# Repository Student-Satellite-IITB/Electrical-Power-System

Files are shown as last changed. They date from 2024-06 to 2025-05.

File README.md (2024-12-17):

# ELECTRICAL POWER SYSTEM

This repository contains all software and hardware for the 
Electrical Power subsystem for the IITBSSP CubeSat mission

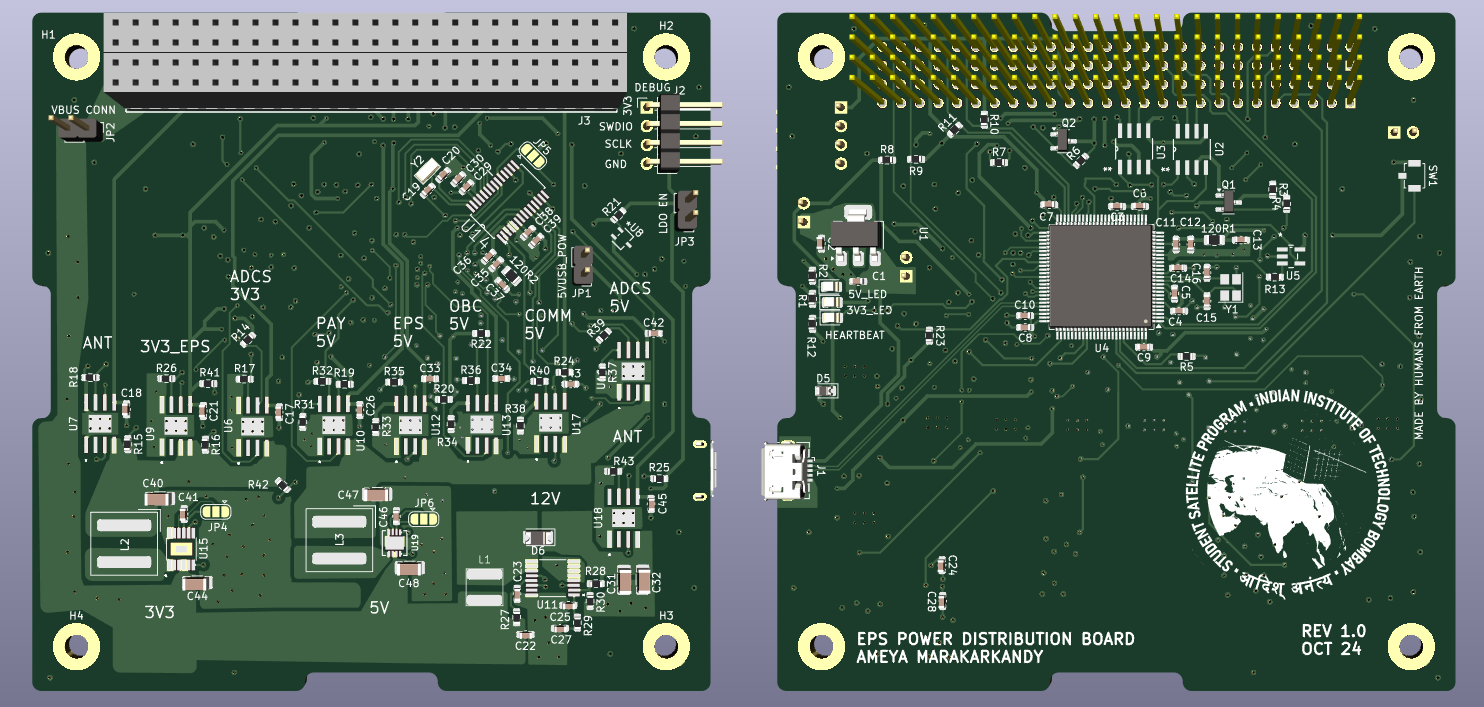
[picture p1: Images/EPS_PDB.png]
EPS Power Distribution Board


Current status: 
- EPS PDB and PMB Assembly
- Battery Unit Development Board
- Power Distribution and Regulation Development Board
- MATLAB/Simulink model of EPS in development
- Testing of Solar Input Development Board
- Testing of Control Unit Development Board

Completed:
- EPS PDB Board Design
- EPS PMB Board Design
- Solar Input Development Board
- EPS Control Unit Development Board

Maintained by:
- Ameya Marakarkandy <ameya.marakarkandy@gmail.com>
- Yash Paritkar <paritkary25@gmail.com>

[SSP Website](https://www.aero.iitb.ac.in/satlab/) | 
[Satellite 101 Wiki](https://www.aero.iitb.ac.in/satelliteWiki/index.php/Satellite_101)

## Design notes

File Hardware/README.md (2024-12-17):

# Electrical Power System Design and Analysis

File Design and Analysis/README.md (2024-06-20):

# Electrical Power System Design and Analysis

### Assumptions
- Mission Definition
- Mission Architecture
- Mission Requirements
### Satellite Preliminary Power Budget
### Power and Energy of Operational Models
### Energy of Scenario Operations
### Definition of Indicators
### EPS Validation

NOTE: This document is a work in progress

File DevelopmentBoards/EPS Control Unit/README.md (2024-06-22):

# EPS Solar Input Unit

Development Board Schematic and PCB Design is complete\
Have sent the PCB for manufacturing\
Yet to order components

Components:
- Molex pico pin connector for input from Solar Panels
- INA232 Current, Volage and Power Measurement with ADC

This document is a work in progress

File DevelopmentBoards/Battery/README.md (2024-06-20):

# EPS Battery Unit

Components:
- BQ29200 for Battery Protection and Cell Balancing
- BQ25713 for Battery Charging

This document is a work in progress

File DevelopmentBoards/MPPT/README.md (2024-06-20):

# EPS Maximum Power Point Tracking Unit

This document is a work in progress

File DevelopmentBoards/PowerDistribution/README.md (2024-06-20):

# EPS Power Regulation and Distribution Unit

This document is a work in progress

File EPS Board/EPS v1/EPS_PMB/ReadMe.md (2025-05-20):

This folder contains the Fusion file of the Power Management Board and the user manual for the testing.

# EPS_PMB_Testing_Manual
_Board Designed by Y.U.P., Oct 2024_

## Description
This PCB will be used as EPS Power Management Board. This board contains the MPPT, battery management and the battery heating unit. This PCB takes power input from the Solar Panels, performs maximum power point tracking and supplies this to the battery management system. Since this is a testing board, option to separate the solar power output and the BMS input is provided is provided.

## Errata
- The resistor R14 should be 137 kOhm.

### Solar Input Unit (SIU)
SIU is implemented with the help of LTC3130 DCDC converters. This IC also offers MPPC which can used as backup with the help of switches. P&O algorithm is used. The P is provided through the EPS uC (from the PDB board) - DAC - OpAmp - FB of the LTC3130. In order to sense the power of the panels, INA232, Current, Voltage and Power Monitor is used. The readings are sent to the EPS uC over the I2C.

All three INA232 have different I2C addresses, which are configured with the A0 pin.

### Battery Management Unit (BMU)
The battery management unit consists of two parts,

1. Battery Management System (BMS) deals with the electrical management of the battery, such as charging protection, OVP, OCP and cell balance.
2. Battery Heater System, which senses the battery temperature and sends the reading to EPS uC, which decides if the heater should be turned ON or OFF.

#### BMS
BMS is implemented with two ICs, BQ25713 I2C Narrow VDC (NVDC) Buck-Boost Battery Charge Controller and BQ29209 charge balancer. The NVDC allows the number of charge cycles of the battery to be minimised. They are implemented according to the standard layout.

#### Battery Heater
The battery temperature is sensed with the help of NTC, which will be attached to the battery and soldered on the board. This is done with a simple biasing circuit. The reading is sensed with ADS1110 and sent to the EPS uC over the I2C line.

The heating coil is wrapped over the battery, and the coil is powered with the VSYS voltage level, which is the BMS output. The coil is controlled with an N channel MOSFET, whose gate signal is received straight from the EPS uC.

### Switches on The Board
In order to allow better testing of the board, several solder switches are provided on the board, and the middle connection is the common terminal; one is '0', and the other is '1'.

The `BMS_SEP` is a jumper connection that separates the SIU and BMU.

> NOTE: Operate SW1 ↔ SW4, SW2 ↔ SW5, SW3 ↔ SW6 together to control the MPPT and MPPC mode.

In MPPC mode, the panels will output 12 V constant.

| Switch | 1 | 0 |
|---|---|---|
|SW1, SW4 | MPPC for 2S panel | MPPT for 2S panel |
|SW2, SW5 | MPPC for 6S panel | MPPT for 6S panel |
|SW3, SW6 | MPPC for 7S panel | MPPT for 7S panel |
|BAT_SEP | Shorted: SIU output shorted with BMU input |

## Testing Procedure

0. Understand the schematics and the layout of the board properly.
1. Do not solder board to the full at once. Solder only what you are testing and in parts.
2. Test the BMU and the SIU separately by keeping the BAT_SEP disconnected.
3. Remember to use the correct I2C addresses.

### Battery Heater Testing
1. Check the biasing of the NTC with the help of DMM.
2. Compare the temperature reading with a good reference.
3. Test the functioning of the ADS1110 IC.
4. Check the switching of the battery heater MOSFET with help of any digital logic.
5. Check the heating of the coil.

### BMU Testing
1. Test the BMU by supplying power with the bench supply of 12 V.
2. Check for features such as overcurrent protection and overvoltage protection.
3. Take readings of the different parameters of the battery with the help of I2C from BQ25713 and verify with the DMM.

### SIU Testing
1. Test the SIU in the MPPC configuration (All switches are low). Drain the power in some dummy load resistors.
2. Check the power generation in different power input levels with the help of the Solar Array Simulator.
3. Change the switch positions to the MPPT mode (All switches are high).
4. Implement the MPPT on a microcontroller and perform PILS.

### Cumulative testing
1. Upon successful testing of both SIU and BMU, short the BMS_SEP.
2. Perform and test for the power path management.

## Possible Failures
- Since the output of the multiple DCDC converters is shorted, this can cause possible instability in the system, and effects such as ringing can be seen.

## Improvements necessary for the next boards
- Addition of deployment switches
- After successful testing of the board, the switches can be eliminated to create a more streamlined board and have a more spacious layout.

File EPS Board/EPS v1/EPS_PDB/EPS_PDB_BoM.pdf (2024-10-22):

Reference | Value | Footprint | Qty | MANUFACTURER_PART_NUMBER DIGIKEY_PART_NUMBER | Price | Total
120R1,120R2 | FerriteBead | Resistor_SMD:R_0805_2012Metric | 2 HI0805O121R-10 | 240-2393-1-ND | ₹ 19.28 | 38.56
C1,C2 | 22uF | Capacitor_SMD:C_0603_1608Metric | 2 | 0
C3,C29,C38 | 10uF | Capacitor_SMD:C_0603_1608Metric | 3 | 0
C4,C5,C6,C7,C8,C9,C10,C14 | 100nF | Capacitor_SMD:C_0603_1608Metric | 8 | 0
C11,C28,C35 | 10nF | Capacitor_SMD:C_0603_1608Metric | 3 | 0
C12,C13,C17,C18,C21,C26,C33,C34,C36,C37,C42,C43 | 1uF | Capacitor_SMD:C_0603_1608Metric | 12 | 0
C15,C16,C19,C20 | 10pF | Capacitor_SMD:C_0603_1608Metric | 4 | 0
C22 | 4.7uF | Capacitor_SMD:C_0603_1608Metric | 1 | 0
C23 | 0.47uF | Capacitor_SMD:C_0603_1608Metric | 1 | 0
C24 | 0.1uF | Capacitor_SMD:C_0603_1608Metric | 1 | 0
C25 | 100pF | Capacitor_SMD:C_0603_1608Metric | 1 | 0
C27 | 3300pF | Capacitor_SMD:C_0603_1608Metric | 1 | 0
C30,C39 | C | Capacitor_SMD:C_0603_1608Metric | 2 | 0
C31,C32 | 4.7uF | Capacitor_SMD:C_1206_3216Metric | 2 | 0
C40,C47 | 47uF | Capacitor_SMD:C_1206_3216Metric | 2 | 0
C41,C46 | 2.2uF | Capacitor_SMD:C_0603_1608Metric | 2 | 0
C44,C48 | 10uF | Capacitor_SMD:C_1206_3216Metric | 2 | 0
C45 | 1uF | Capacitor_SMD:C_1206_3216Metric | 1 | 0
D1 | EPS_5V_LED | LED_SMD:LED_0805_2012Metric | 1 | 0
D2 | EPS_3V3_LED | LED_SMD:LED_0805_2012Metric | 1 | 0
D3 | EPS_LED | LED_SMD:LED_0805_2012Metric | 1 | 0
D4,D5 | D_Schottky | Diode_SMD:D_0805_2012Metric | 2 | 0
D6 | D | Diode_SMD:D_1206_3216Metric | 1 | 0
H1,H2,H3,H4 | MountingHole_Pad | MountingHole:MountingHole_3.2mm_M3_Pad | 4 | 0
J1 | USB_B_Micro | Connector_USB:USB_Micro-B_GCT_USB3076-30-A | 1 USB3076-30-A | 2073-USB3076-30-ACT-ND | ₹ 70.43 | 70.43
J2 | Conn_01x04_Pin | Connector_PinHeader_2.54mm:PinHeader_1x04_P2.54mm_Horizontal | 1 | 0
J3,J4 | Conn_02x26_Odd_Even | PC104_BUS:SAMTEC_ESQ-126-39-G-D | 2 | 0
JP1,JP3 | USB_POW_EN | Connector_PinHeader_2.54mm:PinHeader_1x02_P2.54mm_Vertical | 2 | 0
JP2 | Jumper_2_Bridged | Connector_PinHeader_2.54mm:PinHeader_1x02_P2.54mm_Vertical | 1 | 0
L1 | 8.2uH | Inductor-WE-XHMI-5050:WE-XHMI-5050 | 1 744393305082 | 732-744393305082CT-ND | ₹ 265.77 | 265.77
L2,L3 | 2.2uH | Inductor_SMD:L_Wuerth_WE-XHMI-8080 | 2 74439358022 | 732-7274-1-ND | ₹ 393.21 | 786.42
Q1,Q2 | PMOS | Package_TO_SOT_SMD:SOT-23-3 | 2 BSR92PH6327XTSA1 | BSR92PH6327XTSA1CT-ND | ₹ 46.11 | 92.22
R1,R2,R8,R9,R10,R11,R12 | 1k5 | Resistor_SMD:R_0603_1608Metric | 7 | 0
R3,R6 | 100k | Resistor_SMD:R_0603_1608Metric | 2 | 0
R4,R7 | 100 Resistor_SMD:R_0603_1608Metric | 2 | 0
R5,R14,R15,R16,R18,R19,R20,R22,R23,R24,R25,R41,R42 | 10k | Resistor_SMD:R_0603_1608Metric | 13 | 0
R13 | 0 Resistor_SMD:R_0603_1608Metric | 1 | 0
R17,R26 | 2.2k | Resistor_SMD:R_0603_1608Metric | 2 | 0
R21,R28 | 130k | Resistor_SMD:R_0603_1608Metric | 2 | 0
R27 | 10 Resistor_SMD:R_0603_1608Metric | 1 | 0
R29 | 18k | Resistor_SMD:R_0603_1608Metric | 1 | 0
R30 | 15k | Resistor_SMD:R_0603_1608Metric | 1 | 0
R31,R33,R34,R37,R38 | 400k | Resistor_SMD:R_0603_1608Metric | 5 | 0
R32 | 510 Resistor_SMD:R_0603_1608Metric | 1 | 0
R35,R39,R43 | 560 Resistor_SMD:R_0603_1608Metric | 3 | 0
R36,R40 | 1.3k | Resistor_SMD:R_0603_1608Metric | 2 | 0
SW1 | SW_SPDT | Button_Switch_SMD:SW_SPST_B3U-1100P | 1 B3U-1100P | SW1021CT-ND | ₹ 71.26 | 71.26
U1 | AMS1117-3.3 | Package_TO_SOT_SMD:SOT-223-3_TabPin2 | 1 AMS1117-3.3 | 5272-AMS1117-3.3CT-ND | ₹ 48.63 | 48.63
U2,U3 | SN65HVD256D | SN65HVD256D:D8 | 2 SN65HVD256D | 296-33577-5-ND | ₹ 200.38 | 400.76
U4 | STM32L476VET6 | Package_QFP:LQFP-100_14x14mm_P0.5mm | 1 STM32L476VET6 | 497-15878-ND | ₹ 649.76 | 649.76
U5 | TPS3824-33QDBVRQ1 | TPS3824:tps3824 | 1 TPS3824-33QDBVRQ1 | 296-TPS3824-33QDBVRQ1CT-ND | ₹ 122.41 | 122.41
U6 | TPS259621DDAT 3V3_ADCS TPS259621DDAT:IC_TPS259621DDAT | 1 TPS259621DDAT | 296-TPS259621DDATCT-ND | ₹ 90.55 | 90.55
U7 | TPS259621DDAT_3V3_ANT TPS259621DDAT:IC_TPS259621DDAT | 1 TPS259621DDAT | 296-TPS259621DDATCT-ND | ₹ 90.55 | 90.55
U8 | TS4061BICT-1.25 | TS4061BICT:SOT323-3L_1P35X2P2X0P65_STM | 1 TS4061BICT-1.25 | 497-15526-1-ND | ₹ 81.32 | 81.32
U9 | TPS259621DDAT_3V3_EPS | TPS259621DDAT:IC_TPS259621DDAT | 1 TPS259621DDAT | 296-TPS259621DDATCT-ND | ₹ 90.55 | 90.55
U10 | TPS259621DDAT_5V_PAY | TPS259621DDAT:IC_TPS259621DDAT | 1 TPS259621DDAT | 296-TPS259621DDATCT-ND | ₹ 90.55 | 90.55
U11 | LM5000-3MTCX | LM500:SOP65P640X120-16N | 1 LM5000-3MTCX/NOPB | 296-35284-1-ND | ₹ 441.00 | 441
U12 | TPS259621DDAT_5V_EPS | TPS259621DDAT:IC_TPS259621DDAT | 1 TPS259621DDAT | 296-TPS259621DDATCT-ND | ₹ 90.55 | 90.55
U13 | TPS259621DDAT_5V_OBC | TPS259621DDAT:IC_TPS259621DDAT | 1 TPS259621DDAT | 296-TPS259621DDATCT-ND | ₹ 90.55 | 90.55
U14 | AD7708BRUZ | AD7708BRUZ:SOP65P638X110-28N | 1 AD7708BRUZ | AD7708BRUZ-ND | ₹ 1,167.05 1167.05
U15 | LTC3624EMSE-3.3PBF | LTC3624EMSE-3.3PBF:SOP65P490X110-13N | 1 LTC3624EMSE-3.3#PBF | LTC3624EMSE-3.3#PBF-ND | ₹ 856.84 | 856.84
U16 | TPS259621DDAT_5V_ADCS | TPS259621DDAT:IC_TPS259621DDAT | 1 TPS259621DDAT | 296-TPS259621DDATCT-ND | ₹ 90.55 | 90.55
U17 | TPS259621DDAT_5V_COMM TPS259621DDAT:IC_TPS259621DDAT | 1 TPS259621DDAT | 296-TPS259621DDATCT-ND | ₹ 90.55 | 90.55
U18 | TPS259621DDAT_12V_ADCS TPS259621DDAT:IC_TPS259621DDAT | 1 TPS259621DDAT | 296-TPS259621DDATCT-ND | ₹ 90.55 | 90.55
U19 | LTC3624IDD-25PBF | LTC3624IDD-25PBF:DFN-8_DD | 1 LTC3624IDD-25#PBF | LTC3624IDD-25#PBF-ND | ₹ 921.40 | 921.4
Y1 | 32MHz | Crystal:Crystal_SMD_Abracon_ABM8AIG-4Pin_3.2x2.5mm | 1 ABM8X-102-32.000MHZ-T | 535-11454-1-ND | ₹ 561.73 | 561.73
Y2 | 32.768kHz | Crystal:Crystal_SMD_3215-2Pin_3.2x1.5mm | 1 ABS07-32.768KHZ-T | 535-9542-1-ND | ₹ 54.50 | 54.5
7445.01

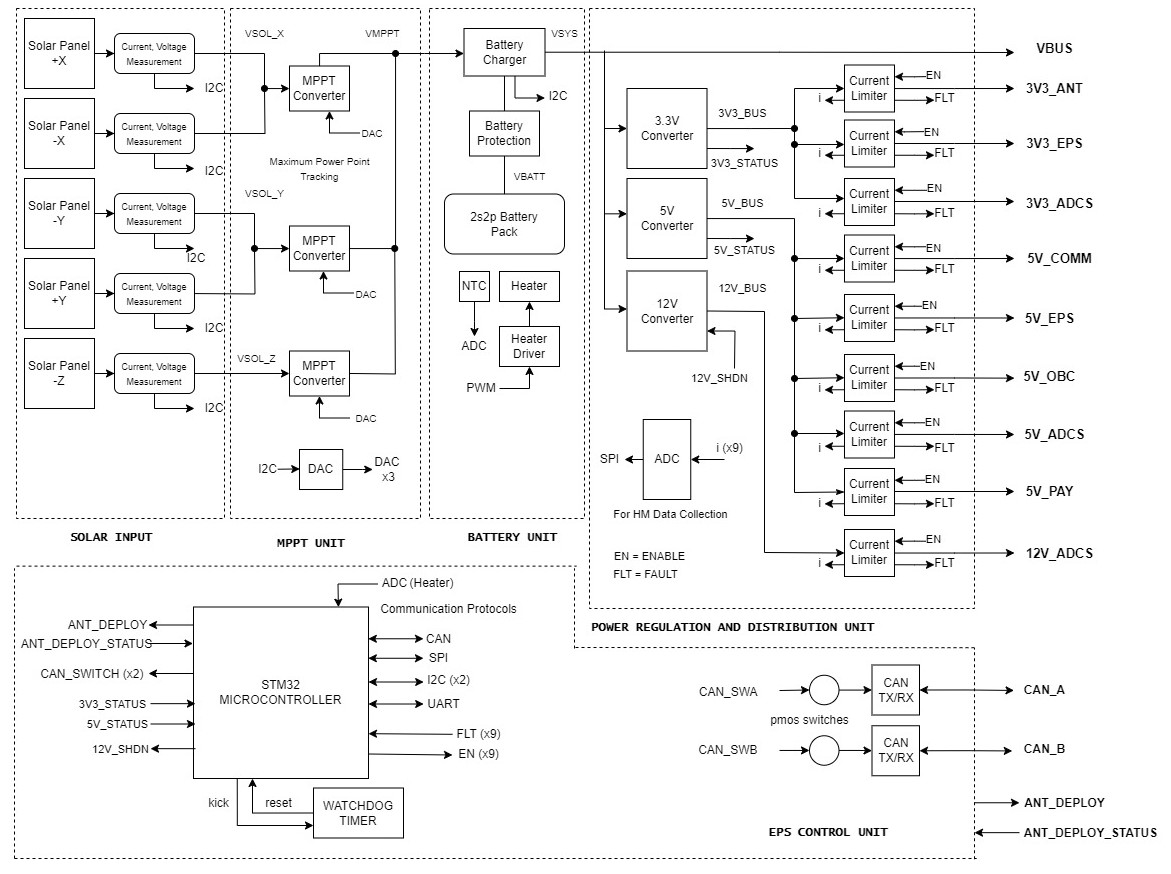
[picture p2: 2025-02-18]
Images/EPS_Architecture.jpg

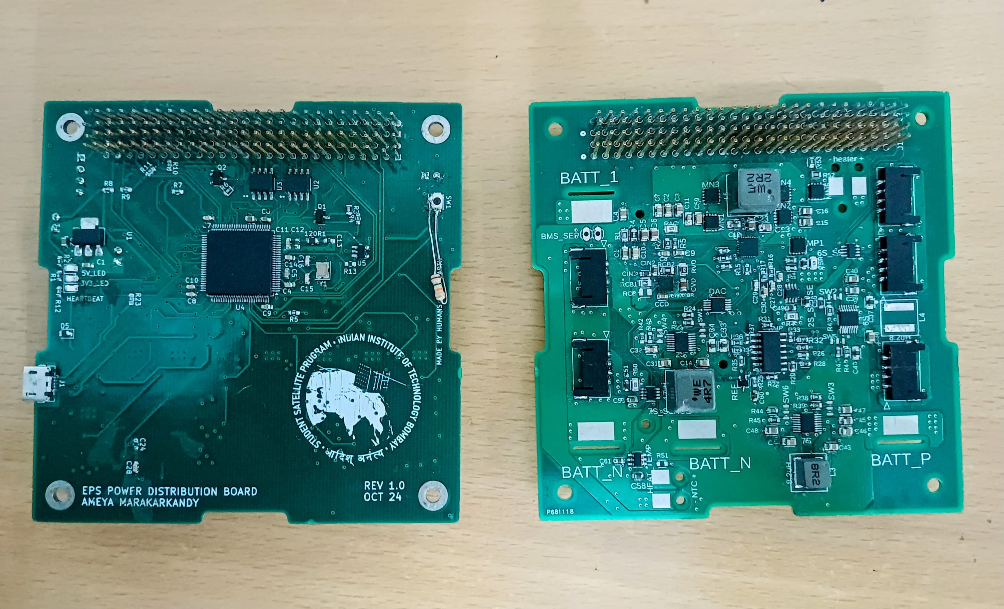
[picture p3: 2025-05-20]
Images/EPS_Boards.jpg

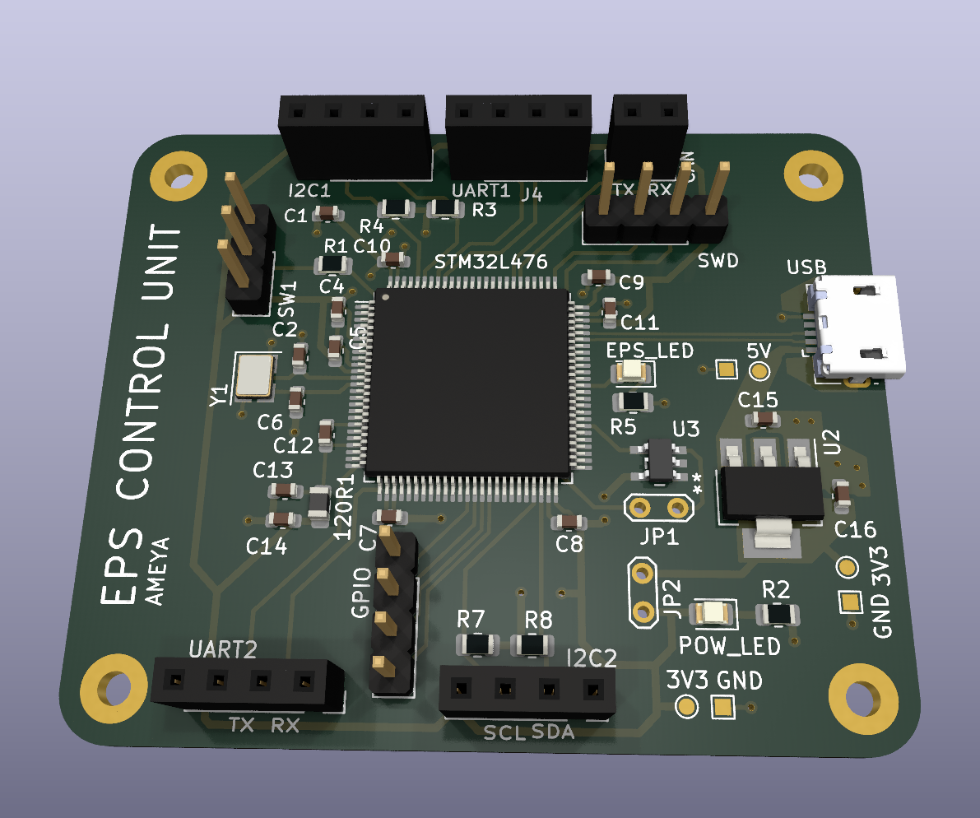
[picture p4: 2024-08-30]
Images/EPS_ControlUnit.png

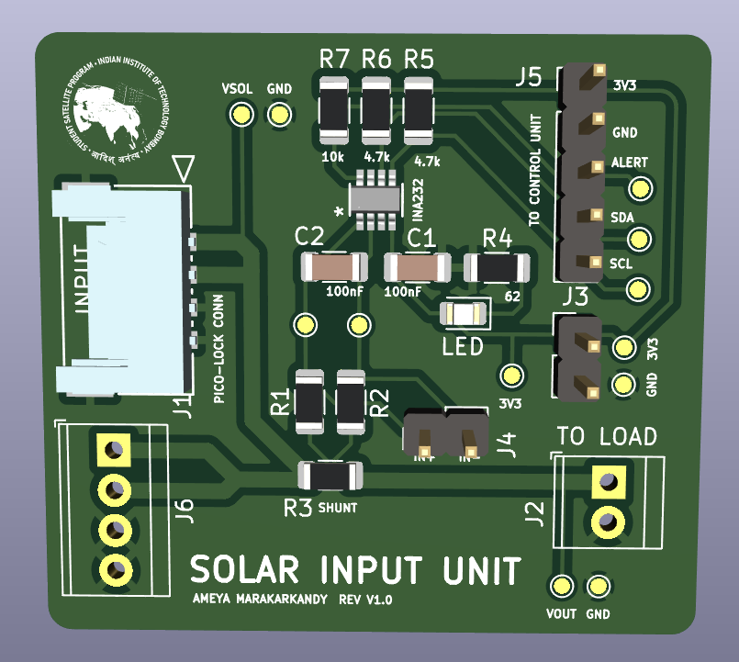
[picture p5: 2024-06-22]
Images/EPS_SolarInput.png

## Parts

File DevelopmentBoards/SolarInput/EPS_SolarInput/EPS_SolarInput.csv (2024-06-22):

Source: | C:\Users\Ameya\Documents\IITBSSP\GitHub\Electrical-Power-System\DevelopmentBoards\SolarInput\EPS_SolarInput\EPS_SolarInput.kicad_sch
Date: | 23-06-2024 03:58
Tool: | Eeschema 7.0.2
Generator: | C:\Program Files\KiCad\7.0\bin\scripting\plugins/bom_csv_grouped_by_value.py
Component Count: | 29
Collated Components:
Item | Qty | Reference(s) | Value | LibPart | Footprint | Price | Total Price | Link
1 | 2 | C1, C2 | 100nF | Device:C | Capacitor_SMD:C_1206_3216Metric | 30.5 | 61 | https://in.element14.com/murata/gcj31cr72e104kxj3l/cap-0-10uf-250vdc-mlcc-1206/dp/3243156
2 | 1 | D1 | LED | Device:LED | LED_SMD:LED_0805_2012Metric | 34 | 34 | https://in.element14.com/lumex/sml-lxt0805syw-tr/led-yell-1-4x1-25mm-60mcd-590nm/dp/2062311
3 | 1 | J1 | 2053380004 | Molex-Pico-Lock-Conn:2053380004 | Molex-PicoLock_FootprintLib:CON_2053380004 |  | 0
4 | 1 | J2 | Screw_Terminal_01x02 | Connector:Screw_Terminal_01x02 | TerminalBlock_TE-Connectivity:TerminalBlock_TE_282834-2_1x02_P2.54mm_Horizontal |  | 0
5 | 2 | J3, J4 | Conn_01x02_Socket | Connector:Conn_01x02_Socket | Connector_PinHeader_2.54mm:PinHeader_1x02_P2.54mm_Vertical |  | 0
6 | 1 | J5 | Conn_01x05_Pin | Connector:Conn_01x05_Pin | Connector_PinHeader_2.54mm:PinHeader_1x05_P2.54mm_Vertical |  | 0
7 | 1 | J6 | Screw_Terminal_01x04 | Connector:Screw_Terminal_01x04 | TerminalBlock_TE-Connectivity:TerminalBlock_TE_282834-4_1x04_P2.54mm_Horizontal |  | 0
8 | 2 | R1, R2 | <100 | Device:R | Resistor_SMD:R_1206_3216Metric |  | 0
9 | 1 | R3 | 40m | Device:R | Resistor_SMD:R_1206_3216Metric |  | 0
10 | 1 | R4 | 62 | Device:R | Resistor_SMD:R_1206_3216Metric |  | 0
11 | 2 | R5, R6 | 4.7k | Device:R | Resistor_SMD:R_1206_3216Metric |  | 0
12 | 1 | R7 | 10k | Device:R | Resistor_SMD:R_1206_3216Metric |  | 0
13 | 12 | TP1, TP2, TP3, TP4, TP5, TP6, TP7, TP8, TP9, TP10, TP11, TP12 | TestPoint | Connector:TestPoint | TestPoint:TestPoint_Pad_D1.0mm |  | 0
14 | 1 | U1 | INA232AIDDFR | EPS_SymbolLib:INA232AIDDFR | INA232_FootprintLib:SOT_32AIDDFR_TEX |  | 0

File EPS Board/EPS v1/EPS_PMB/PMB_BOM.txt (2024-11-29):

Partlist exported from C:/Users/harsh/AppData/Local/Temp/Neutron/ElectronFileOutput/9460/sch-f3af5b30-faf7-4b7a-940b-98f68ccd31e9/PMB v1.sch at 25-11-2024 19:25

Part      Value                                        Device                                       Footprint Name                Detailed Description       AVAILABILITY CATEGORY  CHECK_PRICES                                                                   COPYRIGHT                                                DATASHEET-URL                                           DESCRIPTION                                                                             FRES  IRP    ISAT1  ISAT2      MANUFACTURER MANUFACTURER_PART_NUMBER MF                MFR_NAME                    MOUNT MP          MPN     OPERATING_TEMP OPERATING_TEMPERATURE PACKAGE                  PART-NUMBER   PART_STATUS PITCH           PRICE PURCHASE-URL                                                                                                                                       RATING RDC      ROHS_COMPLIANCE ROHS_COMPLIANT SERIES  SIZE   SNAPEDA_LINK                                                                    SUB-CATEGORY       THERMALLOSS TOLERANCE TYPE                                                        VALUE     VOLTAGE_RATING
2S        LTC3130EMSEPBFMSE_16_ADI-M                   LTC3130EMSEPBFMSE_16_ADI-M                   MSE_16_ADI-M                                                                                                                                                   Copyright (C) 2024 Ultra Librarian. All rights reserved.                                                                                                                                                                                             LTC3130EMSE#PBF                            Analog Devices Inc                                                                                                                                                                                                                                                                                                                                                                                                                                                                                                                                                                                
2S_0      2053380004CON_2053380004                     2053380004CON_2053380004                     CON_2053380004                                                                                                                                                 Copyright (C) 2024 Ultra Librarian. All rights reserved.                                                                                                                                                                                             2053380004                                 Molex Connector Corporation                                                                                                                                                                                                                                                                                                                                                                                                                                                                                                                                                                       
2S_1      2053380004CON_2053380004                     2053380004CON_2053380004                     CON_2053380004                                                                                                                                                 Copyright (C) 2024 Ultra Librarian. All rights reserved.                                                                                                                                                                                             2053380004                                 Molex Connector Corporation                                                                                                                                                                                                                                                                                                                                                                                                                                                                                                                                                                       
2S_SENSE  INA232AIDDFRSOT_32AIDDFR_TEX-M               INA232AIDDFRSOT_32AIDDFR_TEX-M               SOT_32AIDDFR_TEX-M                                                                                                                                             Copyright (C) 2024 Ultra Librarian. All rights reserved.                                                                                                                                                                                             INA232AIDDFR                               Texas Instruments                                                                                                                                                                                                                                                                                                                                                                                                                                                                                                                                                                                 
6S        LTC3130EMSEPBFMSE_16_ADI-M                   LTC3130EMSEPBFMSE_16_ADI-M                   MSE_16_ADI-M                                                                                                                                                   Copyright (C) 2024 Ultra Librarian. All rights reserved.                                                                                                                                                                                             LTC3130EMSE#PBF                            Analog Devices Inc                                                                                                                                                                                                                                                                                                                                                                                                                                                                                                                                                                                
6S_0      2053380004CON_2053380004                     2053380004CON_2053380004                     CON_2053380004                                                                                                                                                 Copyright (C) 2024 Ultra Librarian. All rights reserved.                                                                                                                                                                                             2053380004                                 Molex Connector Corporation                                                                                                                                                                                                                                                                                                                                                                                                                                                                                                                                                                       
6S_SENSE  INA232AIDDFRSOT_32AIDDFR_TEX-M               INA232AIDDFRSOT_32AIDDFR_TEX-M               SOT_32AIDDFR_TEX-M                                                                                                                                             Copyright (C) 2024 Ultra Librarian. All rights reserved.                                                                                                                                                                                             INA232AIDDFR                               Texas Instruments                                                                                                                                                                                                                                                                                                                                                                                                                                                                                                                                                                                 
7S        LTC3130EMSEPBFMSE_16_ADI-M                   LTC3130EMSEPBFMSE_16_ADI-M                   MSE_16_ADI-M                                                                                                                                                   Copyright (C) 2024 Ultra Librarian. All rights reserved.                                                                                                                                                                                             LTC3130EMSE#PBF                            Analog Devices Inc                                                                                                                                                                                                                                                                                                                                                                                                                                                                                                                                                                                
7S_0      2053380004CON_2053380004                     2053380004CON_2053380004                     CON_2053380004                                                                                                                                                 Copyright (C) 2024 Ultra Librarian. All rights reserved.                                                                                                                                                                                             2053380004                                 Molex Connector Corporation                                                                                                                                                                                                                                                                                                                                                                                                                                                                                                                                                                       
7S_1      2053380004CON_2053380004                     2053380004CON_2053380004                     CON_2053380004                                                                                                                                                 Copyright (C) 2024 Ultra Librarian. All rights reserved.                                                                                                                                                                                             2053380004                                 Molex Connector Corporation                                                                                                                                                                                                                                                                                                                                                                                                                                                                                                                                                                       
7S_SENSE  INA232AIDDFRSOT_32AIDDFR_TEX-M               INA232AIDDFRSOT_32AIDDFR_TEX-M               SOT_32AIDDFR_TEX-M                                                                                                                                             Copyright (C) 2024 Ultra Librarian. All rights reserved.                                                                                                                                                                                             INA232AIDDFR                               Texas Instruments                                                                                                                                                                                                                                                                                                                                                                                                                                                                                                                                                                                 
AMP       TLV9004IDRD14_TEX-M                          TLV9004IDRD14_TEX-M                          D14_TEX-M                                                                                                                                                      Copyright (C) 2024 Ultra Librarian. All rights reserved.                                                                                                                                                                                             TLV9004IDR                                 Texas Instruments                                                                                                                                                                                                                                                                                                                                                                                                                                                                                                                                                                                 
BMS_SEP   PINHD-1X2                                    PINHD-1X2                                    1X02                          PIN HEADER                              Headers                                                                                                                                                                                                   Header, Straight, 2 Position                                                                                           Generic                                                                                               Generic                Generic                                                      Active      0.100" (2.54mm)                                                                                                                                                                          Generic                        Generic                                                                                        Headers, Male Pins                       Board to Board or Cable, Unshrouded, Through Hole, Straight PINHD-1X2               
C1        1u                                           C_CHIP-0805(2012-METRIC)                     CAPC2012X110                  Capacitor - Generic                     Capacitor                                                                                                                                                                                                                                                                                                                                                                                                                                                                                                                                                                                                                                                                                                                                                                                                                                                                                                                                                                                  
C2        10u                                          C_CHIP-0805(2012-METRIC)                     CAPC2012X110                  Capacitor - Generic                     Capacitor                                                                                                                                                                                                                                                                                                                                                                                                                                                                                                                                                                                                                                                                                                                                                                                                                                                                                                                                                                                  
C3        10u                                          C_CHIP-0805(2012-METRIC)                     CAPC2012X110                  Capacitor - Generic                     Capacitor                                                                                                                                                                                                                                                                                                                                                                                                                                                                                                                                                                                                                                                                                                                                                                                                                                                                                                                                                                                  
C4        10u                                          C_CHIP-0805(2012-METRIC)                     CAPC2012X110                  Capacitor - Generic                     Capacitor                                                                                                                                                                                                                                                                                                                                                                                                                                                                                                                                                                                                                                                                                                                                                                                                                                                                                                                                                                                  
C5        10u                                          C_CHIP-0805(2012-METRIC)                     CAPC2012X110                  Capacitor - Generic                     Capacitor                                                                                                                                                                                                                                                                                                                                                                                                                                                                                                                                                                                                                                                                                                                                                                                                                                                                                                                                                                                  
C6        10u                                          C_CHIP-0805(2012-METRIC)                     CAPC2012X110                  Capacitor - Generic                     Capacitor                                                                                                                                                                                                                                                                                                                                                                                                                                                                                                                                                                                                                                                                                                                                                                                                                                                                                                                                                                                  
C7        10u                                          C_CHIP-0805(2012-METRIC)                     CAPC2012X110                  Capacitor - Generic                     Capacitor                                                                                                                                                                                                                                                                                                                                                                                                                                                                                                                                                                                                                                                                                                                                                                                                                                                                                                                                                                                  
C8        33n                                          C_CHIP-0603(1608-METRIC)                     CAPC1608X85                   Capacitor - Generic                     Capacitor                                                                                                                                                                                                                                                                                                                                                                                                                                                                                                                                                                                                                                                                                                                                                                                                                                                                                                                                                                                  
C9        33n                                          C_CHIP-0603(1608-METRIC)                     CAPC1608X85                   Capacitor - Generic                     Capacitor                                                                                                                                                                                                                                                                                                                                                                                                                                                                                                                                                                                                                                                                                                                                                                                                                                                                                                                                                                                  
C10       470n                                         C_CHIP-0805(2012-METRIC)                     CAPC2012X110                  Capacitor - Generic                     Capacitor                                                                                                                                                                                                                                                                                                                                                                                                                                                                                                                                                                                                                                                                                                                                                                                                                                                                                                                                                                                  
C11       10n                                          C_CHIP-0805(2012-METRIC)                     CAPC2012X110                  Capacitor - Generic                     Capacitor                                                                                                                                                                                                                                                                                                                                                                                                                                                                                                                                                                                                                                                                                                                                                                                                                                                                                                                                                                                  
C12       47n                                          C_CHIP-0805(2012-METRIC)                     CAPC2012X110                  Capacitor - Generic                     Capacitor
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

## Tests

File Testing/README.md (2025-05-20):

# EPS Testing

## MPPT LabVIEW PILS
Developed a s a part of a course project for AE501 Virtual Instrumentation \
Directory Structure
- TEST\
Contains source code for simple P&O Implementation on STM32 Nucleo board
- MPPT PILS\
Contains LabVIEW code for running the PILS

NOTE: This document is a work in progress

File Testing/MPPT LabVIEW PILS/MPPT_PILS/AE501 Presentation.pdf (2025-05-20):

Presented by:
Arushi Bansal (210041001)
Ameya Bijith Marakarkandy (21d180003)

Under the guidance of:
Prof. T. Chandra Sekar

## Course Project: Implementation of MPPT in a CubeSat Electrical Power System Using STM32 and LabVIEW-based PIL Testing

AE 501 Virtual Instrumentation for Aerospace Engineers

AE 501: Virtual Instrumentation for Aerospace Engineers

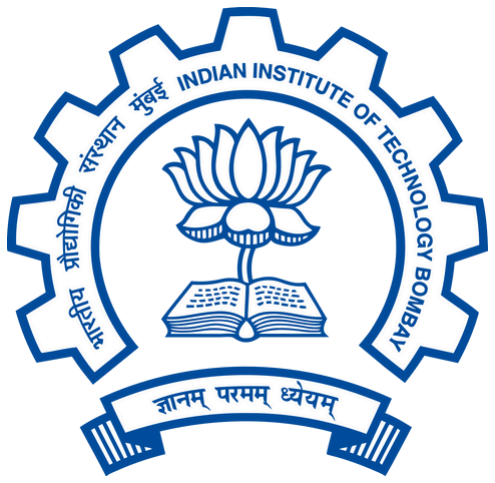
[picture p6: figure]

# Electrical Power System (EPS): The Lifeline of a CubeSat

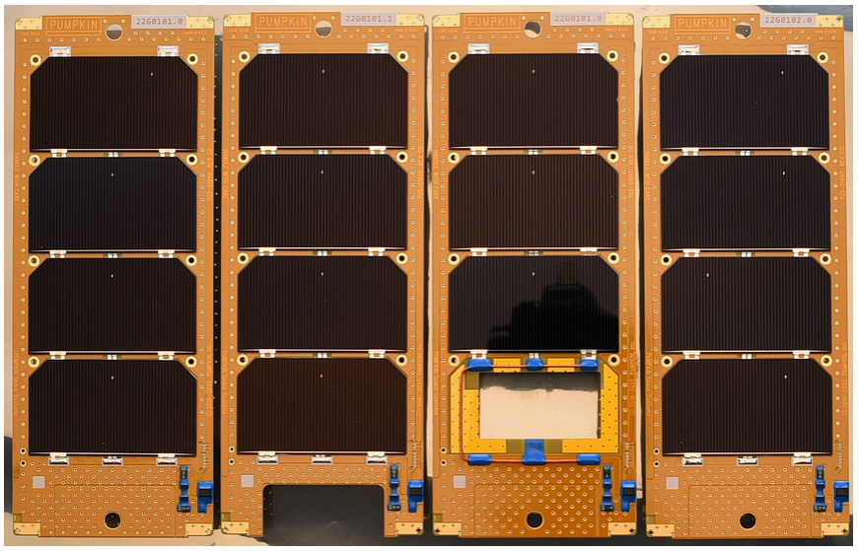
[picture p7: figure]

Powers all satellite subsystems: ADCS, OBC, Communications, Payload, etc.
Limited surface area for solar panels → low power budget
Must ensure autonomous, reliable, and efficient power regulation
Failure of EPS = complete mission loss

The EPS is crucial in CubeSats as it manages limited power within tight size and weight constraints, ensuring efficient energy use and reliable operation of all subsystems.

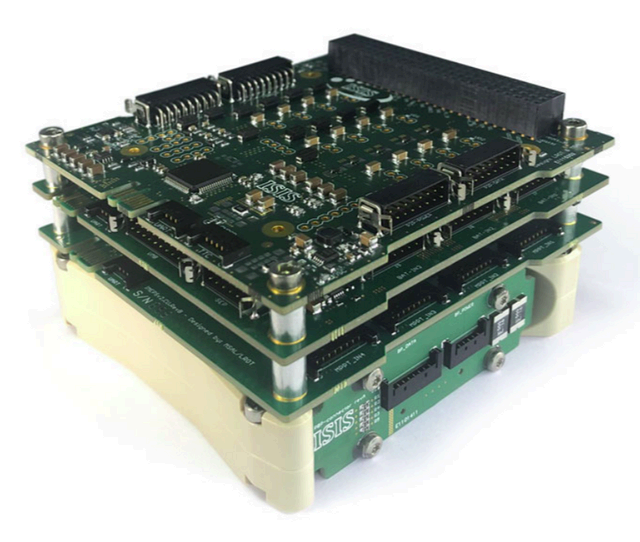
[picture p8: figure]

# Solar Cells

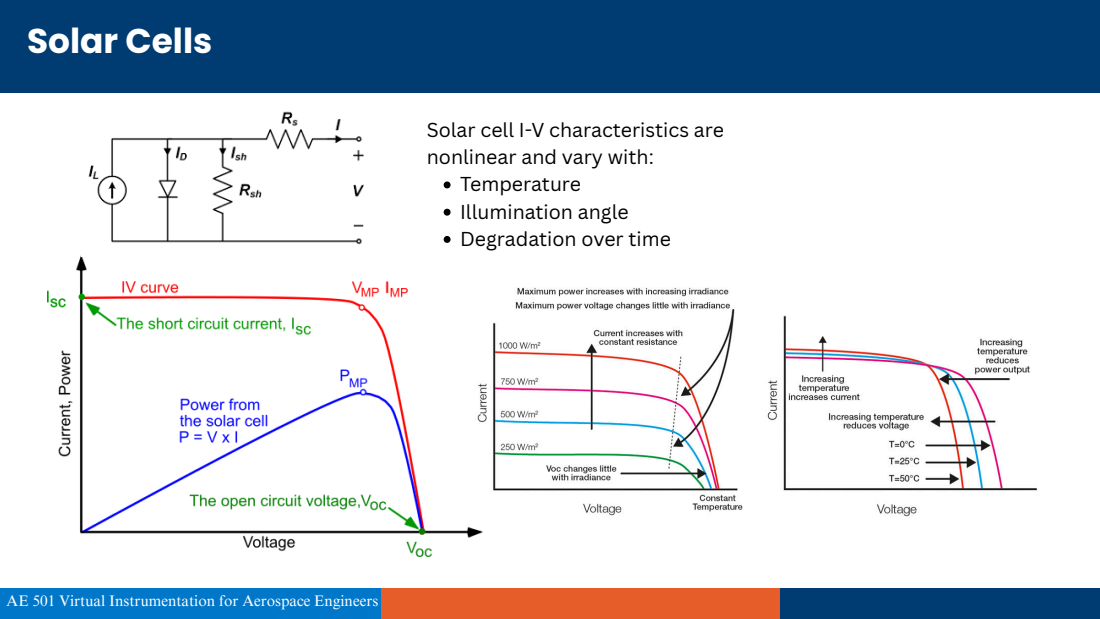
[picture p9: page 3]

Solar cell I-V characteristics are
nonlinear and vary with:
Temperature
Illumination angle
Degradation over time

# Maximum Power Point Tracking (MPPT)

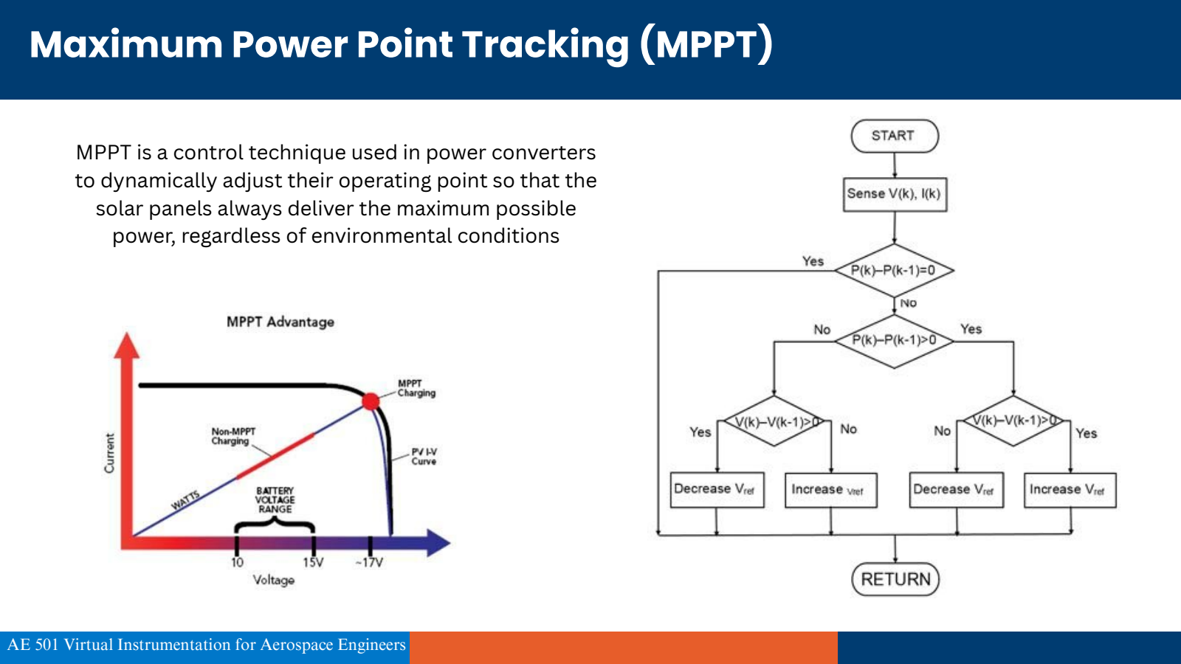
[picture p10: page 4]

MPPT is a control technique used in power converters to dynamically adjust their operating point so that the solar panels always deliver the maximum possible power, regardless of environmental conditions

# Our Problem

The EPS is crucial in CubeSats as it manages limited power within tight size and weight constraints, ensuring efficient energy use and reliable operation of all subsystems.Orbital conditions cause rapid fluctuations in solar irradiance and temperature, significantly affecting power output. The Maximum Power Point Tracking (MPPT) algorithm optimizes energy extraction from solar arrays under these dynamic conditions. Testing MPPT algorithms directly onboard a satellite introduces significant risks and high costs, necessitating reliable ground-based testing methods.
Processor-In-the-Loop Simulation (PILS) offers a solution by virtually simulating orbital conditions or utilizing real sensor data, enabling thorough and cost-effective validation of EPS systems without the risks of physical deployment.

## Hardware Architecture

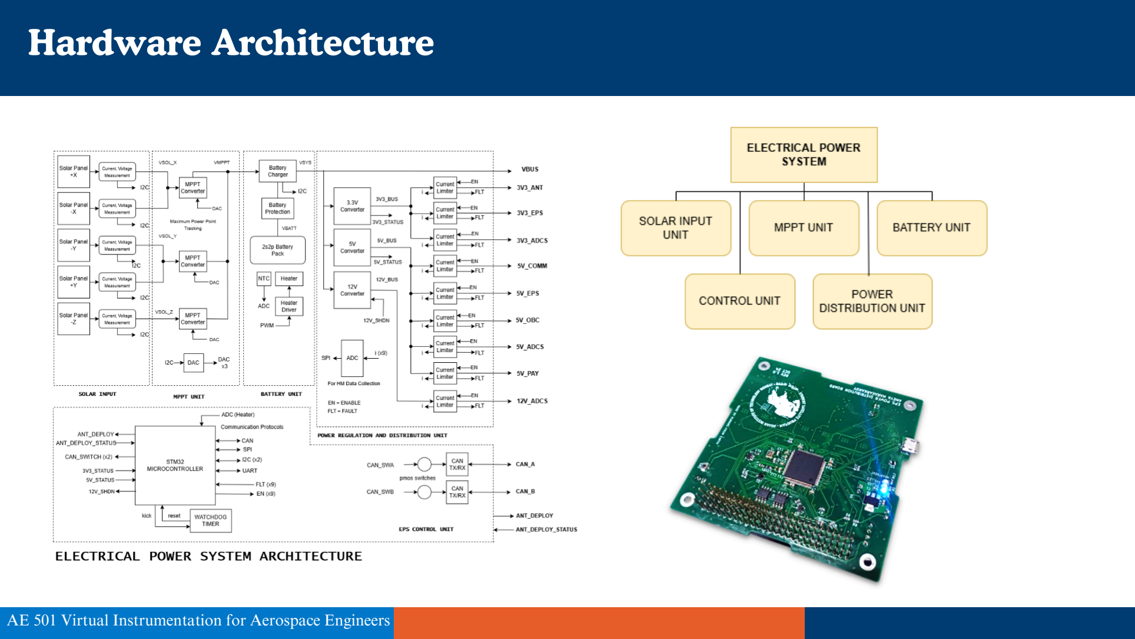
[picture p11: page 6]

# EPS Control Unit

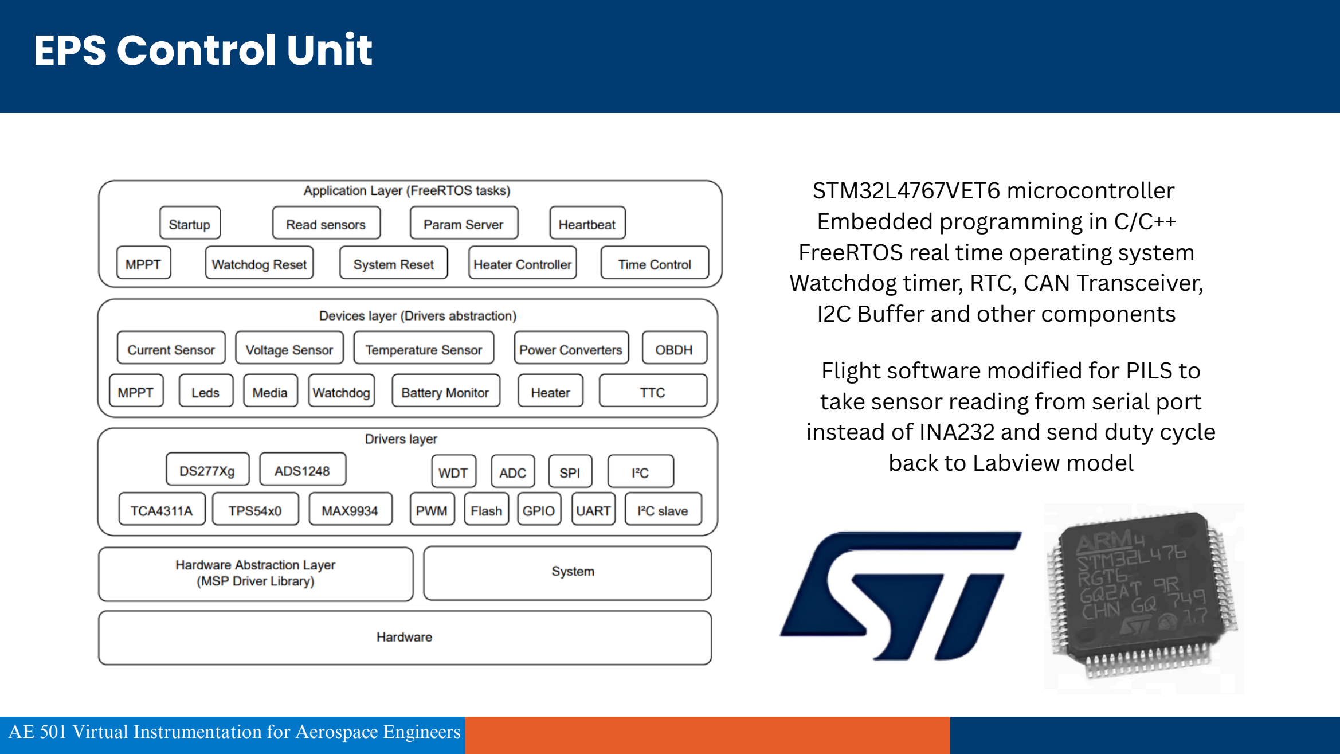
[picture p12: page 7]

STM32L4767VET6 microcontroller Embedded programming in C/C++ FreeRTOS real time operating system Watchdog timer, RTC, CAN Transceiver, I2C Buffer and other components

Flight software modified for PILS to take sensor reading from serial port instead of INA232 and send duty cycle back to Labview model

# PILS ARCHITECTURE

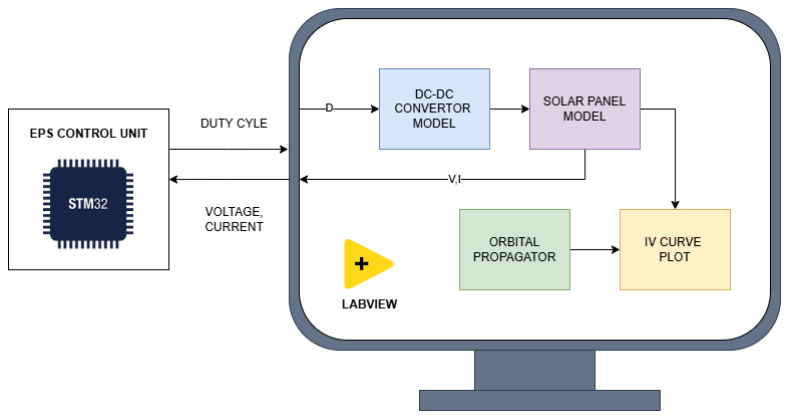
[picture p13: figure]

## Calculations

## Array Generations for Graph

### Voltage Array

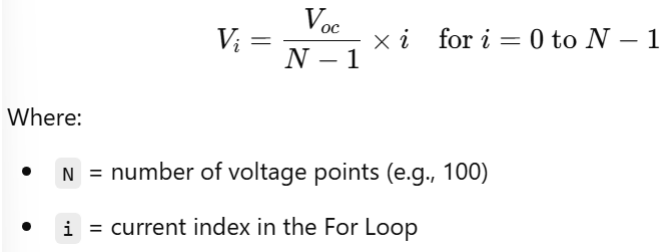
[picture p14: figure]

Automatically handled in labview using ramp pattern.vi

## Calculations

## Array Generations for Graph

Current Calculation | Power Calculation

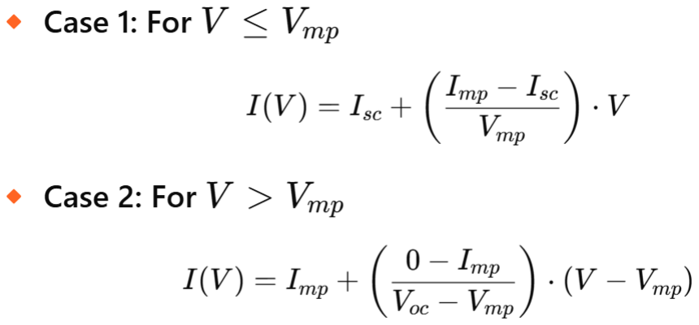
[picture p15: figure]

Parameter | Value | Explanation
G_STC | 1367 W/m^2 | Solar constant (irradiance at standard test conditions)
T_STC | 301 K | Cell temperature at STC
β (Beta angle) | 0° | Orbit normal is perpendicular to sun vector (simplifies θ calculation)
T_base | 260 K | Base satellite cell temperature in shadow
ΔT (rise at full sunlight) | 40 K | Estimated heating from full irradiance
α_I | +0.0005 /K | Current temperature coefficient
β_V | -0.0022 V/K | Voltage temperature coefficient

## Calculations

## Orbital Solar Panel Simulation

### Assumptions & Given values

Parameter | Value | Explanation
n | 1.2 | Diode ideality factor
k | 1.380649×10−23 J/K | Boltzmann constant
q | 1.602×10 −19 C | Charge of electron
Earth Radius (R_E) | 6.371 x 10^6 m

G
(Gravitational Constant) | 6.674 x 10^-11
M (Earth Mass) | 5.972 x 10^24

## Calculations

## Orbital Solar Panel Simulation

### Orbital Period


### Satellite Sun Angle (θ) Over Time

### Projected Solar Irradiance


## Calculations

## Orbital Solar Panel Simulation


### Solar cell temperature

### IV Characterestics

## Labview Program


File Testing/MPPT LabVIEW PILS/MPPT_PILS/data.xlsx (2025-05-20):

Time | Untitled
16:32:58 | 0.725022
16:32:58 | 0.725022
16:32:58 | 0.725022
16:32:58 | 0.880971
16:32:59 | 0.880971
16:32:59 | 0.880971
16:32:59 | 0.88097
16:32:59 | 0.889439
16:33:00 | 0.889439
16:33:00 | 0.909186
16:33:00 | 0.909185
16:33:00 | 0.909184
16:33:01 | 0.923276
16:33:01 | 0.923275
16:33:01 | 0.923275
16:33:01 | 0.923274
16:33:01 | 0.937354
16:33:02 | 0.937353
16:33:02 | 0.937352
16:33:02 | 0.937351
16:33:02 | 0.951421
16:33:03 | 0.95142
16:33:03 | 0.951419
16:33:03 | 0.965478
16:33:03 | 0.965476
16:33:03 | 0.965475
16:33:04 | 0.965473
16:33:04 | 0.979521
16:33:04 | 0.97952
16:33:04 | 0.979518
16:33:05 | 0.979516
16:33:05 | 0.987939
16:33:05 | 0.987937
16:33:05 | 0.987935
16:33:06 | 1.007575
16:33:06 | 1.007573
16:33:06 | 1.007571
16:33:06 | 1.007568
16:33:06 | 1.021583
16:33:07 | 1.021581
16:33:07 | 1.021578
16:33:07 | 1.021576
16:33:07 | 1.03558
16:33:08 | 1.035577
16:33:08 | 1.035574
16:33:08 | 1.049568
16:33:08 | 1.049565
16:33:08 | 1.049562
16:33:09 | 1.049559
16:33:09 | 1.063541
16:33:09 | 1.063537
16:33:09 | 1.077509
16:33:10 | 1.077505
16:33:10 | 1.077502
16:33:10 | 1.091462
16:33:10 | 1.091458
16:33:11 | 1.091454
16:33:11 | 1.09145
16:33:11 | 1.105399
16:33:11 | 1.105395
16:33:11 | 1.105391
16:33:12 | 1.105386
16:33:12 | 1.119324
16:33:12 | 1.11932
16:33:12 | 1.133247
16:33:13 | 1.133242
16:33:13 | 1.133238
16:33:13 | 1.147154
16:33:13 | 1.147148
16:33:14 | 1.147143
16:33:14 | 1.147138
16:33:14 | 1.161042
16:33:14 | 1.161037
16:33:15 | 1.161031
16:33:15 | 1.161026
16:33:15 | 1.17214
16:33:15 | 1.172134
16:33:16 | 1.188795
16:33:16 | 1.188789
16:33:16 | 1.202661
16:33:16 | 1.202654
16:33:16 | 1.18877
16:33:17 | 1.188764
16:33:17 | 1.188758
16:33:17 | 1.202629
16:33:17 | 1.202622
16:33:18 | 1.202615
16:33:18 | 1.202609
16:33:18 | 1.216468
16:33:18 | 1.216461
16:33:19 | 1.216454
16:33:19 | 1.216446
16:33:19 | 1.21921
16:33:19 | 1.219203
16:33:20 | 1.244123
16:33:20 | 1.244115
16:33:20 | 1.257942
16:33:20 | 1.257933
16:33:20 | 1.257925
16:33:21 | 1.27174
16:33:21 | 1.271731
16:33:21 | 1.271723
16:33:21 | 1.271714
16:33:22 | 1.230824
16:33:22 | 1.230816
16:33:22 | 1.252634
16:33:22 | 1.252625
16:33:23 | 1.271671
16:33:23 | 1.271662
16:33:23 | 1.230772
16:33:23 | 1.230764
16:33:23 | 1.119987
16:33:24 | 1.119978
16:33:24 | 1.11997
16:33:24 | 1.230727
16:33:24 | 1.230718
16:33:25 | 1.230708
16:33:25 | 1.230699
16:33:25 | 1.271567
16:33:25 | 1.271557
16:33:26 | 1.271547
16:33:26 | 1.271537
16:33:26 | 1.257706
16:33:26 | 1.257695
16:33:27 | 1.271506
16:33:27 | 1.271495
16:33:27 | 1.271484
16:33:27 | 1.230598
16:33:28 | 1.230588
16:33:28 | 1.230577
16:33:28 | 1.230566
16:33:28 | 1.271428
16:33:28 | 1.271417
16:33:29 | 1.271406
16:33:29 | 1.271395
16:33:29 | 1.257564
16:33:29 | 1.257553
16:33:30 | 1.257542
16:33:30 | 1.25753
16:33:30 | 1.271336
16:33:30 | 1.271324
16:33:31 | 1.263131
16:33:31 | 1.263118
16:33:31 | 1.119681
16:33:31 | 1.119669
16:33:32 | 1.230393
16:33:32 | 1.230381
16:33:32 | 1.271236
16:33:32 | 1.271223
16:33:33 | 1.271211
16:33:33 | 1.257381
16:33:33 | 1.257368
16:33:33 | 1.257355
16:33:33 | 1.257342
16:33:34 | 1.271146
16:33:34 | 1.271133
16:33:34 | 1.271119
16:33:34 | 1.271106
16:33:35 | 1.252046
16:33:35 | 1.252033
16:33:35 | 1.119485
16:33:35 | 1.119472
16:33:36 | 1.230176
16:33:36 | 1.230162
16:33:36 | 1.119435
16:33:36 | 1.119422
16:33:37 | 1.005964
16:33:37 | 1.005952
16:33:37 | 1.119383
16:33:37 | 1.11937
16:33:38 | 1.119357
16:33:38 | 1.230049
16:33:38 | 1.230035
16:33:38 | 1.23002
16:33:39 | 1.230005
16:33:39 | 1.270844
16:33:39 | 1.27083
16:33:39 | 1.270815
16:33:39 | 1.270799
16:33:40 | 1.256971
16:33:40 | 1.256954
16:33:40 | 1.270752
16:33:40 | 1.270735
16:33:41 | 1.2721
16:33:41 | 1.272085
16:33:41 | 1.229839
16:33:41 | 1.229823
16:33:42 | 1.270655
16:33:42 | 1.270638
16:33:42 | 1.25681
16:33:42 | 1.256795
16:33:43 | 1.256778
16:33:43 | 1.270571
16:33:43 | 1.270555
16:33:43 | 1.270538
16:33:44 | 1.270521
16:33:44 | 1.229661
16:33:44 | 1.229645
16:33:44 | 1.229629
16:33:45 | 1.229612
16:33:45 | 1.270436
16:33:45 | 1.270418
16:33:45 | 1.270401
16:33:46 | 1.270383
16:33:46 | 1.256558
16:33:46 | 1.256539
16:33:46 | 1.270329
16:33:46 | 1.27031
16:33:47 | 1.272952
16:33:47 | 1.272934
16:33:47 | 1.272916
16:33:47 | 1.118756
16:33:48 | 1.118738
16:33:48 | 1.118723
16:33:48 | 1.118706
16:33:48 | 1.229329
16:33:49 | 1.229311
16:33:49 | 1.229292
16:33:49 | 1.229272
16:33:49 | 1.270083
16:33:50 | 1.270064
16:33:50 | 1.270045
16:33:50 | 1.270025
16:33:50 | 1.256202
16:33:51 | 1.256182
16:33:51 | 1.256162
16:33:51 | 1.256143
16:33:51 | 1.269927
16:33:52 | 1.269907
16:33:52 | 1.271266
16:33:52 | 1.271246
16:33:52 | 1.229025
16:33:53 | 1.229004
16:33:53 | 1.264287
16:33:53 | 1.264267
16:33:53 | 1.264247
16:33:53 | 1.255944
16:33:54 | 1.255924
16:33:54 | 1.255904
16:33:54 | 1.255882
16:33:54 | 1.269661
16:33:55 | 1.26964
16:33:55 | 1.26962
16:33:55 | 1.269599
16:33:55 | 1.228764
16:33:56 | 1.228744
16:33:56 | 1.228723
16:33:56 | 1.228702
16:33:56 | 1.269492
16:33:57 | 1.269469
16:33:57 | 1.228637
16:33:57 | 1.228615
16:33:57 | 1.11802
16:33:58 | 1.117999
16:33:58 | 1.228549
16:33:58 | 1.228528
16:33:58 | 1.269311
16:33:59 | 1.269287
16:33:59 | 1.255468
16:33:59 | 1.255444
16:33:59 | 1.269215
16:34:00 | 1.269193
16:34:00 | 1.269171
16:34:00 | 1.228348
16:34:00 | 1.228326
16:34:01 | 1.228302
16:34:01 | 1.22828
16:34:01 | 1.269053
16:34:01 | 1.26903
16:34:01 | 1.269007
16:34:02 | 1.268983
16:34:02 | 1.255165
16:34:02 | 1.255141
16:34:02 | 1.255118
16:34:03 | 1.255093
16:34:03 | 1.268859
16:34:03 | 1.268835
16:34:03 | 1.268809
16:34:04 | 1.268783
16:34:04 | 1.227972
16:34:04 | 1.227947
16:34:04 | 1.117411
16:34:05 | 1.117387
16:34:05 | 1.227873
16:34:05 | 1.227849
16:34:05 | 1.18395
16:34:06 | 1.183925
16:34:06 | 1.004046
16:34:06 | 1.004023
16:34:06 | 1.117226
16:34:07 | 1.117202
16:34:07 | 1.003961
16:34:07 | 1.003941
16:34:07 | 0.923048
16:34:08 | 0.923028
16:34:08 | 1.003879
16:34:08 | 1.003858
16:34:08 | 1.003838
16:34:09 | 1.117019
16:34:09 | 1.116993
16:34:09 | -15.156721
16:34:09 | 1.227409
16:34:10 | 1.22738
16:34:10 | 1.262608
16:34:10 | 1.262579
16:34:10 | 1.25428
16:34:11 | 1.25425
16:34:11 | 1.268006
16:34:11 | 1.267976
16:34:11 | 1.227187
16:34:12 | 1.227158
16:34:12 | 1.267891
16:34:12 | 1.267862
16:34:12 | 1.248538
16:34:13 | 1.248509
16:34:13 | 1.267777
16:34:13 | 1.267748
16:34:13 | 1.226965
16:34:14 | 1.226936
16:34:14 | 1.226908
16:34:14 | 1.267632
16:34:14 | 1.2676
16:34:15 | 1.267571
16:34:15 | 1.267541
16:34:15 | 1.253735
16:34:15 | 1.253706
16:34:16 | 1.253677
16:34:16 | 1.253647
16:34:16 | 1.267393
16:34:16 | 1.267364
16:34:17 | 1.267334
16:34:17 | 1.267304
16:34:17 | 1.226533
16:34:17 | 1.226504
16:34:18 | 1.226474
16:34:18 | 1.226445
16:34:18 | 1.267153
16:34:18 | 1.267122
16:34:19 | 1.26709
16:34:19 | 1.267059
16:34:19 | 1.253254
16:34:19 | 1.253223
16:34:20 | 1.253193
16:34:20 | 1.253161
16:34:20 | 1.266899
16:34:20 | 1.266867
16:34:21 | 1.266834
16:34:21 | 1.266802
16:34:21 | 1.226046
16:34:21 | 1.226013
16:34:22 | 1.225983
16:34:22 | 1.225952
16:34:22 | 1.26664
16:34:22 | 1.266606
16:34:23 | 1.266573
16:34:23 | 1.26654
16:34:23 | 1.252741
16:34:23 | 1.25271
16:34:24 | 1.252677
16:34:24 | 1.252645
16:34:24 | 1.266377
16:34:24 | 1.266343
16:34:25 | 1.266309
16:34:25 | 1.266273
16:34:25 | 1.225533
16:34:25 | 1.225501
16:34:26 | 1.225467
16:34:26 | 1.225433
16:34:26 | 1.266101
16:34:26 | 1.266068
16:34:27 | 1.266032
16:34:27 | 1.265998
16:34:27 | 1.252204
16:34:27 | 1.252169
16:34:28 | 1.252134
16:34:28 | 1.2521
16:34:28 | 1.265823
16:34:28 | 1.265787
16:34:29 | 1.265751
16:34:29 | 1.265716
16:34:29 | 1.22499
16:34:29 | 1.224954
16:34:30 | 1.22492
16:34:30 | 1.224886
16:34:30 | 1.265533
16:34:30 | 1.265498
16:34:31 | 1.265463
16:34:31 | 1.265429
16:34:31 | 1.251637
16:34:31 | 1.251599
16:34:32 | 1.251563
16:34:32 | 1.251525
16:34:32 | 1.265243
16:34:33 | 1.265206
16:34:33 | 1.265168
16:34:33 | 1.265129
16:34:33 | 1.224423
16:34:34 | 1.224382
16:34:34 | 1.224348
16:34:34 | 1.224311
16:34:34 | 1.264938
16:34:35 | 1.264901
16:34:35 | 1.264865
16:34:35 | 1.264827
16:34:35 | 1.251042
16:34:36 | 1.251005
16:34:36 | 1.250967
16:34:36 | 1.250925
16:34:36 | 1.264632
16:34:37 | 1.264593
16:34:37 | 1.264556
16:34:37 | 1.264519
16:34:37 | 1.223829
16:34:38 | 1.223789
16:34:38 | 1.22375
16:34:38 | 1.264358
16:34:38 | 1.264316
16:34:39 | 1.250532
16:34:39 | 1.250493
16:34:39 | 1.26419

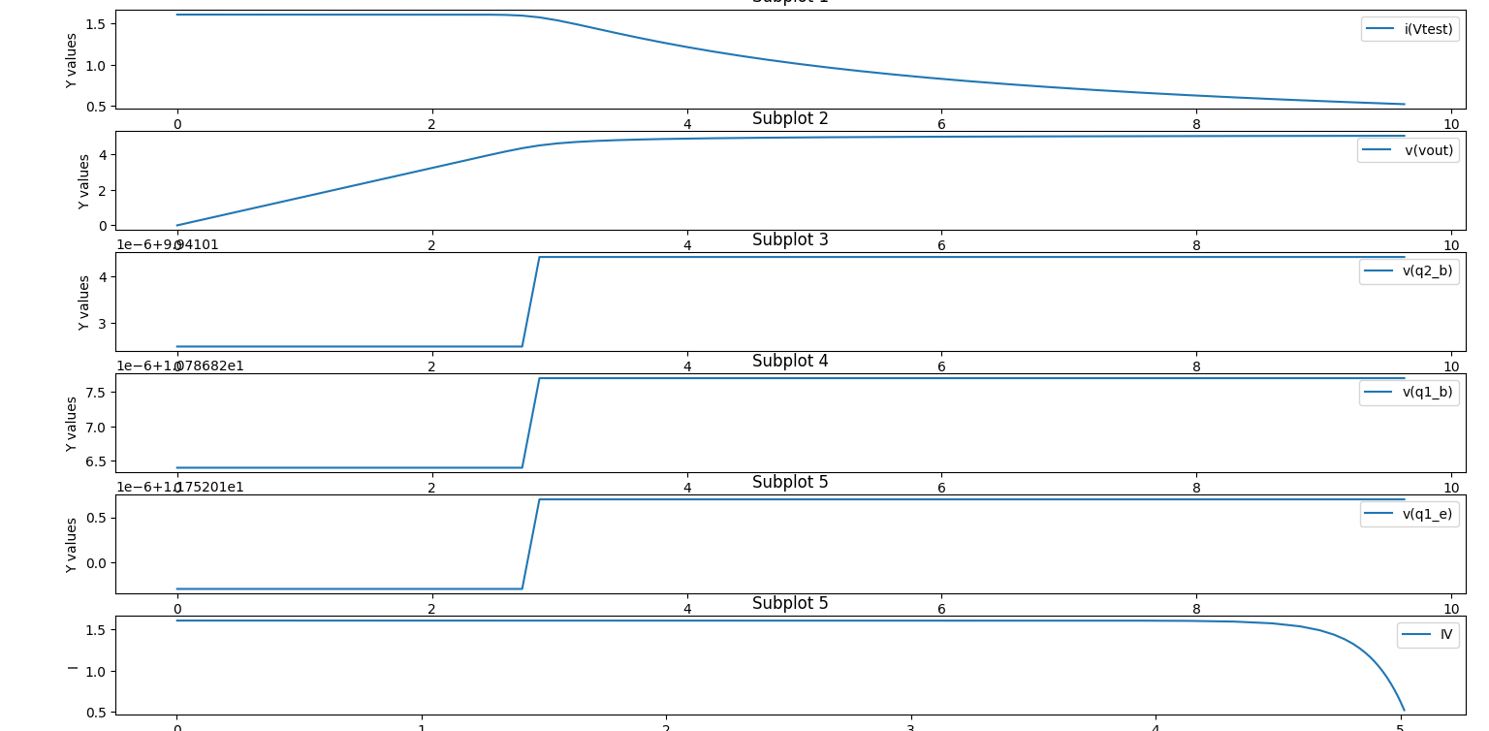
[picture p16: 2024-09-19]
Testing/Solar_Array_Simulator_SPICE/op_with_diodes.png

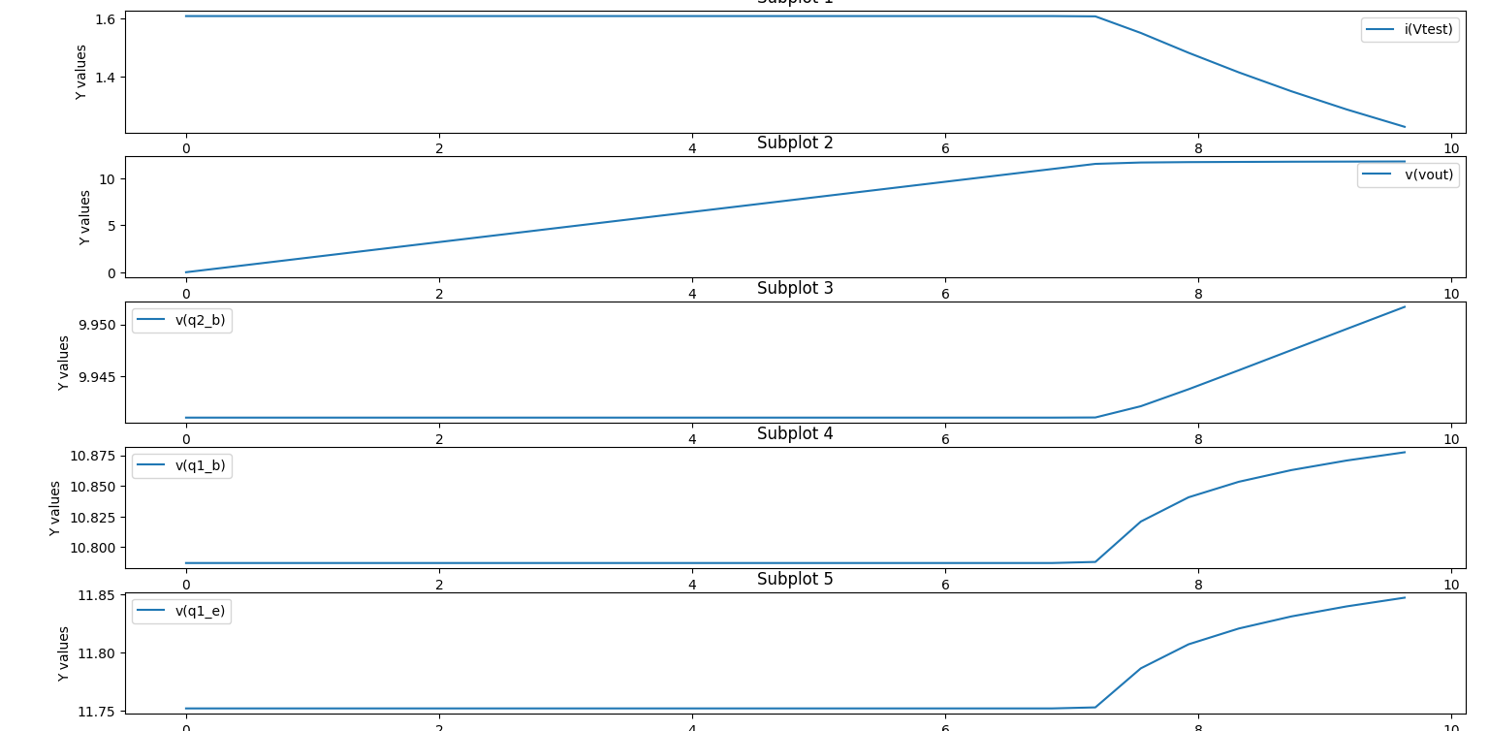
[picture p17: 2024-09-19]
Testing/Solar_Array_Simulator_SPICE/op.png

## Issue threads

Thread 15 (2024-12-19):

EPS PMB | Battery Pack Mounting

dangercomix07, 2024-12-19:
One hole missing for mounting battery pack on EPS PMB

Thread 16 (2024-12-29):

EPS PDB | Boot Switch

dangercomix07, 2024-12-29:
SPST Switch selected instead of SPDT switch for entering Boot mode at startup.
Should replace with SPDT slide switch instead for convenience in flashing and testing

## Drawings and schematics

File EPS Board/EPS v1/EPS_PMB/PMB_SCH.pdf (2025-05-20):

BQ29209DRBR | 300n 1E
IBAT | 9 PSYS | 10 PROCHOT_N 11 | SDA 12 | SCL 13 | CMPIN 14 | CMPOUT 15 | COMP1 16 | COMP2 | 17 CELL_BATPRES | 18 SRN | 19 SRP | 20 BATDRV_N | 21 VSYS | 22 SW2 | 23 HIDRV2 | 24 BTST2 | 25

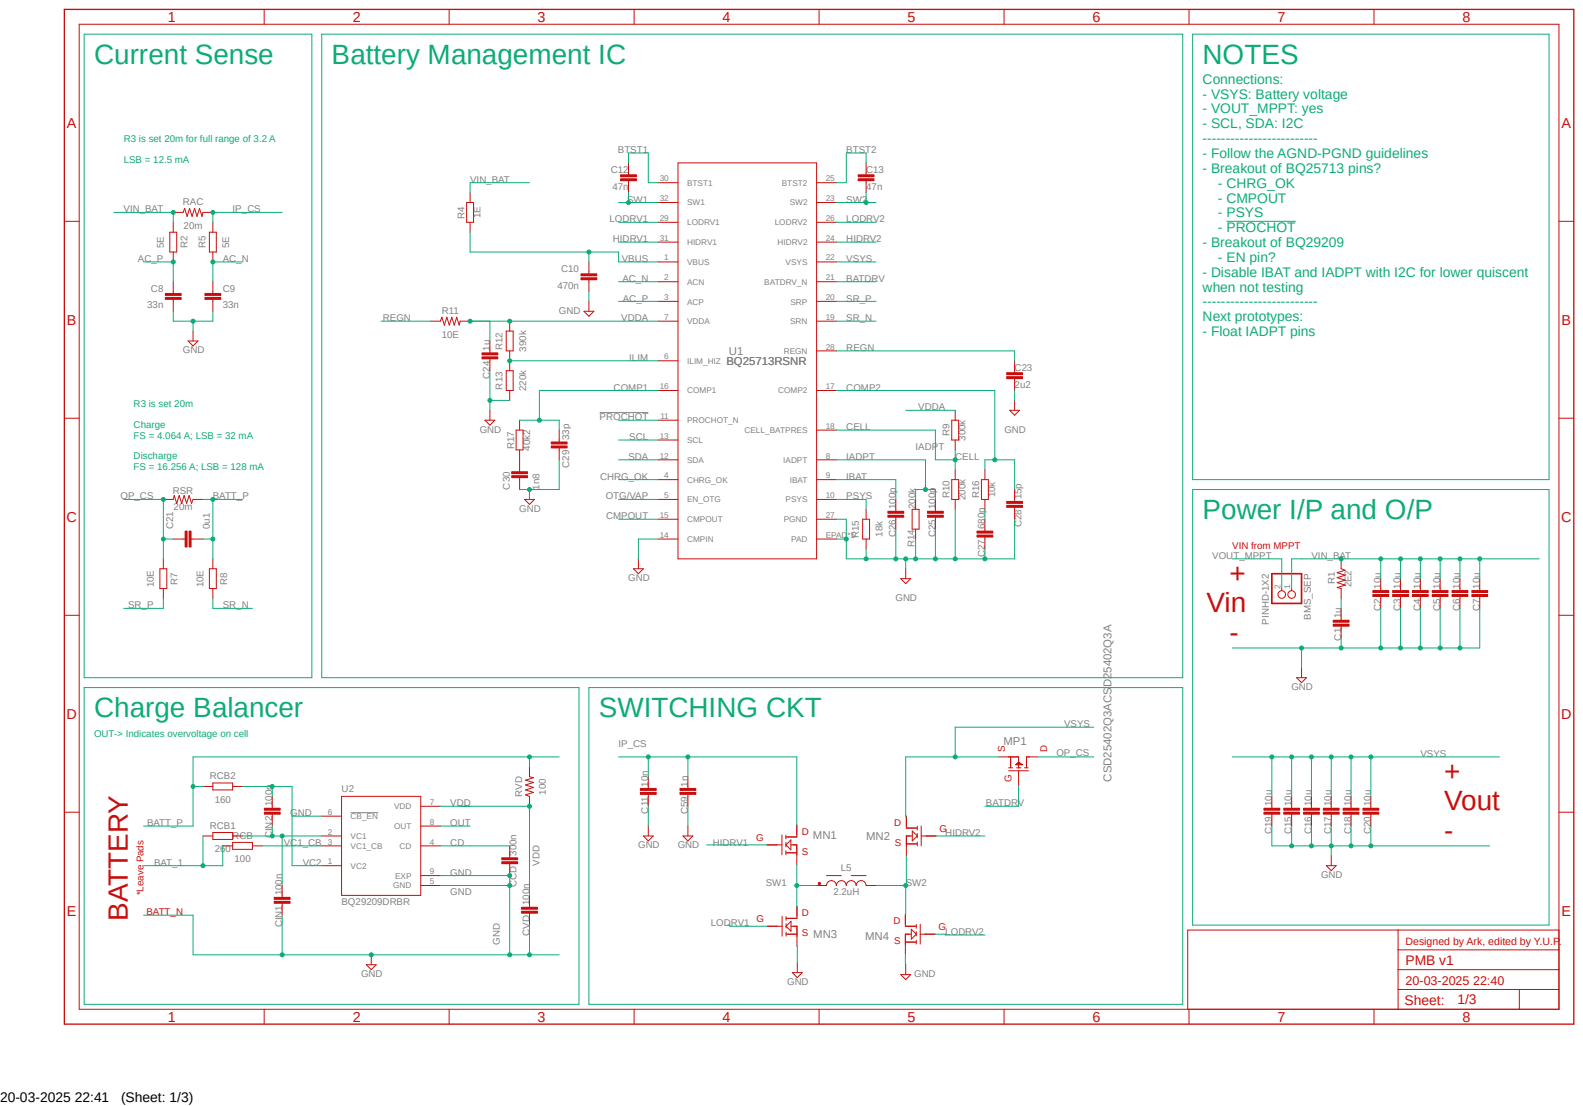
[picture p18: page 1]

Connections:
- VSYS: Battery voltage
- VOUT_MPPT: yes
- SCL, SDA: I2C
- Follow the AGND-PGND guidelines
- Breakout of BQ25713 pins?
- CHRG_OK
- CMPOUT
- PSYS
- PROCHOT
- Breakout of BQ29209
- EN pin?
- Disable IBAT and IADPT with I2C for lower quiscent
when not testing
------------------------- Next prototypes:

R3 is set 20m for full range of 3.2 A
LSB = 12.5 mA
RAC R⁵

OUT-> Indicates overvoltage on cell

Vout - Designed by Ark, edited by Y.U.P. BATTERY

VC1_CB
VC2

# GND ²⁰m 20m 20m

A

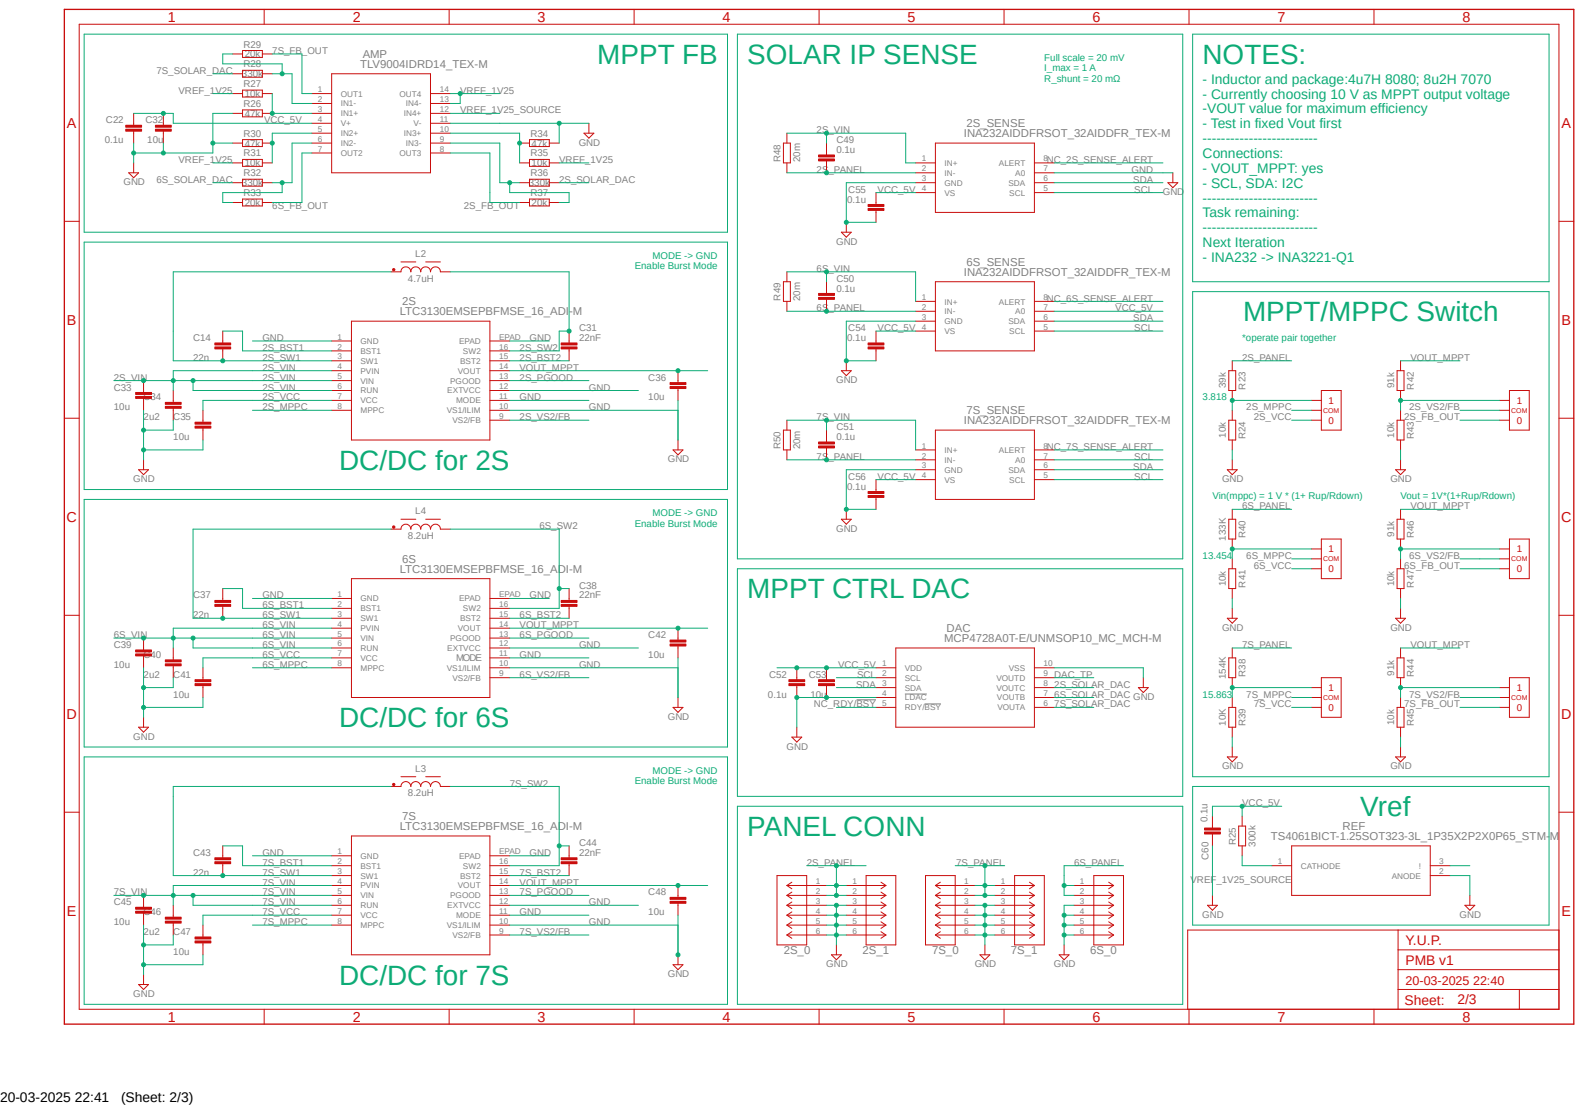
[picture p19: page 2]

- Inductor and package:4u7H 8080; 8u2H 7070
- Currently choosing 10 V as MPPT output voltage
-VOUT value for maximum efficiency
- Test in fixed Vout first ------------------------- Connections:

47k | VCC_5V

- VOUT_MPPT: yes
- SCL, SDA: I2C
------------------------- Task remaining: ------------------------- Next Iteration

20-03-2025 22:41 (Sheet: 3/3) | CSD¹⁷⁵⁵¹Q³ADNH⁰⁰⁰⁸A GND

A

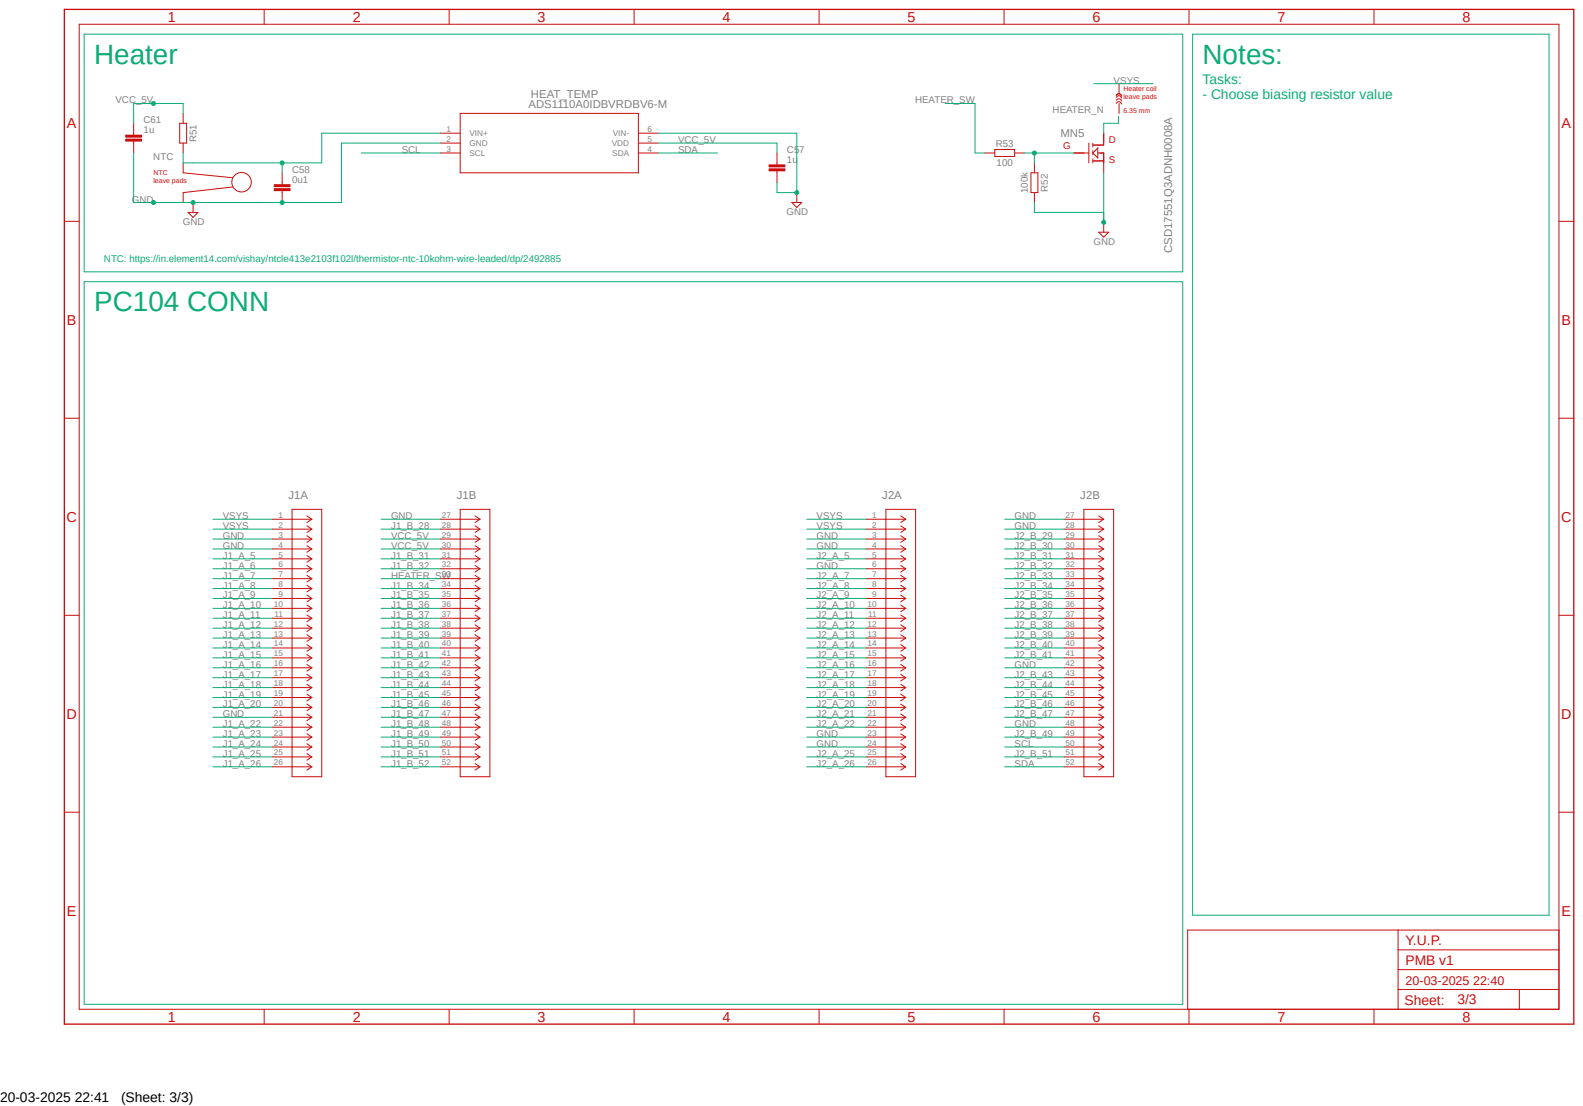
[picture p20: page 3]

Tasks:
- Choose biasing resistor value

NTC: https://in.element14.com/vishay/ntcle413e2103f102l/thermistor-ntc-10kohm-wire-leaded/dp/2492885
PC104 CONN

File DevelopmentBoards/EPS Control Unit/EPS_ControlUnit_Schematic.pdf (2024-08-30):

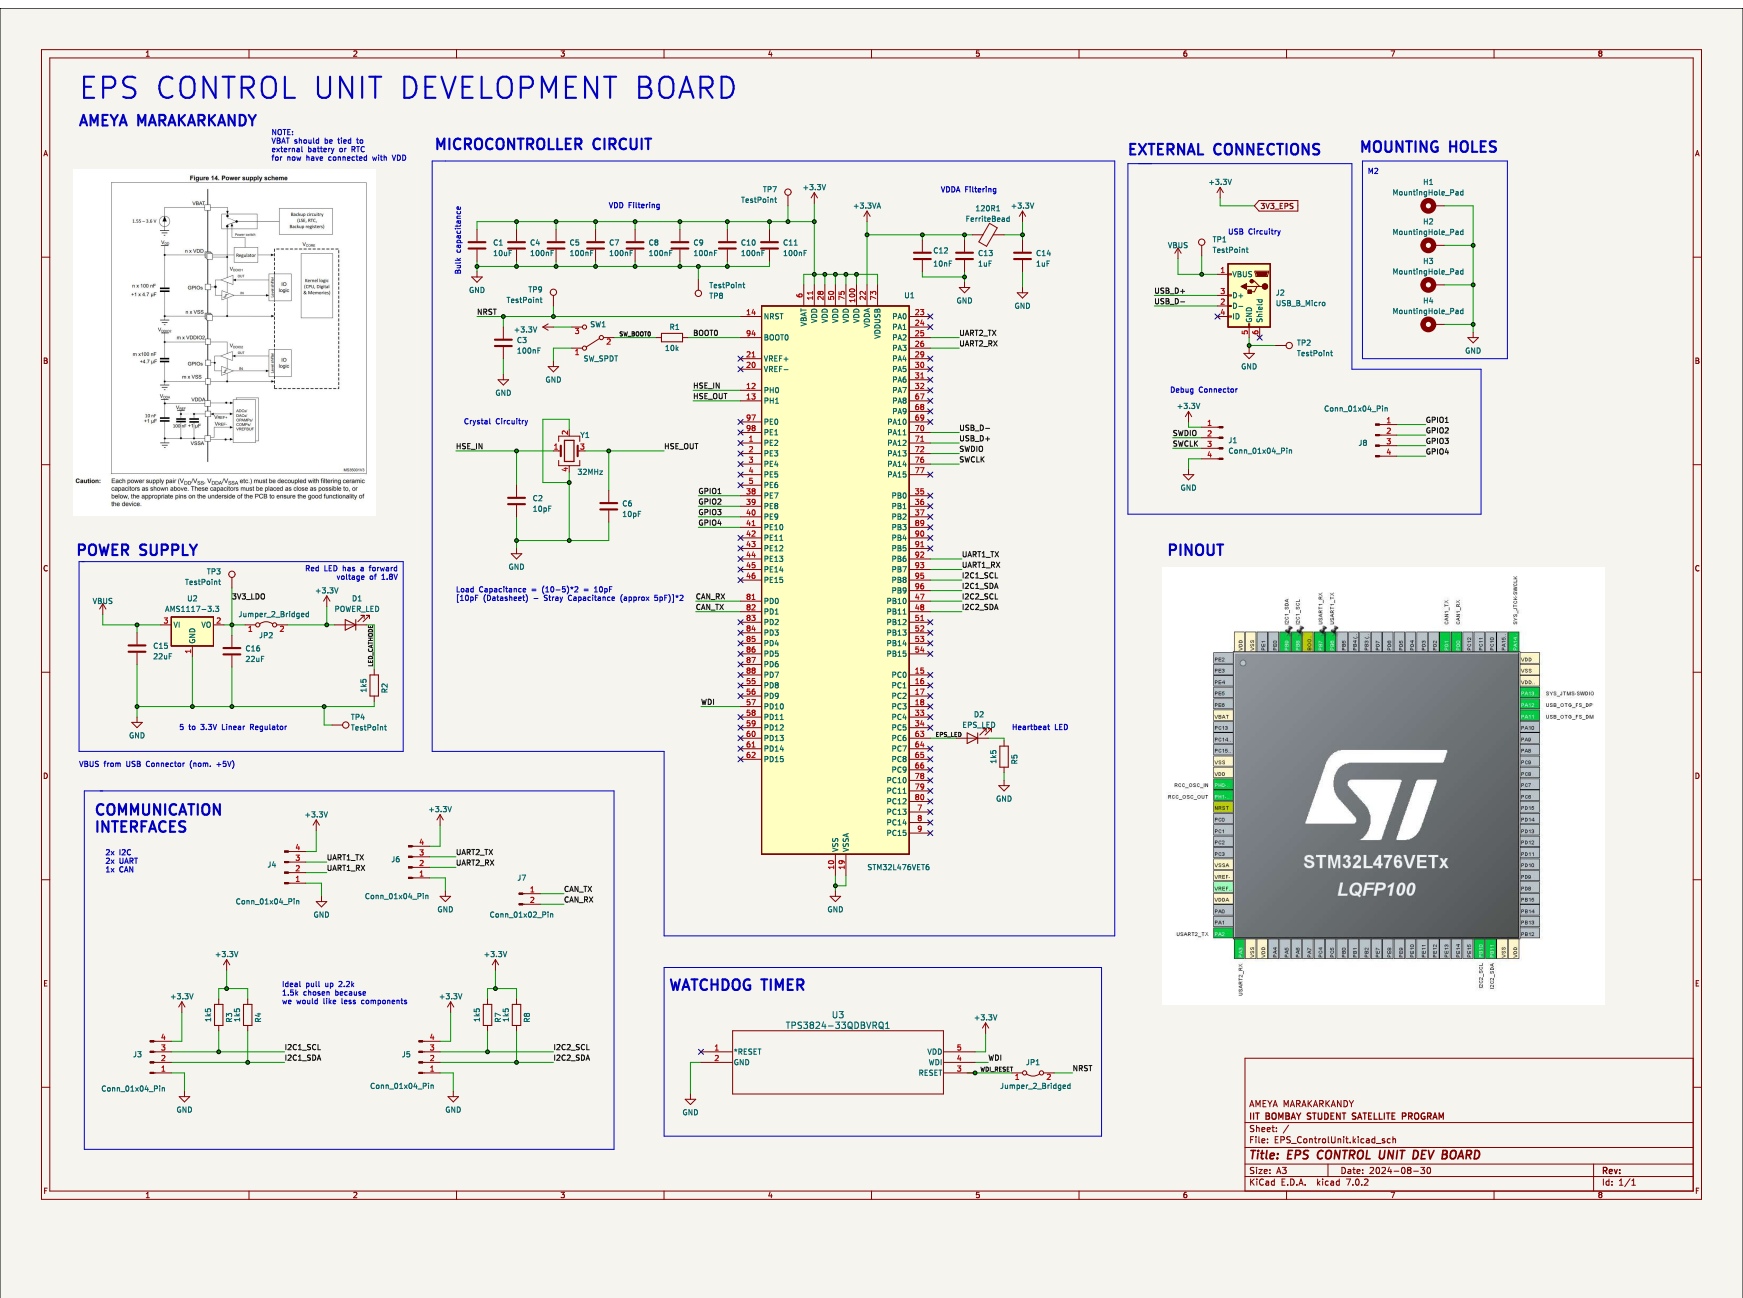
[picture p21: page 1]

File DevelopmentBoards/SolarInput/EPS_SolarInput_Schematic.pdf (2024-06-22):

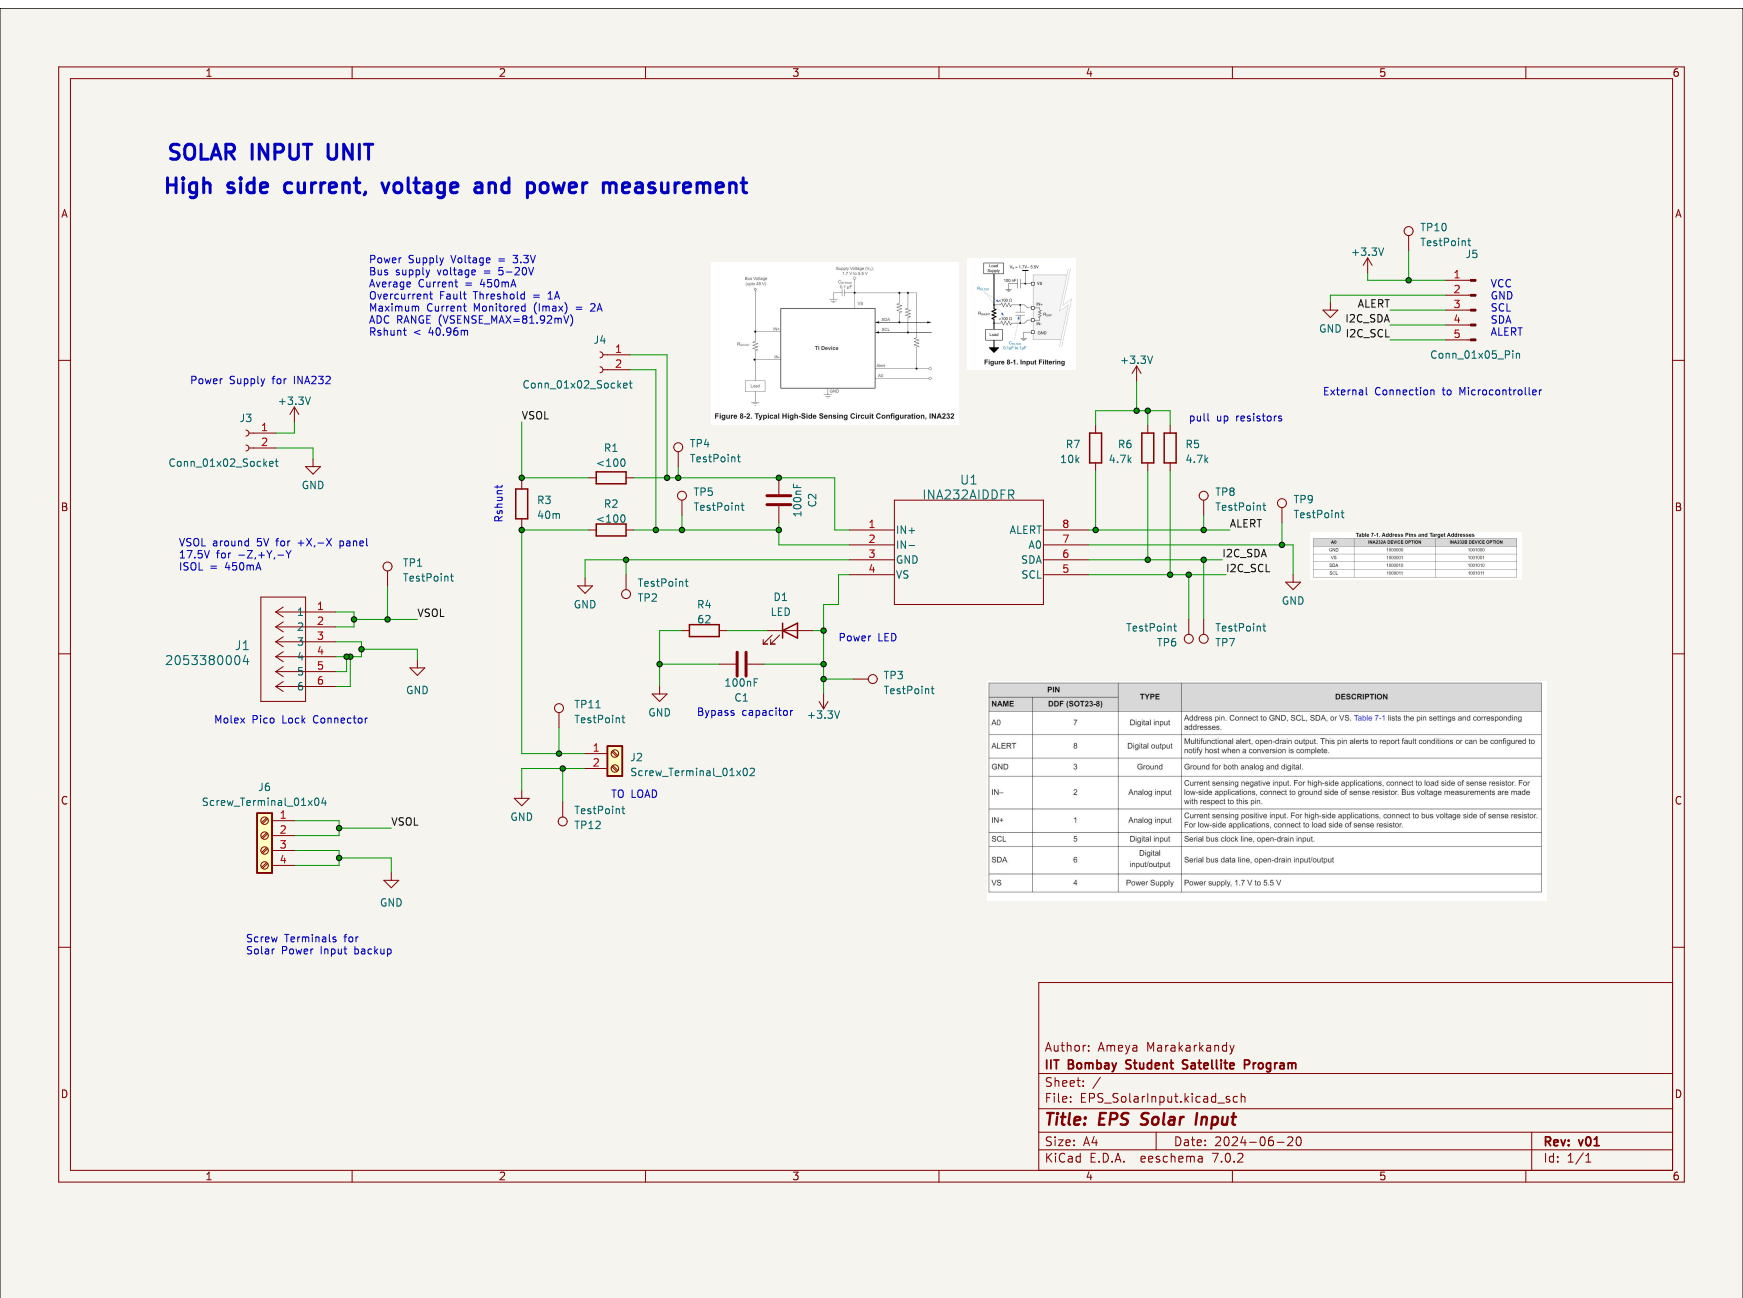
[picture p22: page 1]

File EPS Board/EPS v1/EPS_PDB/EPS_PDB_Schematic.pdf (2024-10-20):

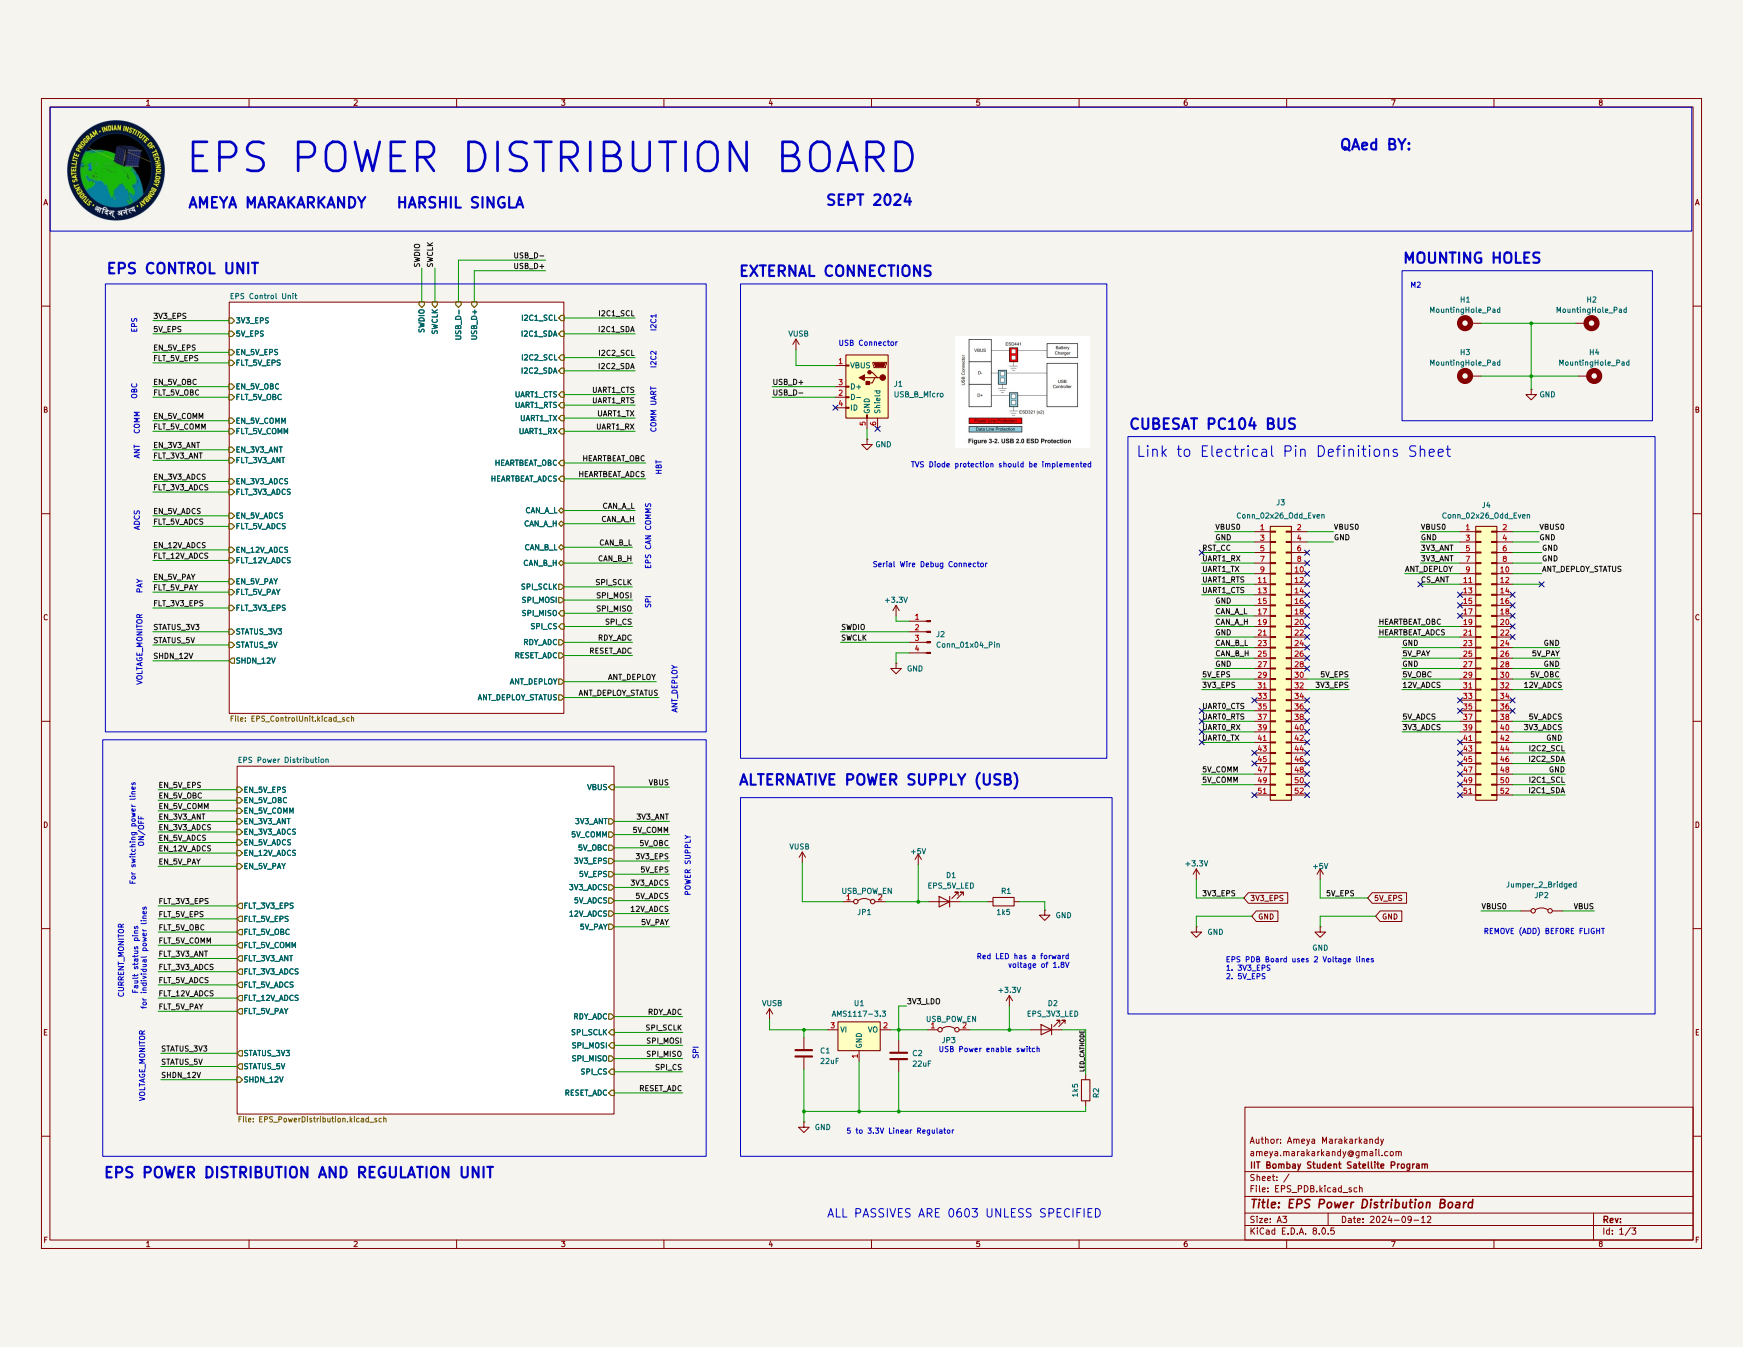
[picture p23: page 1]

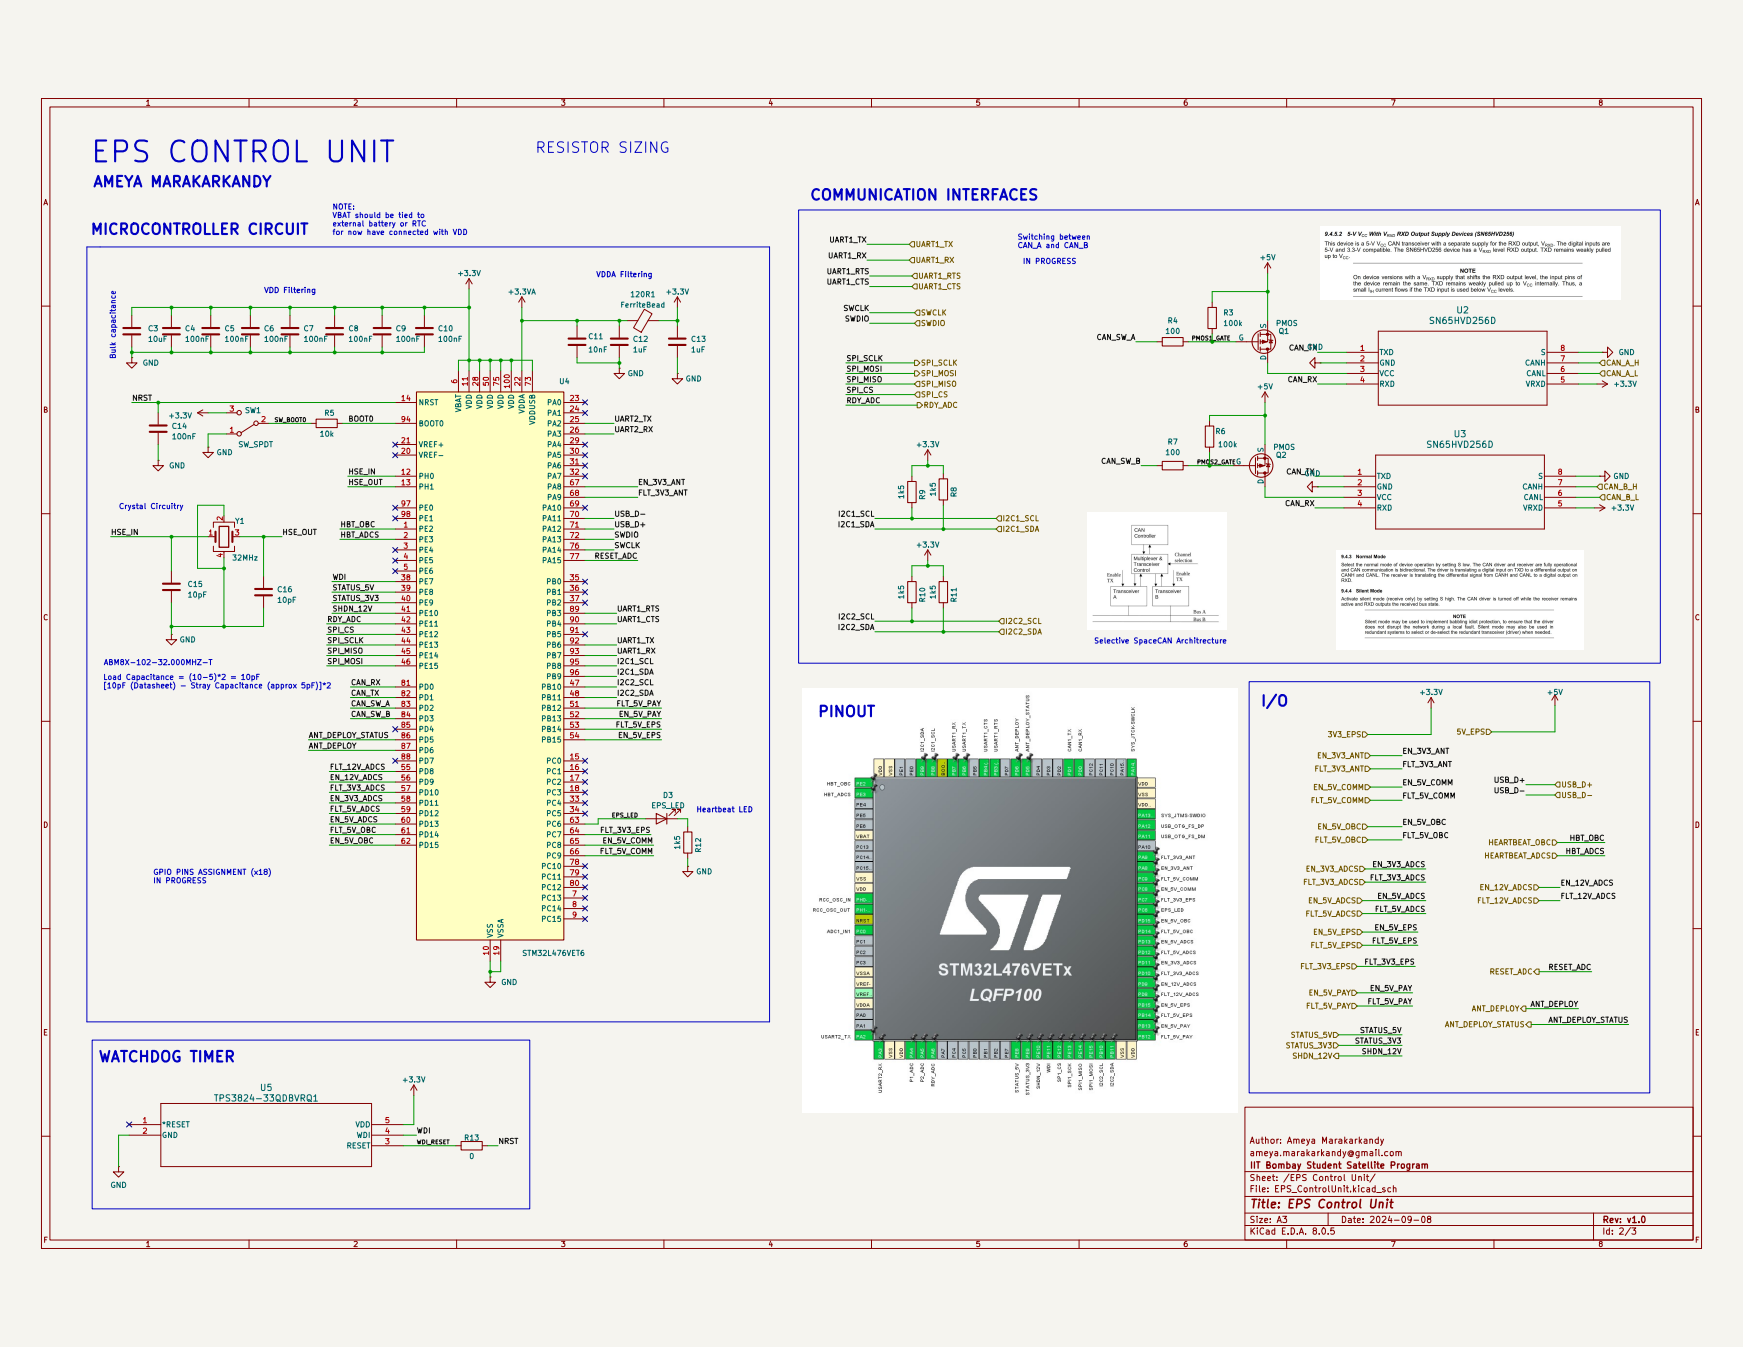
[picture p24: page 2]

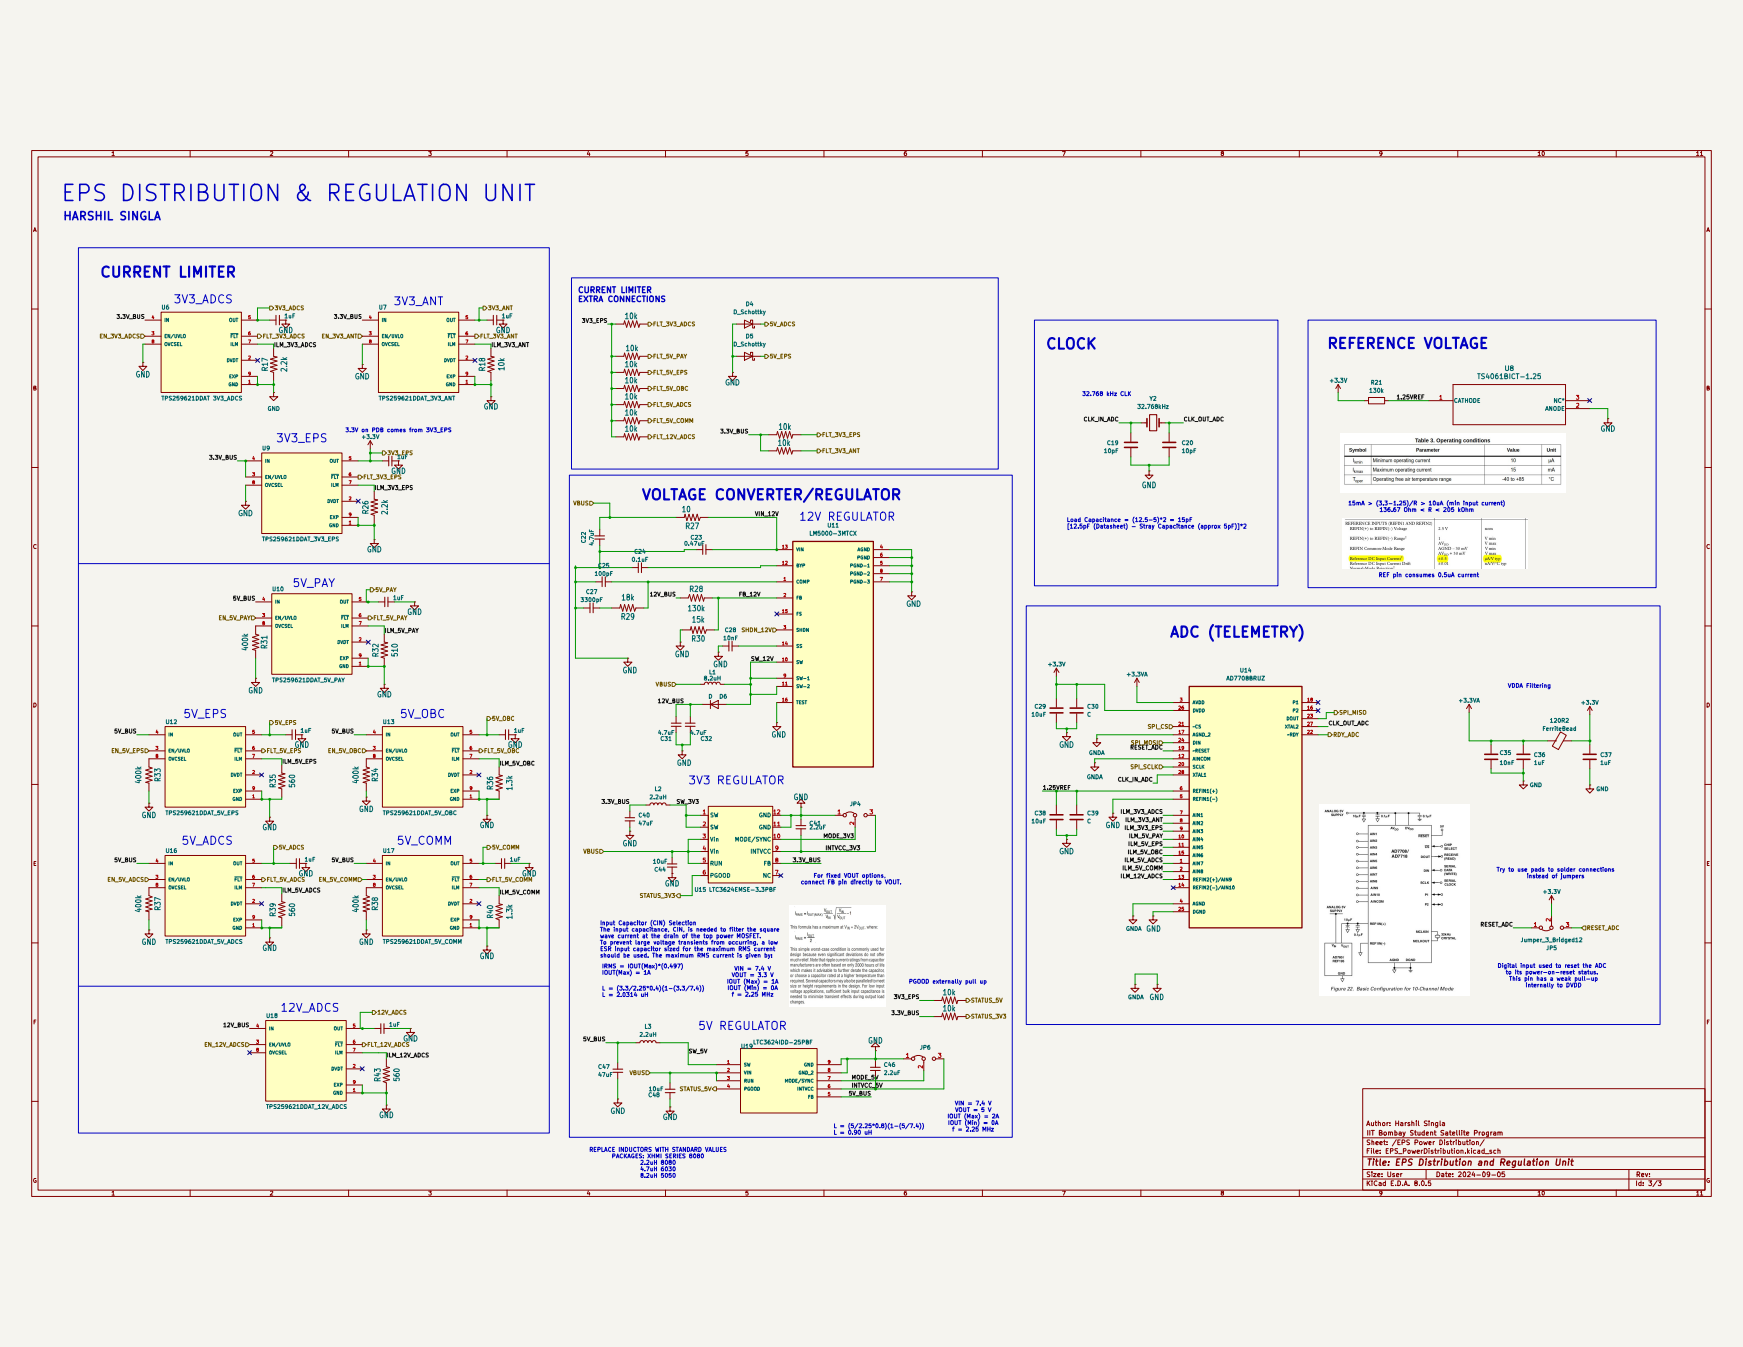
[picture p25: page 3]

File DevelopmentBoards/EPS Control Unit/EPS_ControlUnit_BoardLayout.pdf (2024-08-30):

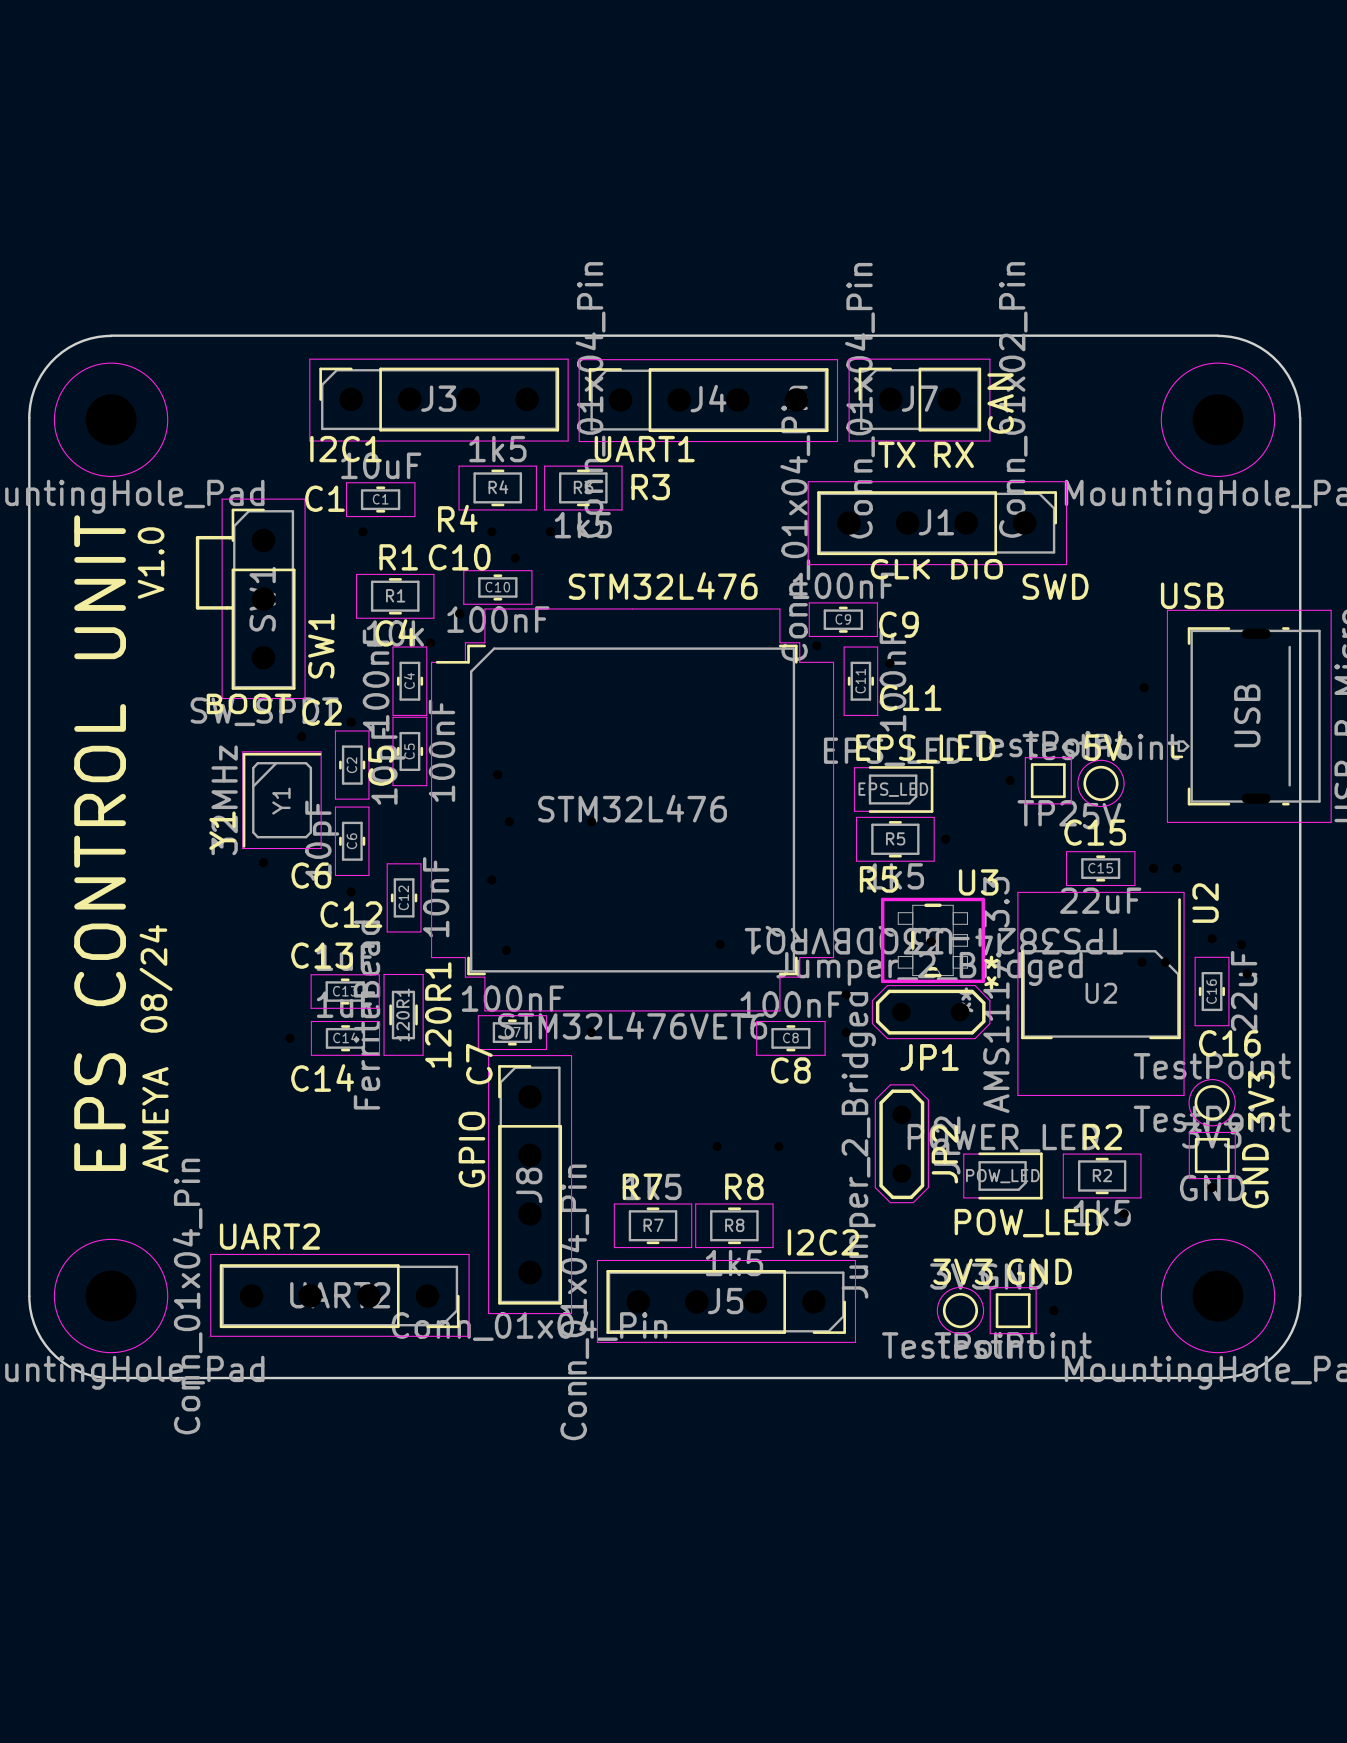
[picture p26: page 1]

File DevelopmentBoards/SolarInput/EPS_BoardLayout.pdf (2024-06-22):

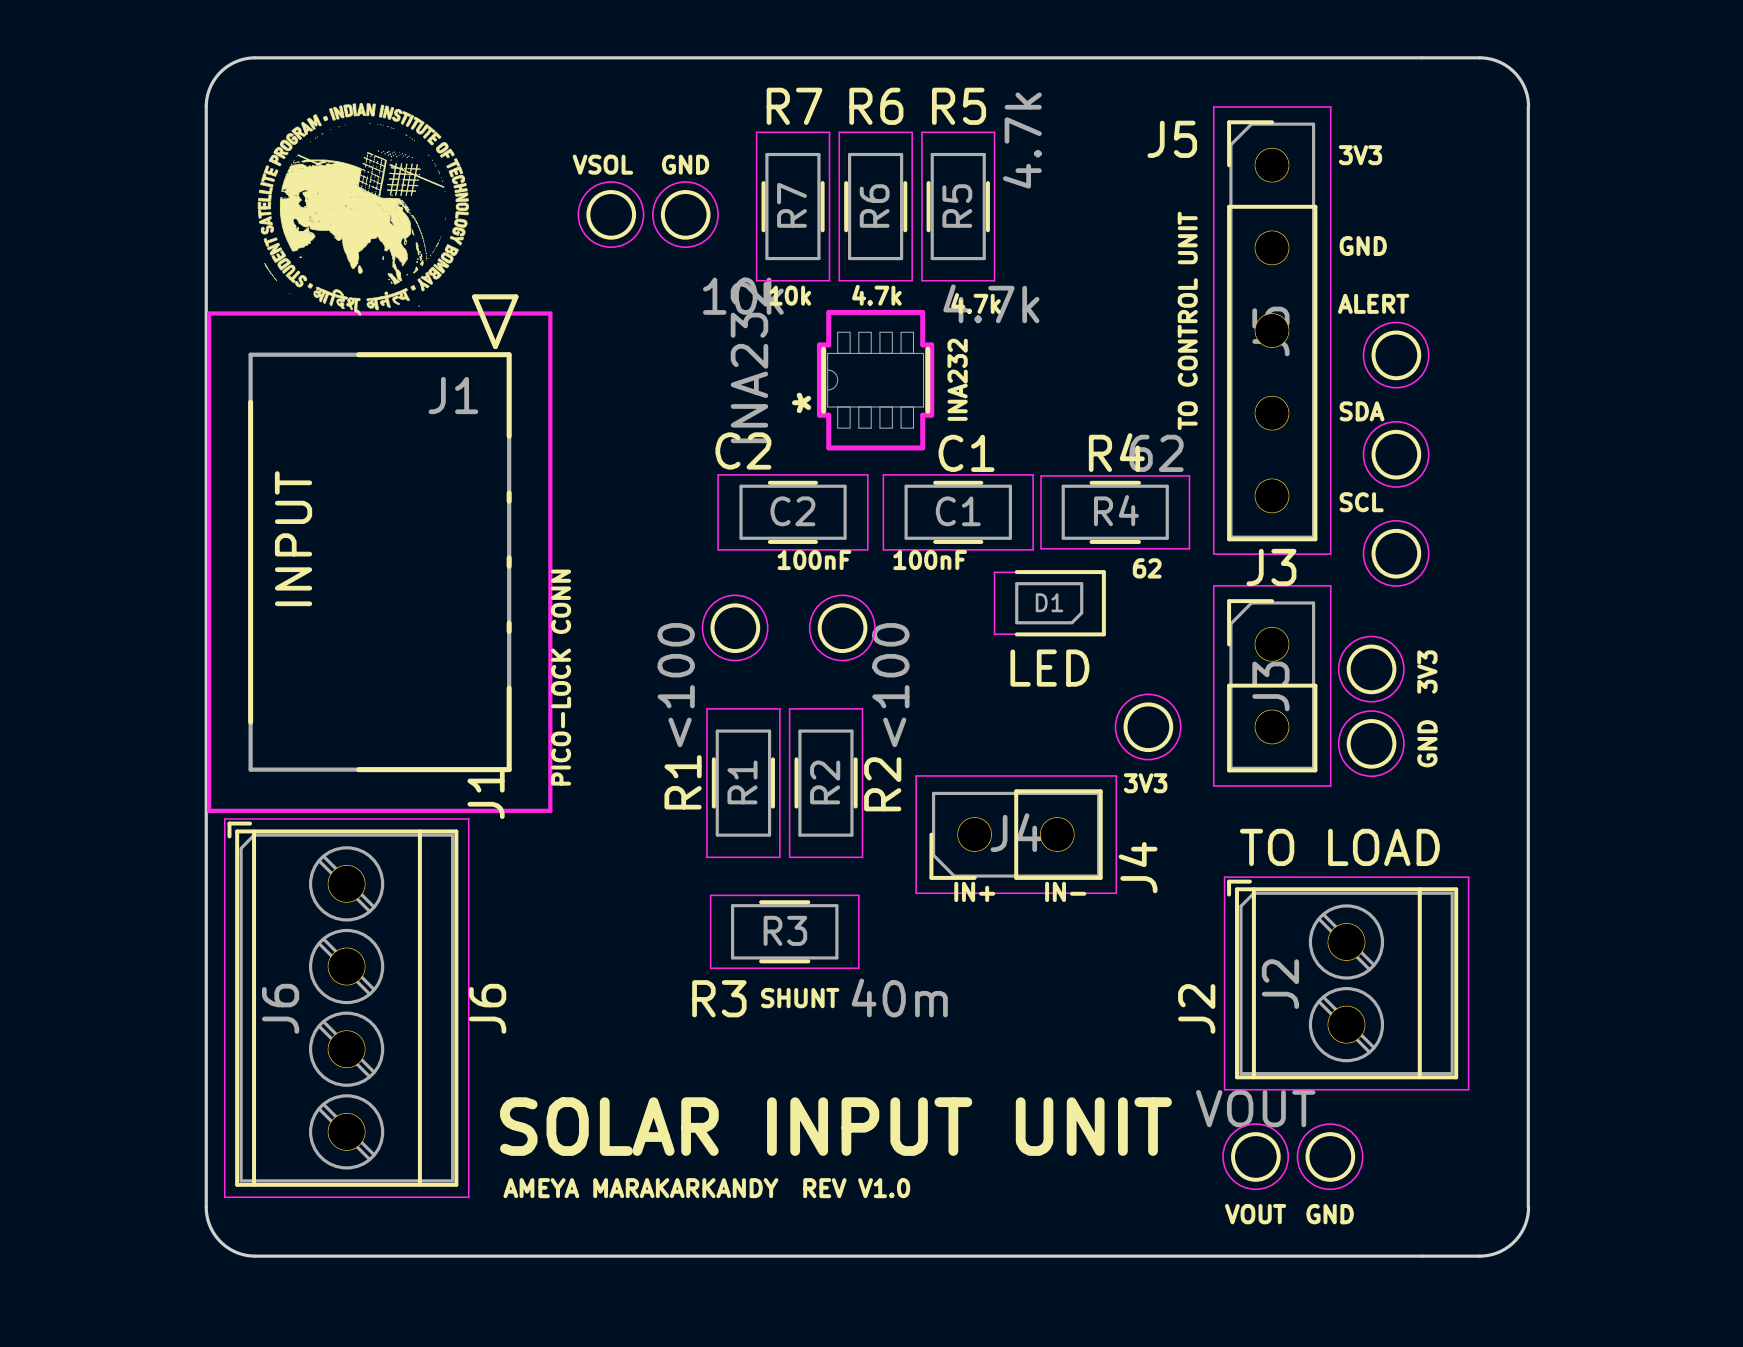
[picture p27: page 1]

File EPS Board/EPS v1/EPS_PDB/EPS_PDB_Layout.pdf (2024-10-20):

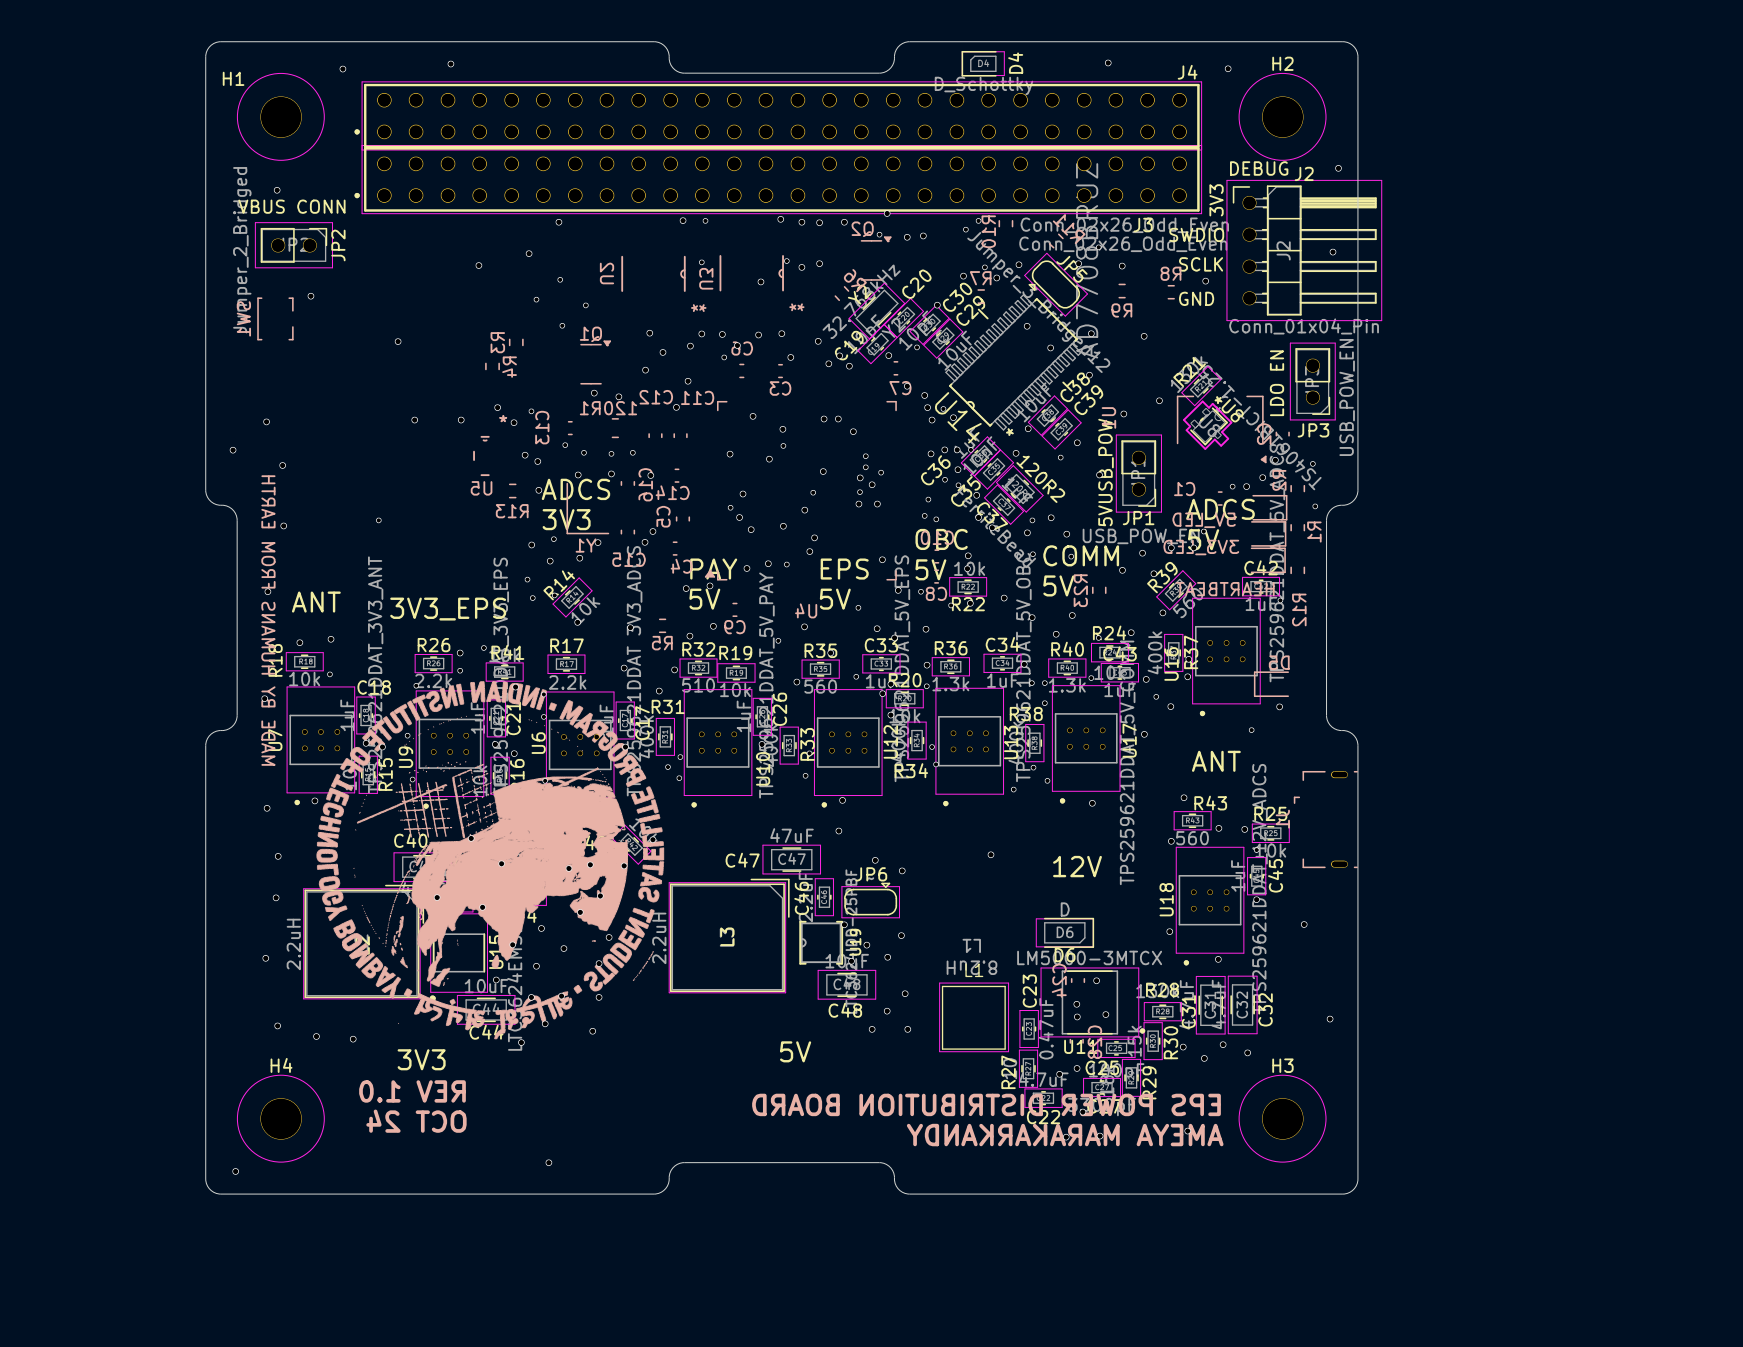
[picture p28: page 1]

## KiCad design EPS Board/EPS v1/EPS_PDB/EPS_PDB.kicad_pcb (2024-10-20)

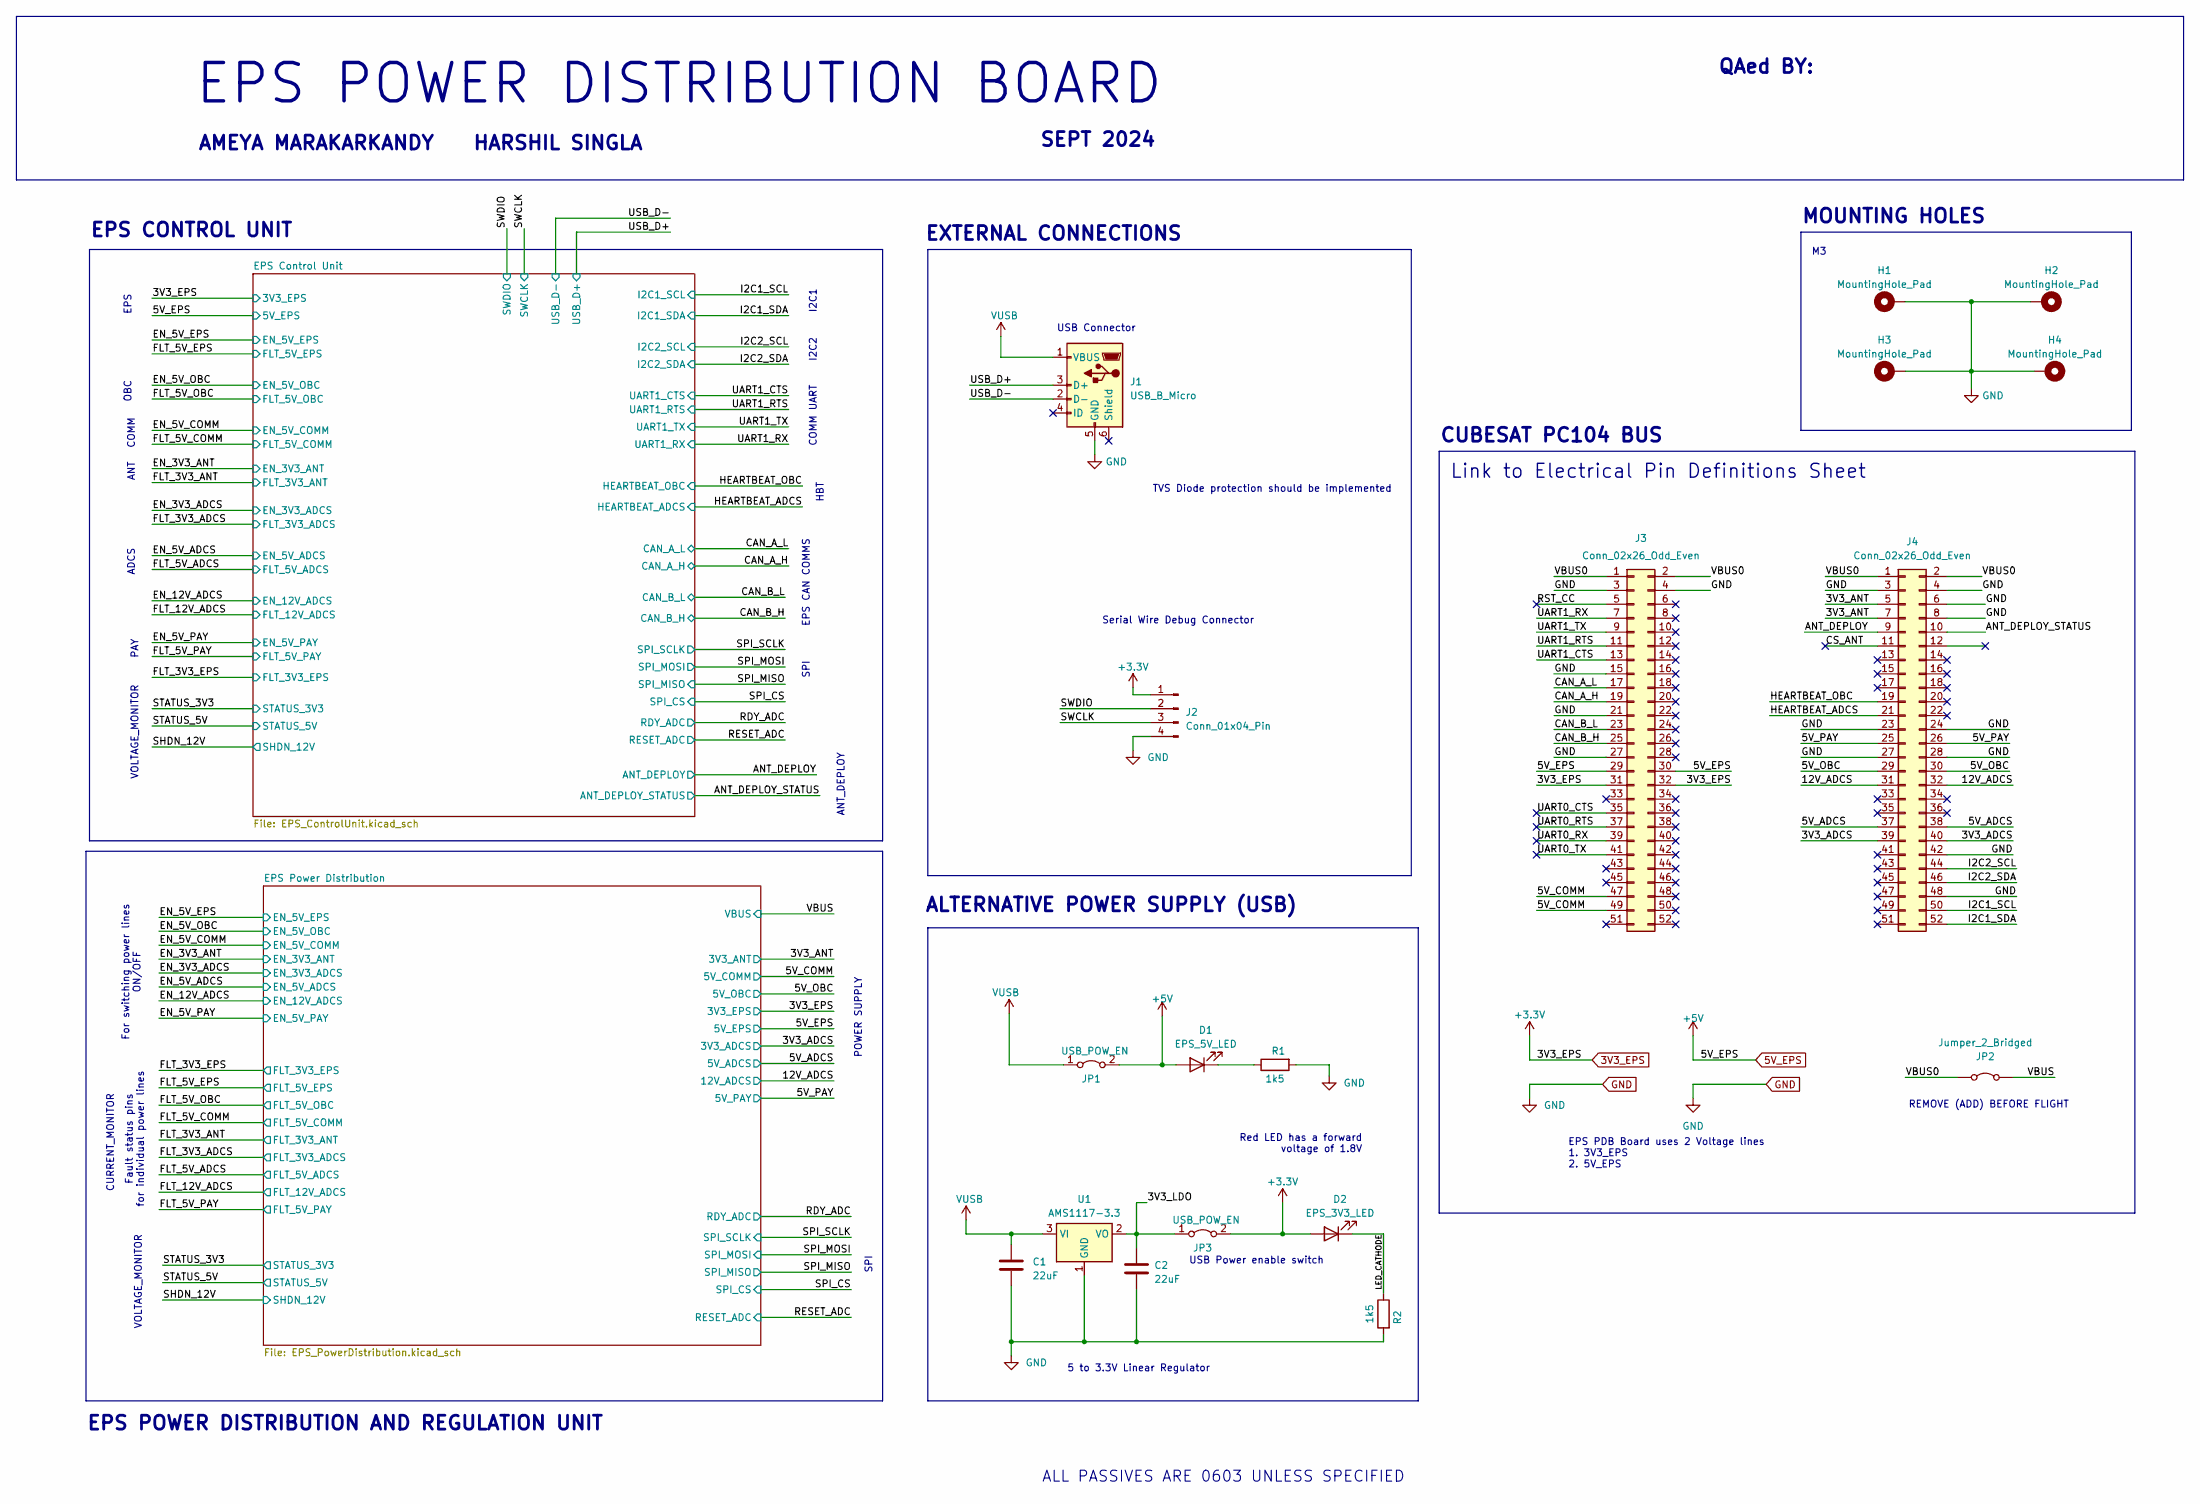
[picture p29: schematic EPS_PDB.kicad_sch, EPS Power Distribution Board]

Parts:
C1, C2: 22uF; C_0603_1608Metric
D1: EPS_5V_LED; LED_0805_2012Metric
D2: EPS_3V3_LED; LED_0805_2012Metric
H1, H2, H3, H4: MountingHole_Pad; MountingHole_3.2mm_M3_Pad
J1: USB_B_Micro; USB_Micro-B_GCT_USB3076-30-A
J2: Conn_01x04_Pin; PinHeader_1x04_P2.54mm_Horizontal
J3, J4: Conn_02x26_Odd_Even; SAMTEC_ESQ-126-39-G-D
JP1, JP3: USB_POW_EN; PinHeader_1x02_P2.54mm_Vertical
JP2: Jumper_2_Bridged; PinHeader_1x02_P2.54mm_Vertical
R1, R2: 1k5; R_0603_1608Metric
U1: AMS1117-3.3; SOT-223-3_TabPin2

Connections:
3V3_EPS: J2.1, J3.31, J3.32, JP3.2 (B); also elsewhere on the board
5V_EPS: D1.2 (A), J3.29, J3.30, JP1.2 (B); also elsewhere on the board
/3V3_ADCS: J4.39, J4.40; also elsewhere on the board
/3V3_ANT: J4.5, J4.7; also elsewhere on the board
/3V3_LDO: C2.1, JP3.1 (A), U1.2 (VO)
/5V_ADCS: J4.37, J4.38; also elsewhere on the board
/5V_COMM: J3.47, J3.49; also elsewhere on the board
/5V_OBC: J4.29, J4.30; also elsewhere on the board
/5V_PAY: J4.25, J4.26; also elsewhere on the board
/12V_ADCS: J4.31, J4.32; also elsewhere on the board
/ANT_DEPLOY: J4.9; also elsewhere on the board
/ANT_DEPLOY_STATUS: J4.10; also elsewhere on the board
/CAN_A_H: J3.19; also elsewhere on the board
/CAN_A_L: J3.17; also elsewhere on the board
/CAN_B_H: J3.25; also elsewhere on the board
/CAN_B_L: J3.23; also elsewhere on the board
/CS_ANT: J4.11
/HEARTBEAT_ADCS: J4.21; also elsewhere on the board
/HEARTBEAT_OBC: J4.19; also elsewhere on the board
/I2C1_SCL: J4.50; also elsewhere on the board
/I2C1_SDA: J4.52; also elsewhere on the board
/I2C2_SCL: J4.44; also elsewhere on the board
/I2C2_SDA: J4.46; also elsewhere on the board
/LED_CATHODE: R2.1; also elsewhere on the board
/RST_CC: J3.5
/SWCLK: J2.3; also elsewhere on the board
/SWDIO: J2.2; also elsewhere on the board
/UART0_CTS: J3.35
/UART0_RTS: J3.37
/UART0_RX: J3.39
/UART0_TX: J3.41
/UART1_CTS: J3.13; also elsewhere on the board
/UART1_RTS: J3.11; also elsewhere on the board
/UART1_RX: J3.7; also elsewhere on the board
/UART1_TX: J3.9; also elsewhere on the board
/USB_D+: J1.3 (D+); also elsewhere on the board
/USB_D-: J1.2 (D-); also elsewhere on the board
/VBUS: JP2.2 (B); also elsewhere on the board
/VBUS0: J3.1, J3.2, J4.1, J4.2, JP2.1 (A)
GND: C1.2, C2.2, H1.1, H2.1, H3.1, H4.1, J1.5 (GND), J1.6 (Shield), J2.4, J3.3, J3.4, J3.15, J3.21, J3.27, J4.3, J4.4, J4.6, J4.8, J4.23, J4.24, J4.27, J4.28, J4.42, J4.48, R1.2, R2.2, U1.1 (GND); also elsewhere on the board
unnamed 108: D1.1 (K), R1.1; also elsewhere on the board
VUSB: C1.1, J1.1 (VBUS), JP1.1 (A), U1.3 (VI)

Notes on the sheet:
EPS CONTROL UNIT
EPS CAN COMMS
USB Connector
I2C1
EPS
COMM UART
OBC
ANT_DEPLOY
QAed BY:
Serial Wire Debug Connector
CURRENT_MONITOR
I2C2
HARSHIL SINGLA
VOLTAGE_MONITOR
For switching power lines ON/OFF
5 to 3.3V Linear Regulator
Red LED has a forward voltage of 1.8V
EPS PDB Board uses 2 Voltage lines 1. 3V3_EPS 2. 5V_EPS
MOUNTING HOLES
PAY
REMOVE (ADD) BEFORE FLIGHT
SPI
USB Power enable switch
COMM
SEPT 2024
TVS Diode protection should be implemented
Link to Electrical Pin Definitions Sheet
POWER SUPPLY
EPS POWER DISTRIBUTION BOARD
EXTERNAL CONNECTIONS
ADCS
EPS POWER DISTRIBUTION AND REGULATION UNIT
ANT
ALL PASSIVES ARE 0603 UNLESS SPECIFIED
ALTERNATIVE POWER SUPPLY (USB)
CUBESAT PC104 BUS
Fault status pins for individual power lines
AMEYA MARAKARKANDY
HBT

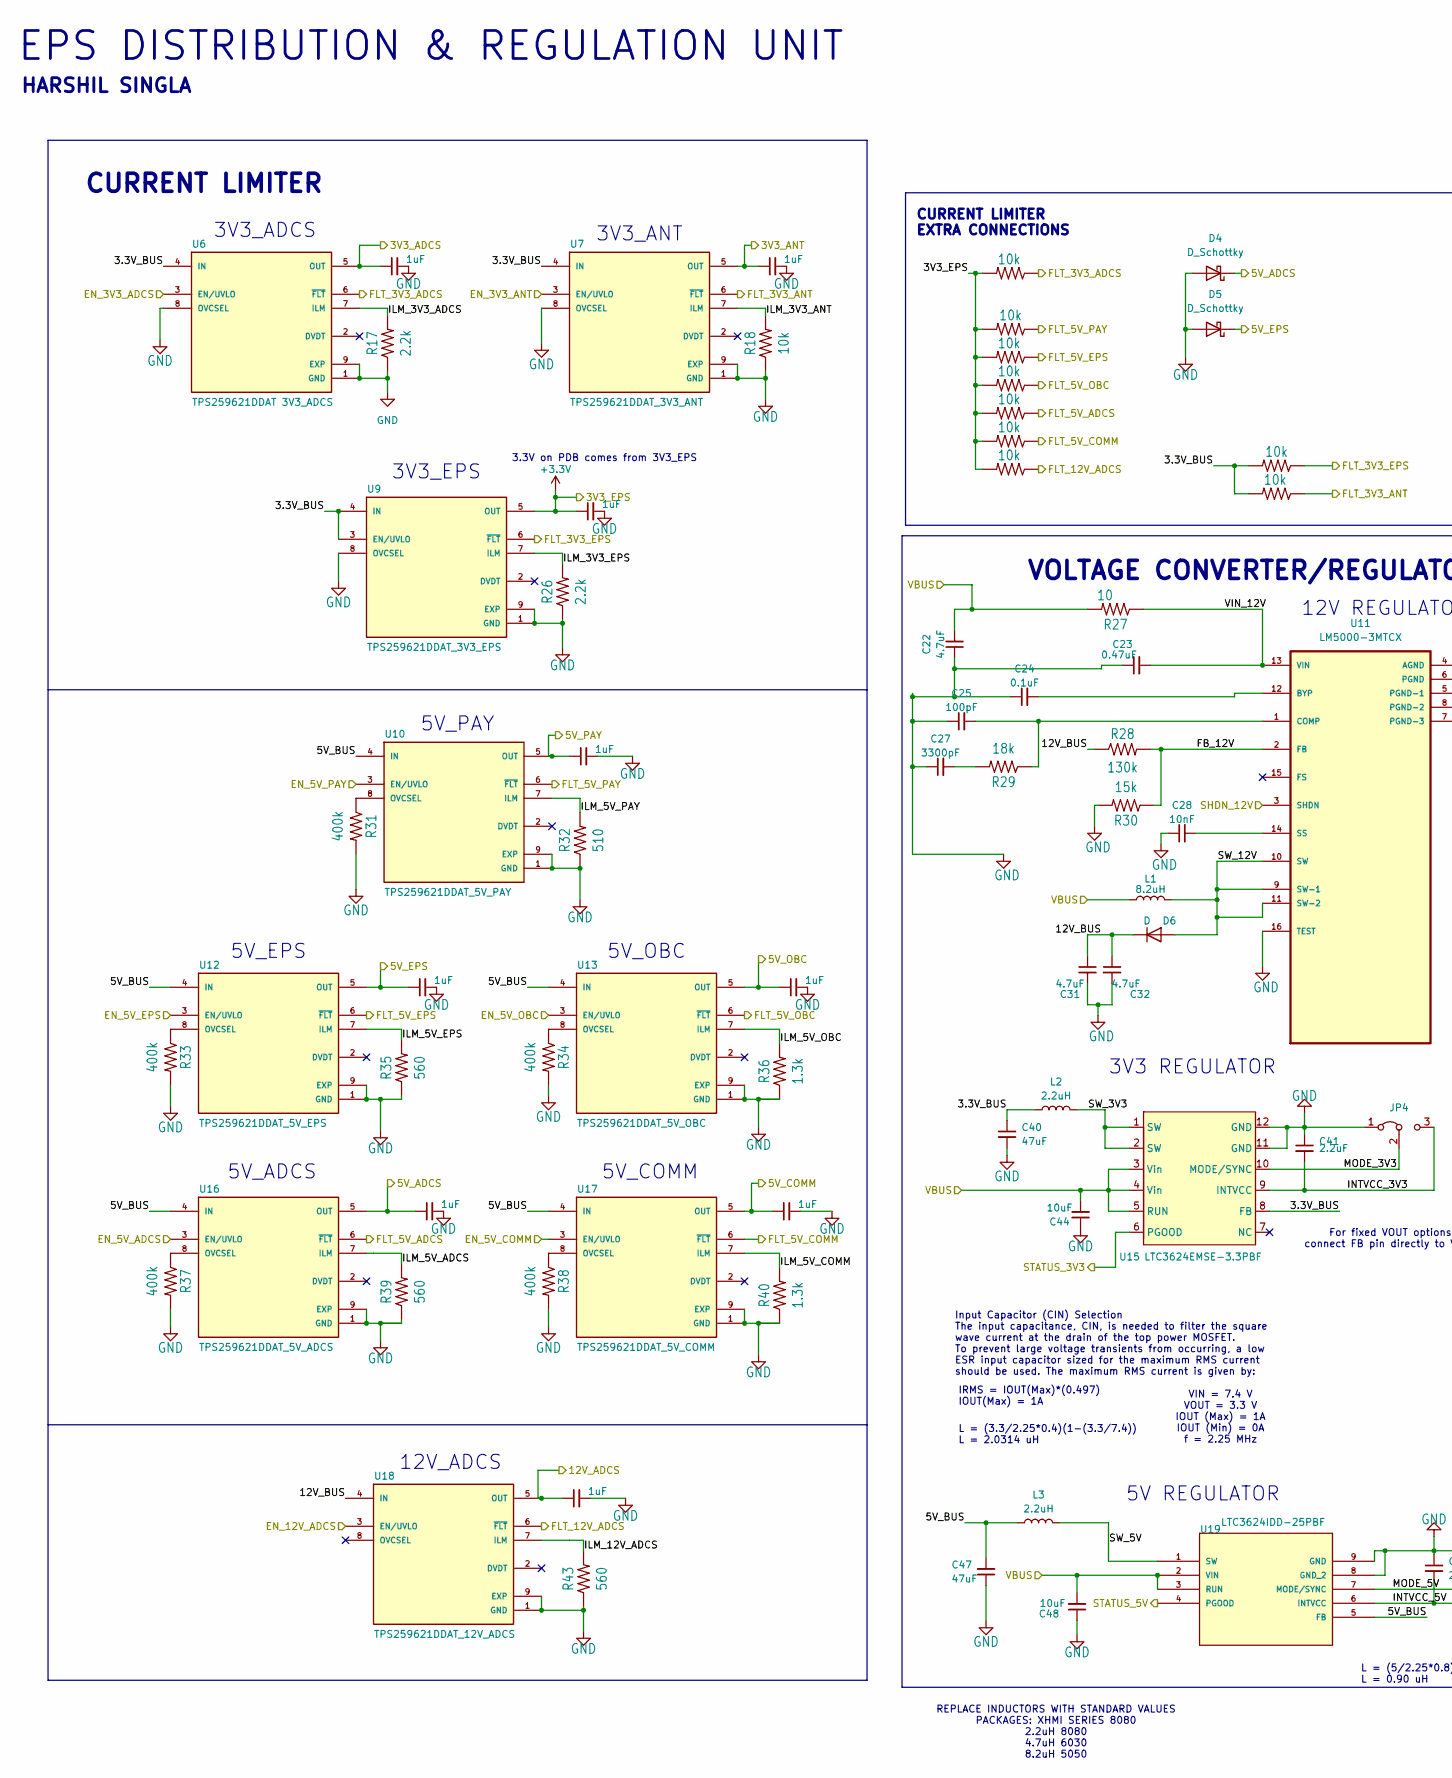
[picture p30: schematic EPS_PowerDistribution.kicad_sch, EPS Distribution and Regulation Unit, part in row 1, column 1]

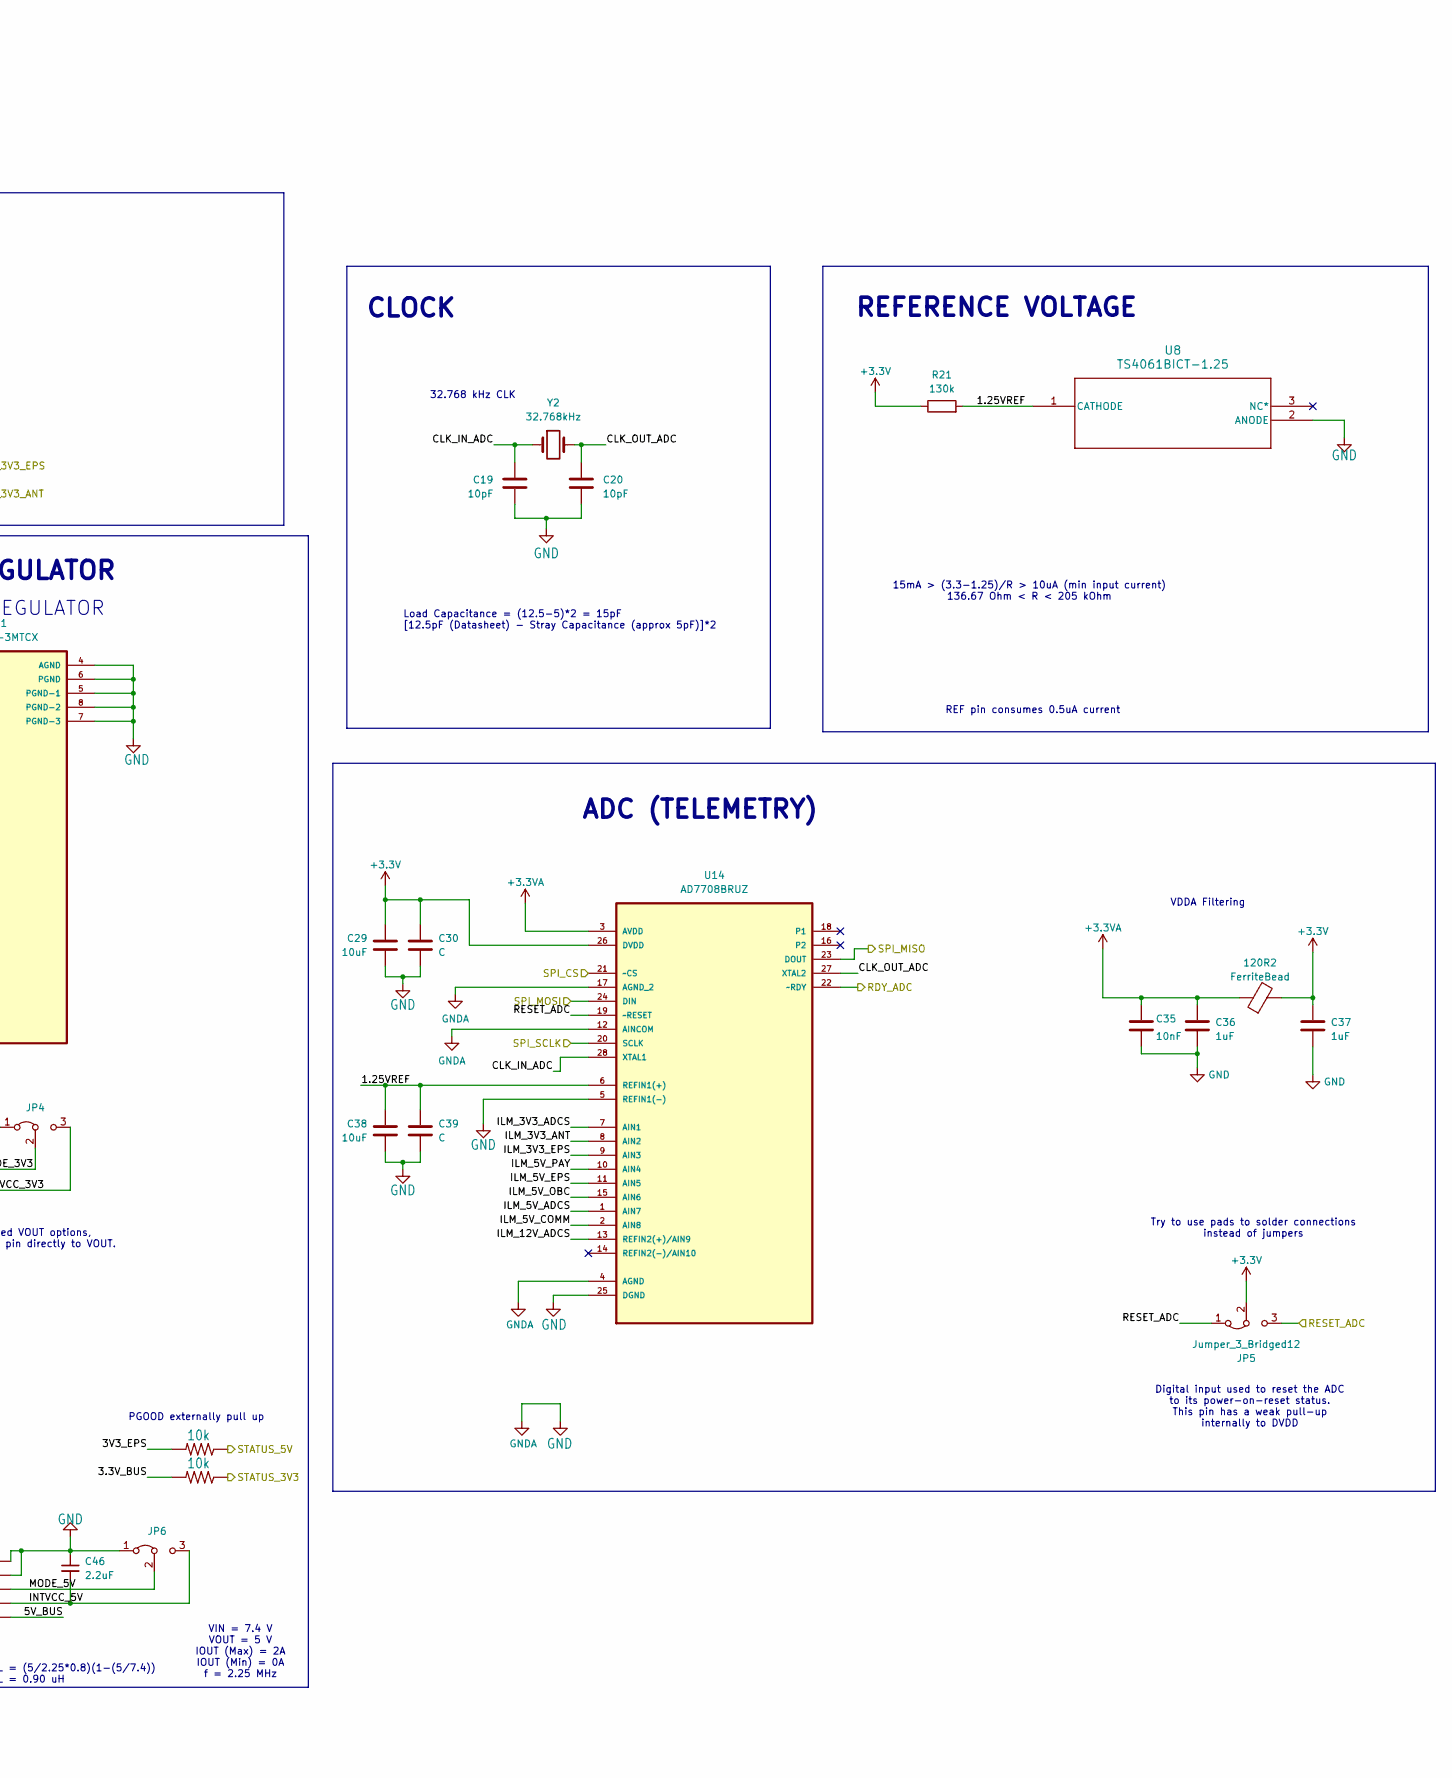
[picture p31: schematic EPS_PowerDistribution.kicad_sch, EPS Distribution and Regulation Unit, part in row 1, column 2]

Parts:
120R2: FerriteBead; R_0805_2012Metric
C17, C18, C21, C26, C33, C34, C36, C37, C42, C43, C45: 1uF; C_0603_1608Metric
C19, C20: 10pF; C_0603_1608Metric
C22: 4.7uF; C_0603_1608Metric
C23: 0.47uF; C_0603_1608Metric
C24: 0.1uF; C_0603_1608Metric
C25: 100pF; C_0603_1608Metric
C27: 3300pF; C_0603_1608Metric
C28, C35: 10nF; C_0603_1608Metric
C29, C38: 10uF; C_0603_1608Metric
C30, C39: C; C_0603_1608Metric
C31, C32: 4.7uF; C_1206_3216Metric
C40, C47: 47uF; C_1206_3216Metric
C41, C46: 2.2uF; C_0603_1608Metric
C44, C48: 10uF; C_1206_3216Metric
D4, D5: D_Schottky; D_0805_2012Metric
D6: D; D_1206_3216Metric
JP4, JP6: SolderJumper-3_P1.3mm_Open_RoundedPad1.0x1.5mm
JP5: Jumper_3_Bridged12; SolderJumper-3_P1.3mm_Open_RoundedPad1.0x1.5mm
L1: 8.2uH; WE-XHMI-5050
L2, L3: 2.2uH; L_Wuerth_WE-XHMI-8080
R14, R15, R16, R18, R19, R20, R22, R23, R24, R25, R41, R42: 10k; R_0603_1608Metric
R17, R26: 2.2k; R_0603_1608Metric
R21, R28: 130k; R_0603_1608Metric
R27: 10; R_0603_1608Metric
R29: 18k; R_0603_1608Metric
R30: 15k; R_0603_1608Metric
R31, R33, R34, R37, R38: 400k; R_0603_1608Metric
R32: 510; R_0603_1608Metric
R35, R39, R43: 560; R_0603_1608Metric
R36, R40: 1.3k; R_0603_1608Metric
U6: TPS259621DDAT 3V3_ADCS; IC_TPS259621DDAT
U7: TPS259621DDAT_3V3_ANT; IC_TPS259621DDAT
U8: TS4061BICT-1.25; SOT323-3L_1P35X2P2X0P65_STM
U9: TPS259621DDAT_3V3_EPS; IC_TPS259621DDAT
U10: TPS259621DDAT_5V_PAY; IC_TPS259621DDAT
U11: LM5000-3MTCX; SOP65P640X120-16N
U12: TPS259621DDAT_5V_EPS; IC_TPS259621DDAT
U13: TPS259621DDAT_5V_OBC; IC_TPS259621DDAT
U14: AD7708BRUZ; SOP65P638X110-28N; MPN AD7708BRUZ
U15: LTC3624EMSE-3.3PBF; SOP65P490X110-13N
U16: TPS259621DDAT_5V_ADCS; IC_TPS259621DDAT
U17: TPS259621DDAT_5V_COMM; IC_TPS259621DDAT
U18: TPS259621DDAT_12V_ADCS; IC_TPS259621DDAT
U19: LTC3624IDD-25PBF; DFN-8_DD
Y2: 32.768kHz; Crystal_SMD_3215-2Pin_3.2x1.5mm

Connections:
3V3_EPS: 120R2.2, C21.1, C29.1, C30.1, C37.1, JP5.2 (C), R14.2, R19.2, R20.2, R21.1, R22.2, R23.2, R24.2, R25.2, R41.2, U9.5 (OUT), U14.26 (DVDD); also elsewhere on the board
5V_EPS: C33.1, D5.1 (K), U12.5 (OUT); also elsewhere on the board
+3.3VA: 120R2.1, C35.1, C36.1, U14.3 (AVDD); also elsewhere on the board
/3V3_ADCS: C17.1, U6.5 (OUT); also elsewhere on the board
/3V3_ANT: C18.1, U7.5 (OUT); also elsewhere on the board
/5V_ADCS: C42.1, D4.1 (K), U16.5 (OUT); also elsewhere on the board
/5V_COMM: C43.1, U17.5 (OUT); also elsewhere on the board
/5V_OBC: C34.1, U13.5 (OUT); also elsewhere on the board
/5V_PAY: C26.1, U10.5 (OUT); also elsewhere on the board
/12V_ADCS: C45.1, U18.5 (OUT); also elsewhere on the board
/EN_3V3_ADCS: U6.3 (EN/UVLO); also elsewhere on the board
/EN_3V3_ANT: U7.3 (EN/UVLO); also elsewhere on the board
/EN_5V_ADCS: U16.3 (EN/UVLO); also elsewhere on the board
/EN_5V_COMM: U17.3 (EN/UVLO); also elsewhere on the board
/EN_5V_EPS: U12.3 (EN/UVLO); also elsewhere on the board
/EN_5V_OBC: U13.3 (EN/UVLO); also elsewhere on the board
/EN_5V_PAY: U10.3 (EN/UVLO); also elsewhere on the board
/EN_12V_ADCS: U18.3 (EN/UVLO); also elsewhere on the board
/EPS Power Distribution/1.25VREF: C38.1, C39.1, R21.2, U8.1 (CATHODE), U14.6 (REFIN1(+))
/EPS Power Distribution/3.3V_BUS: C40.1, L2.1, R15.2, R16.2, R42.2, U6.4 (IN), U7.4 (IN), U9.3 (EN/UVLO), U9.4 (IN), U15.8 (FB)
/EPS Power Distribution/5V_BUS: C47.2, L3.1, U10.4 (IN), U12.4 (IN), U13.4 (IN), U16.4 (IN), U17.4 (IN), U19.5 (FB)
/EPS Power Distribution/12V_BUS: C31.1, C32.1, D6.1 (K), R28.1, U18.4 (IN)
/EPS Power Distribution/CLK_IN_ADC: C19.1, U14.28 (XTAL1), Y2.1
/EPS Power Distribution/CLK_OUT_ADC: C20.1, U14.27 (XTAL2), Y2.2
/EPS Power Distribution/FB_12V: R28.2, R30.1, U11.2 (FB)
/EPS Power Distribution/ILM_3V3_ADCS: R17.2, U6.7 (ILM), U14.7 (AIN1)
/EPS Power Distribution/ILM_3V3_ANT: R18.2, U7.7 (ILM), U14.8 (AIN2)
/EPS Power Distribution/ILM_3V3_EPS: R26.2, U9.7 (ILM), U14.9 (AIN3)
/EPS Power Distribution/ILM_5V_ADCS: R39.2, U14.1 (AIN7), U16.7 (ILM)
/EPS Power Distribution/ILM_5V_COMM: R40.2, U14.2 (AIN8), U17.7 (ILM)
/EPS Power Distribution/ILM_5V_EPS: R35.2, U12.7 (ILM), U14.11 (AIN5)
/EPS Power Distribution/ILM_5V_OBC: R36.2, U13.7 (ILM), U14.15 (AIN6)
/EPS Power Distribution/ILM_5V_PAY: R32.2, U10.7 (ILM), U14.10 (AIN4)
/EPS Power Distribution/ILM_12V_ADCS: R43.2, U14.13 (REFIN2(+)/AIN9), U18.7 (ILM)
/EPS Power Distribution/INTVCC_3V3: C41.2, JP4.3 (B), U15.9 (INTVCC)
/EPS Power Distribution/INTVCC_5V: C46.2, JP6.3 (B), U19.6 (INTVCC)
/EPS Power Distribution/MODE_3V3: JP4.2 (C), U15.10 (MODE/SYNC)
/EPS Power Distribution/MODE_5V: JP6.2 (C), U19.7 (MODE/SYNC)
/EPS Power Distribution/SW_3V3: L2.2, U15.1 (SW), U15.2 (SW)
/EPS Power Distribution/SW_5V: L3.2, U19.1 (SW)
/EPS Power Distribution/SW_12V: D6.2 (A), L1.2, U11.9 (SW-1), U11.10 (SW), U11.11 (SW-2)
/EPS Power Distribution/VIN_12V: C23.2, R27.1, U11.13 (VIN)
/FLT_3V3_ADCS: R14.1, U6.6 (~FLT); also elsewhere on the board
/FLT_3V3_ANT: R15.1, U7.6 (~FLT); also elsewhere on the board
/FLT_3V3_EPS: R16.1, U9.6 (~FLT); also elsewhere on the board
/FLT_5V_ADCS: R23.1, U16.6 (~FLT); also elsewhere on the board
/FLT_5V_COMM: R24.1, U17.6 (~FLT); also elsewhere on the board
/FLT_5V_EPS: R20.1, U12.6 (~FLT); also elsewhere on the board
/FLT_5V_OBC: R22.1, U13.6 (~FLT); also elsewhere on the board
/FLT_5V_PAY: R19.1, U10.6 (~FLT); also elsewhere on the board
/FLT_12V_ADCS: R25.1, U18.6 (~FLT); also elsewhere on the board
/RDY_ADC: U14.22 (~RDY); also elsewhere on the board
/RESET_ADC: JP5.1 (A), JP5.3 (B), U14.19 (~RESET); also elsewhere on the board
/SHDN_12V: U11.3 (SHDN); also elsewhere on the board
/SPI_CS: U14.21 (~CS); also elsewhere on the board
/SPI_MISO: U14.23 (DOUT); also elsewhere on the board
/SPI_MOSI: U14.24 (DIN); also elsewhere on the board
/SPI_SCLK: U14.20 (SCLK); also elsewhere on the board
/STATUS_3V3: R42.1, U15.6 (PGOOD); also elsewhere on the board
/STATUS_5V: R41.1, U19.4 (PGOOD); also elsewhere on the board
/VBUS: C22.2, C44.2, C48.2, L1.1, R27.2, U15.3 (Vin), U15.4 (Vin), U15.5 (RUN), U19.2 (VIN), U19.3 (RUN); also elsewhere on the board
GND: C17.2, C18.2, C19.2, C20.2, C21.2, C22.1, C23.1, C24.1, C25.1, C26.2, C27.1, C28.1, C29.2, C30.2, C31.2, C32.2, C33.2, C34.2, C35.2, C36.2, C37.2, C38.2, C39.2, C40.2, C41.1, C42.2, C43.2, C44.1, C45.2, C46.1, C47.1, C48.1, D4.2 (A), D5.2 (A), JP4.1 (A), JP6.1 (A), R17.1, R18.1, R26.1, R30.2, R31.2, R32.1, R33.2, R34.2, R35.1, R36.1, R37.2, R38.2, R39.1, R40.1, R43.1, U6.1 (GND), U6.8 (OVCSEL), U6.9 (EXP), U7.1 (GND), U7.8 (OVCSEL), U7.9 (EXP), U8.2 (ANODE), U9.1 (GND), U9.8 (OVCSEL), U9.9 (EXP), U10.1 (GND), U10.9 (EXP), U11.4 (AGND), U11.5 (PGND-1), U11.6 (PGND), U11.7 (PGND-3), U11.8 (PGND-2), U11.16 (TEST), U12.1 (GND), U12.9 (EXP), U13.1 (GND), U13.9 (EXP), U14.4 (AGND), U14.5 (REFIN1(-)), U14.12 (AINCOM), U14.17 (AGND_2), U14.25 (DGND), U15.11 (GND), U15.12 (GND), U16.1 (GND), U16.9 (EXP), U17.1 (GND), U17.9 (EXP), U18.1 (GND), U18.9 (EXP), U19.8 (GND_2), U19.9 (GND); also elsewhere on the board
unnamed: C27.2, R29.2
unnamed: R31.1, U10.8 (OVCSEL)
unnamed: C24.2, U11.12 (BYP)
unnamed: C25.2, R29.1, U11.1 (COMP)
unnamed: C28.2, U11.14 (SS)
unnamed: R33.1, U12.8 (OVCSEL)
unnamed: R34.1, U13.8 (OVCSEL)
unnamed: R37.1, U16.8 (OVCSEL)
unnamed: R38.1, U17.8 (OVCSEL)

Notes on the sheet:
VOLTAGE CONVERTER/REGULATOR
REFERENCE VOLTAGE
VIN = 7.4 V VOUT = 3.3 V IOUT (Max) = 1A IOUT (Min) = 0A f = 2.25 MHz
5V_EPS
ADC (TELEMETRY)
12V_ADCS
5V_OBC
L = (3.3/2.25*0.4)(1-(3.3/7.4)) L = 2.0314 uH
12V REGULATOR
L = (5/2.25*0.8)(1-(5/7.4)) L = 0.90 uH
IRMS = IOUT(Max)*(0.497) IOUT(Max) = 1A
5V_ADCS
5V_COMM
3V3_ANT
CURRENT LIMITER EXTRA CONNECTIONS
CLOCK
3.3V on PDB comes from 3V3_EPS
3V3_EPS
5V_PAY
VDDA Filtering
Load Capacitance = (12.5-5)*2 = 15pF [12.5pF (Datasheet) - Stray Capacitance (approx 5pF)]*2
VIN = 7.4 V VOUT = 5 V IOUT (Max) = 2A IOUT (Min) = 0A f = 2.25 MHz
Try to use pads to solder connections instead of jumpers
For fixed VOUT options, connect FB pin directly to VOUT.
EPS DISTRIBUTION & REGULATION UNIT
Input Capacitor (CIN) Selection The input capacitance, CIN, is needed to filter the square wave current at the drain of the top power MOSFET. To prevent large voltage transients from occurring, a low ESR input capacitor sized for the maximum RMS current should be used. The maximum RMS current is gi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
3V3 REGULATOR
REPLACE INDUCTORS WITH STANDARD VALUES PACKAGES: XHMI SERIES 8080 2.2uH 8080 4.7uH 6030 8.2uH 5050
PGOOD externally pull up
REF pin consumes 0.5uA current
Digital input used to reset the ADC to its power-on-reset status. This pin has a weak pull-up internally to DVDD
5V REGULATOR
3V3_ADCS
15mA > (3.3-1.25)/R > 10uA (min input current) 136.67 Ohm < R < 205 kOhm
CURRENT LIMITER
32.768 kHz CLK
HARSHIL SINGLA

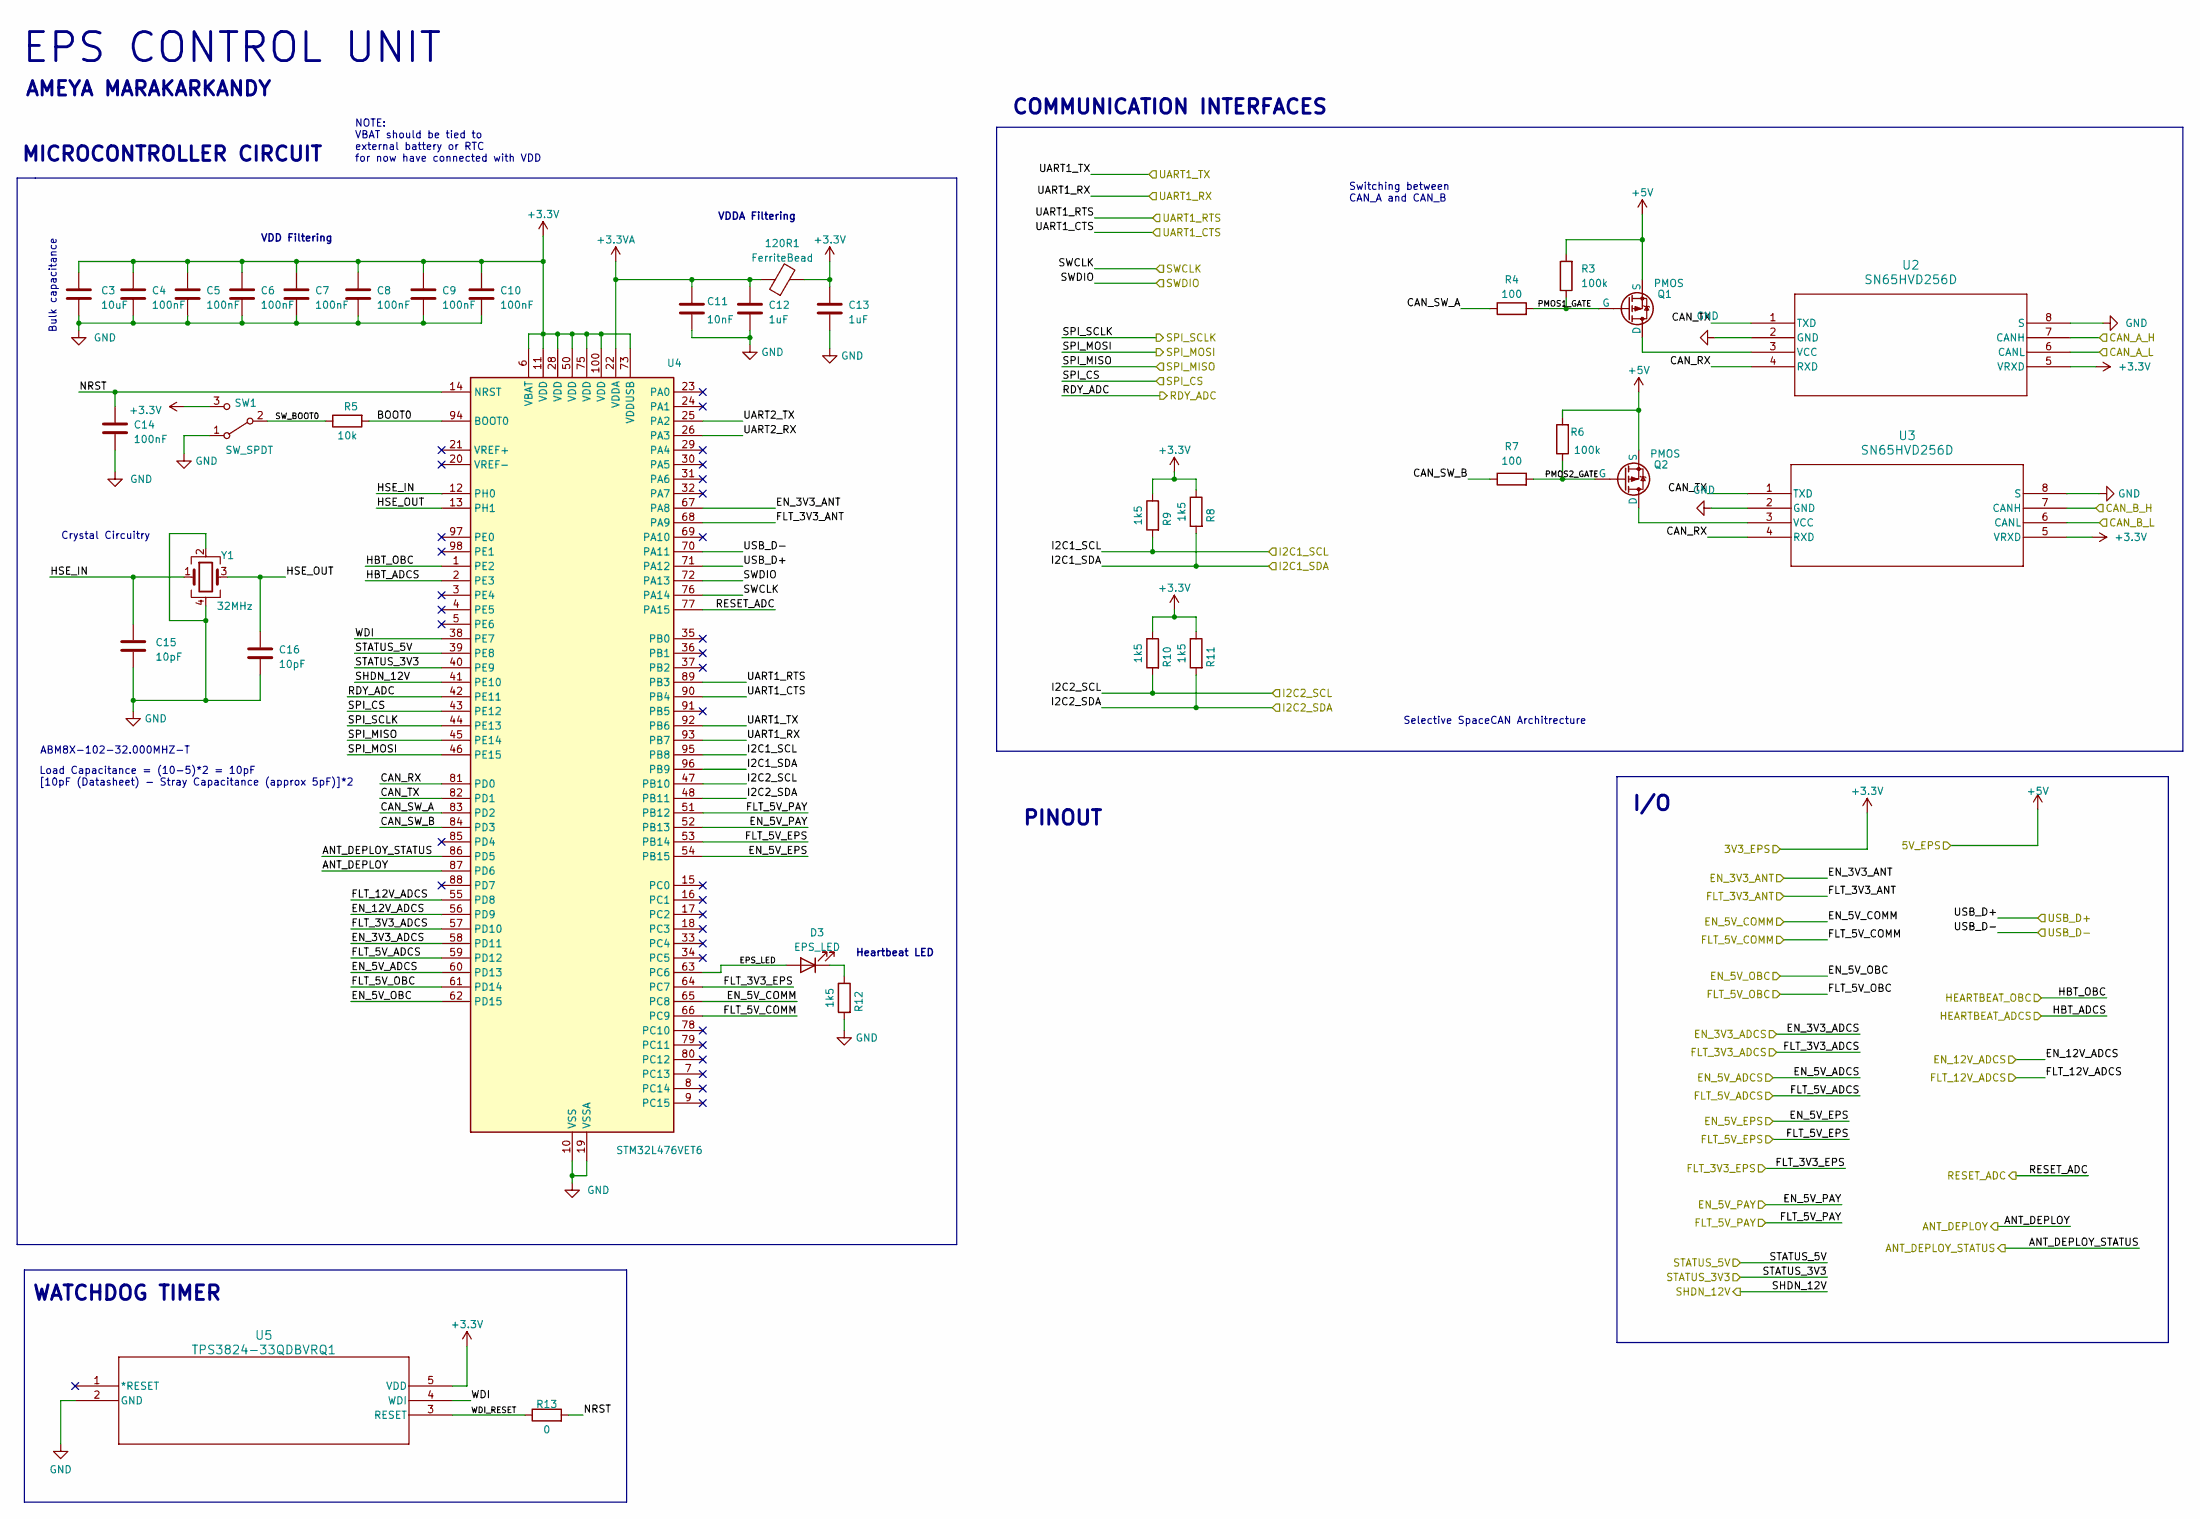
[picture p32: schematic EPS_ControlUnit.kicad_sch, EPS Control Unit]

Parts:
120R1: FerriteBead; R_0805_2012Metric
C3: 10uF; C_0603_1608Metric
C4, C5, C6, C7, C8, C9, C10, C14: 100nF; C_0603_1608Metric
C11: 10nF; C_0603_1608Metric
C12, C13: 1uF; C_0603_1608Metric
C15, C16: 10pF; C_0603_1608Metric
D3: EPS_LED; LED_0805_2012Metric
Q1, Q2: PMOS; SOT-23-3
R3, R6: 100k; R_0603_1608Metric
R4, R7: 100; R_0603_1608Metric
R5: 10k; R_0603_1608Metric
R8, R9, R10, R11, R12: 1k5; R_0603_1608Metric
R13: 0; R_0603_1608Metric
SW1: SW_SPDT; SW_SPST_B3U-1100P
U2, U3: SN65HVD256D; D8
U4: STM32L476VET6; LQFP-100_14x14mm_P0.5mm
U5: TPS3824-33QDBVRQ1; tps3824
Y1: 32MHz; Crystal_SMD_Abracon_ABM8AIG-4Pin_3.2x2.5mm

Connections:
3V3_EPS: 120R1.2, C3.1, C4.1, C5.1, C6.1, C7.1, C8.1, C9.1, C10.1, C13.1, R8.1, R9.1, R10.1, R11.1, SW1.3 (C), U2.5 (VRXD), U3.5 (VRXD), U4.6 (VBAT), U4.11 (VDD), U4.28 (VDD), U4.50 (VDD), U4.73 (VDDUSB), U4.75 (VDD), U4.100 (VDD), U5.5 (VDD); also elsewhere on the board
5V_EPS: Q1.3 (S), Q2.3 (S), R3.2, R6.2; also elsewhere on the board
+3.3VA: 120R1.1, C11.1, C12.1, U4.22 (VDDA); also elsewhere on the board
/ANT_DEPLOY: U4.87 (PD6); also elsewhere on the board
/ANT_DEPLOY_STATUS: U4.86 (PD5); also elsewhere on the board
/CAN_A_H: U2.7 (CANH); also elsewhere on the board
/CAN_A_L: U2.6 (CANL); also elsewhere on the board
/CAN_B_H: U3.7 (CANH); also elsewhere on the board
/CAN_B_L: U3.6 (CANL); also elsewhere on the board
/EN_3V3_ADCS: U4.58 (PD11); also elsewhere on the board
/EN_3V3_ANT: U4.67 (PA8); also elsewhere on the board
/EN_5V_ADCS: U4.60 (PD13); also elsewhere on the board
/EN_5V_COMM: U4.65 (PC8); also elsewhere on the board
/EN_5V_EPS: U4.54 (PB15); also elsewhere on the board
/EN_5V_OBC: U4.62 (PD15); also elsewhere on the board
/EN_5V_PAY: U4.52 (PB13); also elsewhere on the board
/EN_12V_ADCS: U4.56 (PD9); also elsewhere on the board
/EPS Control Unit/BOOT0: R5.2, U4.94 (BOOT0)
/EPS Control Unit/CAN_RX: U2.4 (RXD), U3.4 (RXD), U4.81 (PD0)
/EPS Control Unit/CAN_SW_A: R4.1, U4.83 (PD2)
/EPS Control Unit/CAN_SW_B: R7.1, U4.84 (PD3)
/EPS Control Unit/CAN_TX: U2.1 (TXD), U3.1 (TXD), U4.82 (PD1)
/EPS Control Unit/EPS_LED: D3.2 (A), U2.63, U4.63 (PC6); also elsewhere on the board
/EPS Control Unit/HSE_IN: C15.1, U4.12 (PH0), Y1.1
/EPS Control Unit/HSE_OUT: C16.1, U4.13 (PH1), Y1.3
/EPS Control Unit/NRST: C14.1, R13.2, U4.14 (NRST)
/EPS Control Unit/PMOS1_GATE: Q1.2 (G), R3.1, R4.2
/EPS Control Unit/PMOS2_GATE: Q2.2 (G), R6.1, R7.2
/EPS Control Unit/SW_BOOT0: R5.1, SW1.2 (B)
/EPS Control Unit/UART2_RX: U4.26 (PA3)
/EPS Control Unit/UART2_TX: U4.25 (PA2)
/EPS Control Unit/WDI: U4.38 (PE7), U5.4 (WDI)
/EPS Control Unit/WDI_RESET: R13.1, U5.3 (RESET)
/FLT_3V3_ADCS: U4.57 (PD10); also elsewhere on the board
/FLT_3V3_ANT: U4.68 (PA9); also elsewhere on the board
/FLT_3V3_EPS: U4.64 (PC7); also elsewhere on the board
/FLT_5V_ADCS: U4.59 (PD12); also elsewhere on the board
/FLT_5V_COMM: U4.66 (PC9); also elsewhere on the board
/FLT_5V_EPS: U4.53 (PB14); also elsewhere on the board
/FLT_5V_OBC: U4.61 (PD14); also elsewhere on the board
/FLT_5V_PAY: U4.51 (PB12); also elsewhere on the board
/FLT_12V_ADCS: U4.55 (PD8); also elsewhere on the board
/HEARTBEAT_ADCS: U4.2 (PE3); also elsewhere on the board
/HEARTBEAT_OBC: U4.1 (PE2); also elsewhere on the board
/I2C1_SCL: R9.2, U4.95 (PB8); also elsewhere on the board
/I2C1_SDA: R8.2, U4.96 (PB9); also elsewhere on the board
/I2C2_SCL: R10.2, U4.47 (PB10); also elsewhere on the board
/I2C2_SDA: R11.2, U4.48 (PB11); also elsewhere on the board
/RDY_ADC: U4.42 (PE11); also elsewhere on the board
/RESET_ADC: U4.77 (PA15); also elsewhere on the board
/SHDN_12V: U4.41 (PE10); also elsewhere on the board
/SPI_CS: U4.43 (PE12); also elsewhere on the board
/SPI_MISO: U4.45 (PE14); also elsewhere on the board
/SPI_MOSI: U4.46 (PE15); also elsewhere on the board
/SPI_SCLK: U4.44 (PE13); also elsewhere on the board
/STATUS_3V3: U4.40 (PE9); also elsewhere on the board
/STATUS_5V: U4.39 (PE8); also elsewhere on the board
/SWCLK: U4.76 (PA14); also elsewhere on the board
/SWDIO: U4.72 (PA13); also elsewhere on the board
/UART1_CTS: U4.90 (PB4); also elsewhere on the board
/UART1_RTS: U4.89 (PB3); also elsewhere on the board
/UART1_RX: U4.93 (PB7); also elsewhere on the board
/UART1_TX: U4.92 (PB6); also elsewhere on the board
/USB_D+: U4.71 (PA12); also elsewhere on the board
/USB_D-: U4.70 (PA11); also elsewhere on the board
GND: C3.2, C4.2, C5.2, C6.2, C7.2, C8.2, C9.2, C10.2, C11.2, C12.2, C13.2, C14.2, C15.2, C16.2, R12.2, SW1.1 (A), U2.2 (GND), U2.8 (S), U3.2 (GND), U3.8 (S), U4.10 (VSS), U4.19 (VSSA), U4.27 (VSS), U4.49 (VSS), U4.74 (VSS), U4.99 (VSS), U5.2 (GND), Y1.2, Y1.4; also elsewhere on the board
unnamed 109: R12.1; also elsewhere on the board
unnamed: Q1.1 (D), U2.3 (VCC)
unnamed: Q2.1 (D), U3.3 (VCC)

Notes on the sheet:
WATCHDOG TIMER
Bulk capacitance
COMMUNICATION INTERFACES
Switching between CAN_A and CAN_B
VDD Filtering
ABM8X-102-32.000MHZ-T
Load Capacitance = (10-5)*2 = 10pF [10pF (Datasheet) - Stray Capacitance (approx 5pF)]*2
NOTE: VBAT should be tied to external battery or RTC for now have connected with VDD
MICROCONTROLLER CIRCUIT
Crystal Circuitry
EPS CONTROL UNIT
AMEYA MARAKARKANDY
PINOUT
Heartbeat LED
VDDA Filtering
I/O
Selective SpaceCAN Architrecture

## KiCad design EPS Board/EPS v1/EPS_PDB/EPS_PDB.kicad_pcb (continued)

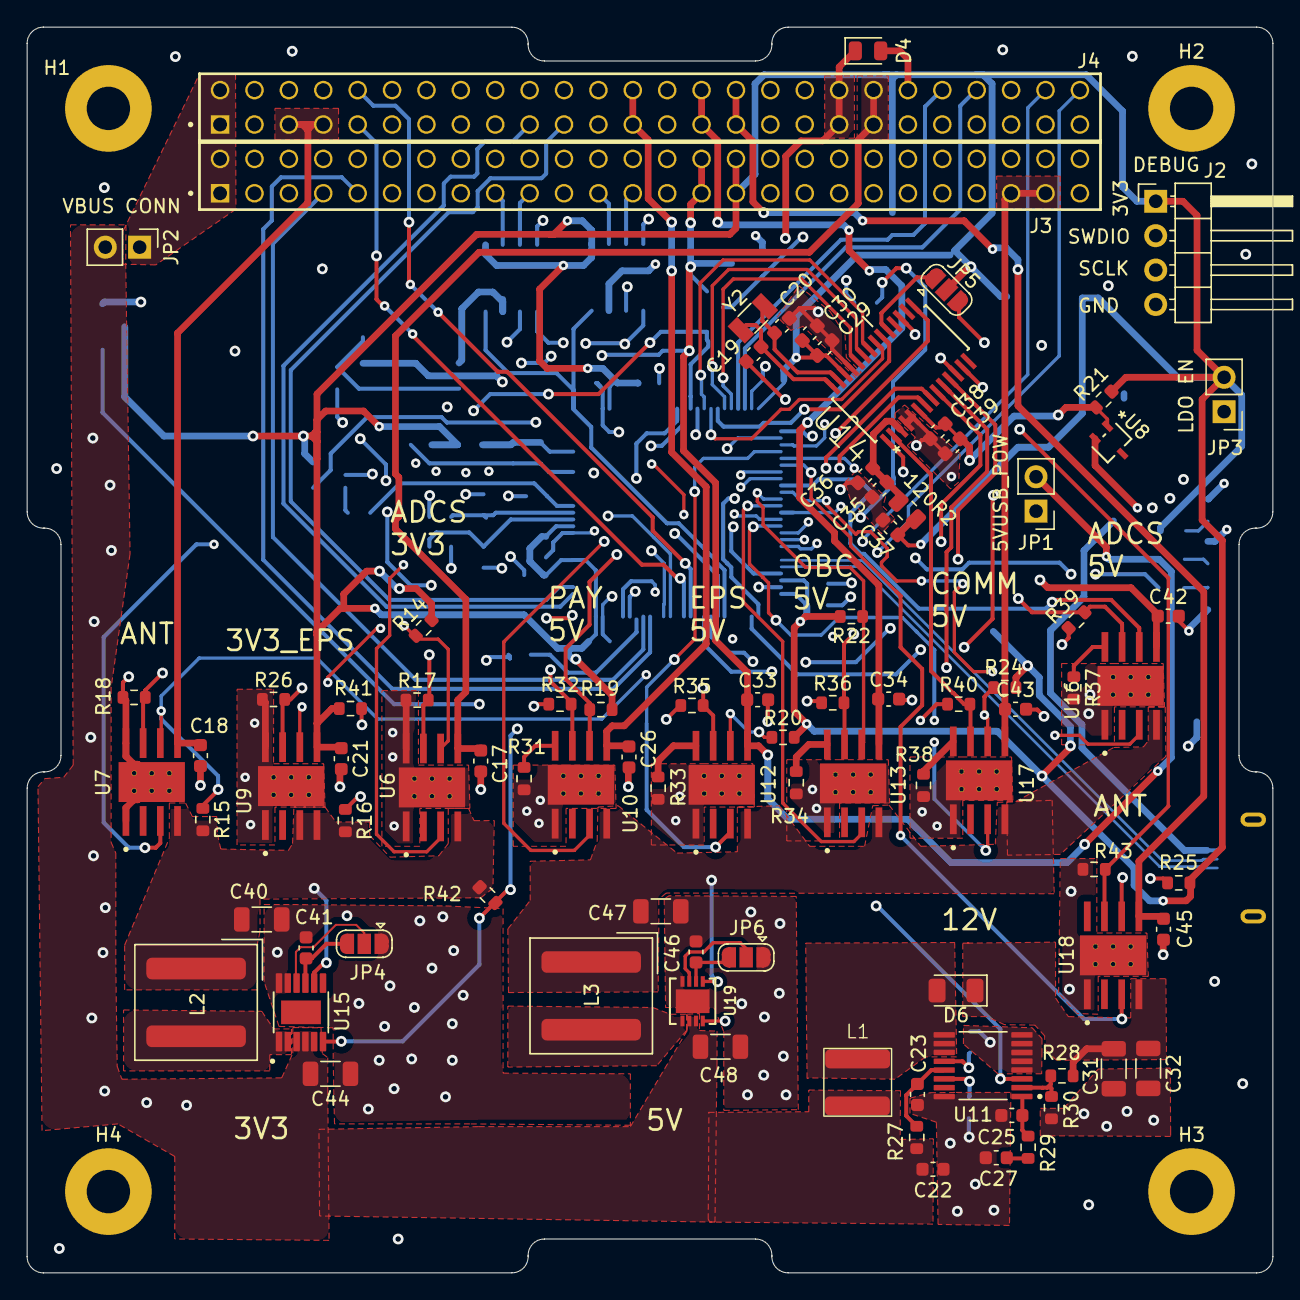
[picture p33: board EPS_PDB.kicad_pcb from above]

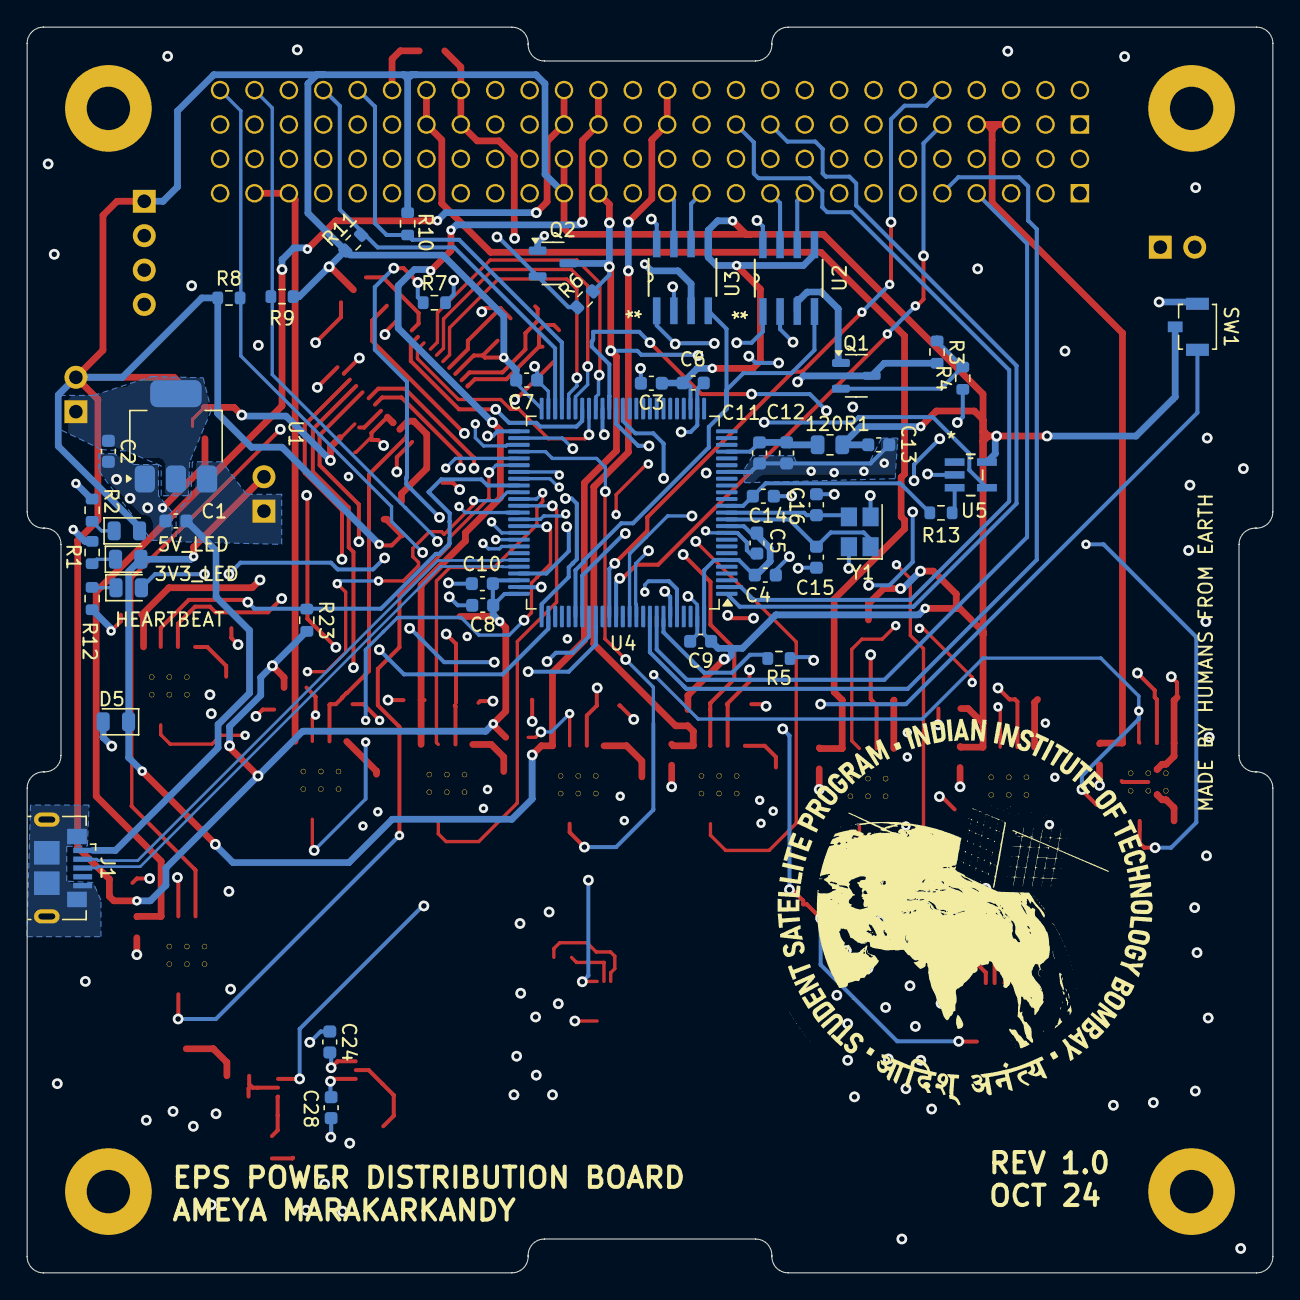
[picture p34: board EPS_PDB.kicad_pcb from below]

Board: 4 copper layers, 92.0 x 92.0 mm, 140 parts (47 on the bottom side), 113 nets.

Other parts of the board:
3V3_LED: EPS_5V_LED; LED_0805_2012Metric
5V_LED: EPS_3V3_LED; LED_0805_2012Metric
HEARTBEAT: EPS_LED; LED_0805_2012Metric

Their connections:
3V3_EPS: 5V_LED.2 (A); also elsewhere on the board
5V_EPS: 3V3_LED.2 (A); also elsewhere on the board
/EPS Control Unit/EPS_LED: HEARTBEAT.2 (A); also elsewhere on the board
/LED_CATHODE: 5V_LED.1 (K); also elsewhere on the board
unnamed 108: 3V3_LED.1 (K); also elsewhere on the board
unnamed 109: HEARTBEAT.1 (K); also elsewhere on the board

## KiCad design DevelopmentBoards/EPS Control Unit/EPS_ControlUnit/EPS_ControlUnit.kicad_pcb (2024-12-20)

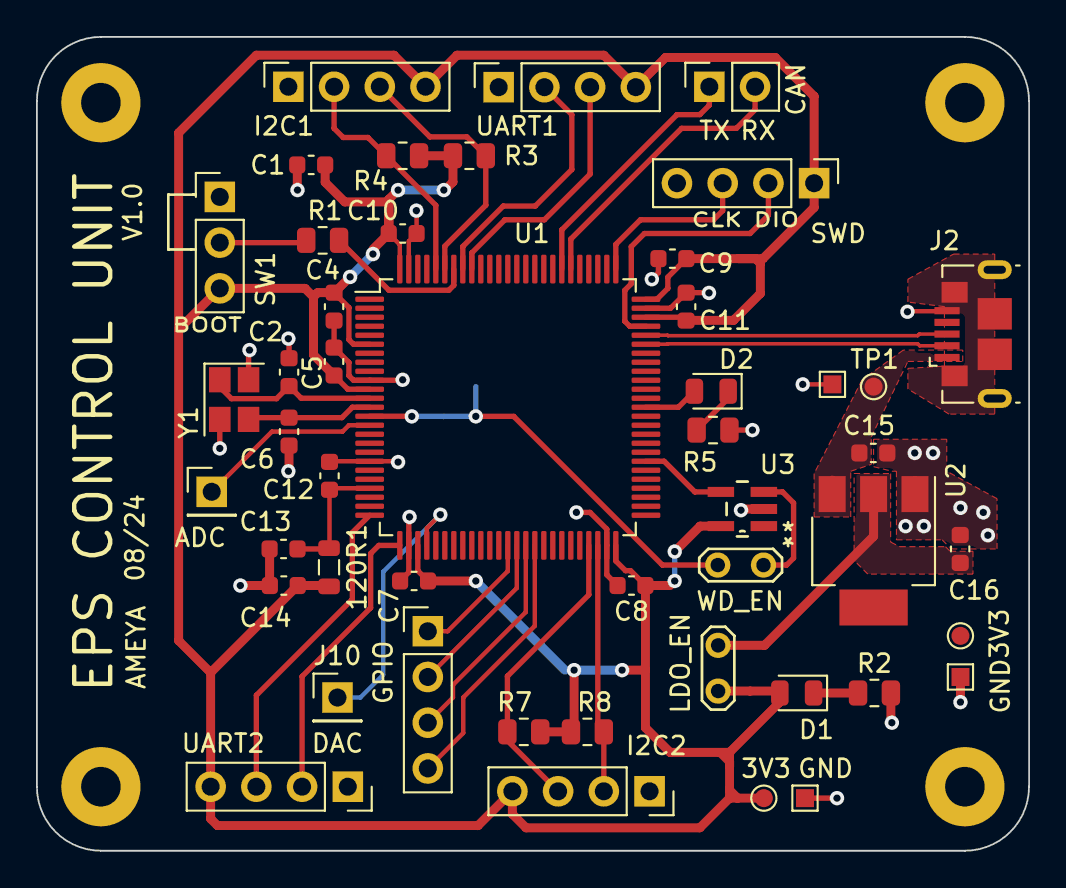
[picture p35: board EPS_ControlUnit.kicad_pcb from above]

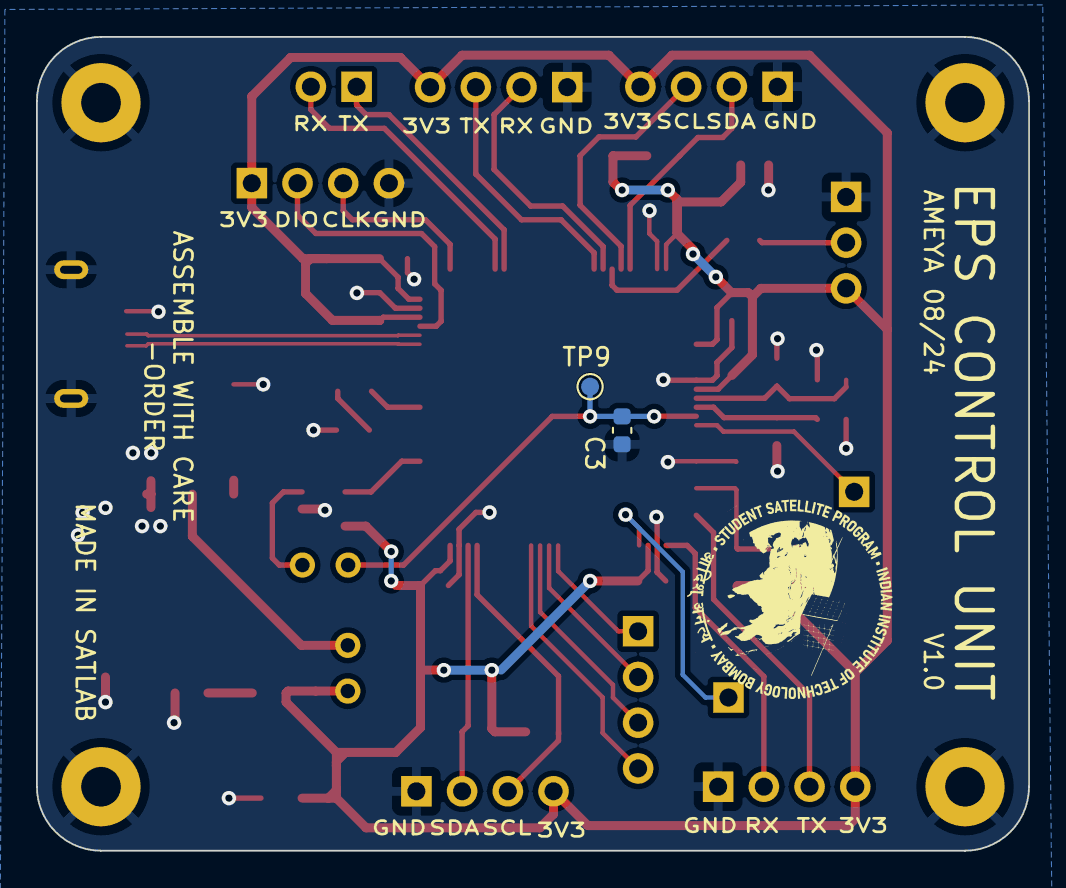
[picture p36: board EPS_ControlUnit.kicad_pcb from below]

Board: 2 copper layers, 55.1 x 45.2 mm, 54 parts (2 on the bottom side), 35 nets.

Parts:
3V3, 3V3#2: TestPoint; TestPoint_Pad_D1.0mm
120R1: FerriteBead; L_0805_2012Metric
C1: 10uF; C_0603_1608Metric
C2, C6: 10pF; C_0603_1608Metric
C3, C4, C5, C7, C8, C9, C10, C11: 100nF; C_0603_1608Metric
C12: 10nF; C_0603_1608Metric
C13, C14: 1uF; C_0603_1608Metric
C15, C16: 22uF; C_0603_1608Metric
D1: POWER_LED; LED_0805_2012Metric
D2: EPS_LED; LED_0805_2012Metric
GND: TestPoint; TestPoint_Pad_1.0x1.0mm
GND#2: TestPoint; TestPoint_Pad_1.0x1.0mm
H1, H2, H3, H4: MountingHole_Pad; MountingHole_2.2mm_M2_Pad
J1, J8: Conn_01x04_Pin; PinHeader_1x04_P2.54mm_Vertical
J2: USB_B_Micro; USB_Micro-B_GCT_USB3076-30-A
J3, J4, J5, J6: Conn_01x04_Pin; PinSocket_1x04_P2.54mm_Vertical
J7: Conn_01x02_Pin; PinSocket_1x02_P2.54mm_Vertical
J9, J10: Conn_01x01_Pin; PinHeader_1x01_P2.54mm_Vertical
LDO_EN: Jumper_2_Bridged; TestPoint_2Pads_Pitch2.54mm_Drill0.8mm
R1: 10k; R_0805_2012Metric
R2, R3, R4, R5, R7, R8: 1k5; R_0805_2012Metric
SW1: SW_SPDT; PinHeader_1x03_P2.54mm_Vertical
TP1, TP9: TestPoint; TestPoint_Pad_D1.0mm
TP2: TestPoint; TestPoint_Pad_1.0x1.0mm
U1: STM32L476VET6; LQFP-100_14x14mm_P0.5mm
U2: AMS1117-3.3; SOT-223-3_TabPin2
U3: TPS3824-33QDBVRQ1; tps3824
WD_EN: Jumper_2_Bridged; TestPoint_2Pads_Pitch2.54mm_Drill0.8mm
Y1: 32MHz; Crystal_SMD_Abracon_ABM8AIG-4Pin_3.2x2.5mm

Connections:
3V3_EPS: 3V3.1, 120R1.2, C1.1, C4.1, C5.1, C7.1, C8.1, C9.1, C10.1, C11.1, C14.1, D1.2 (A), J1.1, J3.4, J4.4, J5.4, J6.4, LDO_EN.2 (B), R3.1, R4.1, R7.1, R8.1, SW1.3 (C), U1.6 (VBAT), U1.11 (VDD), U1.28 (VDD), U1.50 (VDD), U1.73 (VDDUSB), U1.75 (VDD), U1.100 (VDD), U3.5 (VDD)
+3.3VA: 120R1.1, C12.1, C13.1, U1.22 (VDDA)
/3V3_LDO: 3V3#2.1, C16.1, LDO_EN.1 (A), U2.2 (VO)
/ADC: J9.1, U1.15 (PC0)
/BOOT0: R1.2, U1.94 (BOOT0)
/CAN_RX: J7.2, U1.81 (PD0)
/CAN_TX: J7.1, U1.82 (PD1)
/DAC: J10.1, U1.29 (PA4)
/EPS_LED: D2.2 (A), U1.63 (PC6)
/GPIO1: J8.1, U1.38 (PE7)
/GPIO2: J8.2, U1.39 (PE8)
/GPIO3: J8.3, U1.40 (PE9)
/GPIO4: J8.4, U1.41 (PE10)
/HSE_IN: C2.1, U1.12 (PH0), Y1.1
/HSE_OUT: C6.1, U1.13 (PH1), Y1.3
/I2C1_SCL: J3.3, R3.2, U1.95 (PB8)
/I2C1_SDA: J3.2, R4.2, U1.96 (PB9)
/I2C2_SCL: J5.3, R7.2, U1.47 (PB10)
/I2C2_SDA: J5.2, R8.2, U1.48 (PB11)
/LED_CATHODE: D1.1 (K), R2.1
/NRST: C3.1, TP9.1, U1.14 (NRST), WD_EN.2 (B)
/SWCLK: J1.3, U1.76 (PA14)
/SWDIO: J1.2, U1.72 (PA13)
/SW_BOOT0: R1.1, SW1.2 (B)
/UART1_RX: J4.2, U1.93 (PB7)
/UART1_TX: J4.3, U1.92 (PB6)
/UART2_RX: J6.2, U1.26 (PA3)
/UART2_TX: J6.3, U1.25 (PA2)
/USB_D+: J2.3 (D+), U1.71 (PA12)
/USB_D-: J2.2 (D-), U1.70 (PA11)
/WDI: U1.57 (PD10), U3.4 (WDI)
/WDI_RESET: U3.3 (RESET), WD_EN.1 (A)
GND: C1.2, C2.2, C3.2, C4.2, C5.2, C6.2, C7.2, C8.2, C9.2, C10.2, C11.2, C12.2, C13.2, C14.2, C15.2, C16.2, GND.1, GND#2.1, H1.1, H2.1, H3.1, H4.1, J1.4, J2.5 (GND), J2.6 (Shield), J3.1, J4.1, J5.1, J6.1, R2.2, R5.2, SW1.1 (A), TP2.1, U1.10 (VSS), U1.19 (VSSA), U1.27 (VSS), U1.49 (VSS), U1.74 (VSS), U1.99 (VSS), U2.1 (GND), U3.2 (GND), Y1.2, Y1.4
unnamed: D2.1 (K), R5.1
VBUS: C15.1, J2.1 (VBUS), TP1.1, U2.3 (VI)

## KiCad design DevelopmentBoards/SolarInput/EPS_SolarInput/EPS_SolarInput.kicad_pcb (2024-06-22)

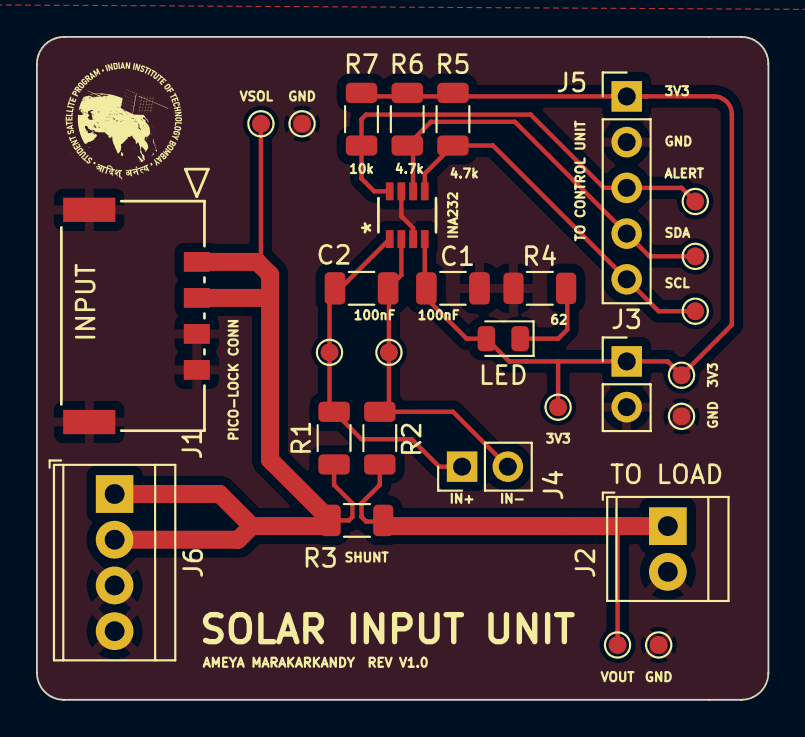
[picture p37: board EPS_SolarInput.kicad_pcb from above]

Board: 2 copper layers, 40.6 x 36.8 mm, 29 parts (0 on the bottom side), 10 nets.

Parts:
C1: 100nF; C_1206_3216Metric
C2: C2; C_1206_3216Metric
D1: LED; LED_0805_2012Metric
GND: TestPoint; TestPoint_Pad_D1.0mm
INA232: INA232AIDDFR; SOT_32AIDDFR_TEX
J1: 2053380004; CON_2053380004
J2: Screw_Terminal_01x02; TerminalBlock_TE_282834-2_1x02_P2.54mm_Horizontal
J3, J4: Conn_01x02_Socket; PinHeader_1x02_P2.54mm_Vertical
J5: Conn_01x05_Pin; PinHeader_1x05_P2.54mm_Vertical
J6: Screw_Terminal_01x04; TerminalBlock_TE_282834-4_1x04_P2.54mm_Horizontal
R1, R2: <100; R_1206_3216Metric
R3: 40m; R_1206_3216Metric
R4: 62; R_1206_3216Metric
R5, R6: 4.7k; R_1206_3216Metric
R7: 10k; R_1206_3216Metric
TP1, TP2, TP3, TP4, TP5, TP6, TP7, TP8, TP9, TP10: TestPoint; TestPoint_Pad_D1.0mm
VOUT: TestPoint; TestPoint_Pad_D1.0mm

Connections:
+3.3V: C1.2, D1.2 (A), INA232.4 (VS), J3.1, J5.1, R5.1, R6.1, R7.1, TP3.1, TP10.1
/ALERT: INA232.8 (ALERT), J5.3, R7.2, TP8.1
/I2C_SCL: INA232.5 (SCL), J5.5, R5.2, TP6.1
/I2C_SDA: INA232.6 (SDA), J5.4, R6.2, TP7.1
/VSOL: J1.1, J1.2, J6.1, J6.2, R1.1, R3.1, TP1.1
GND: C1.1, GND.1, INA232.3 (GND), INA232.7 (A0), J1.3, J1.4, J1.5, J1.6, J2.2, J3.2, J5.2, J6.3, J6.4, R4.1, TP2.1, TP9.1
unnamed: D1.1 (K), R4.2
unnamed: J2.1, R2.1, R3.2, VOUT.1
unnamed: C2.2, INA232.1 (IN+), J4.1, R1.2, TP4.1
unnamed: C2.1, INA232.2 (IN-), J4.2, R2.2, TP5.1

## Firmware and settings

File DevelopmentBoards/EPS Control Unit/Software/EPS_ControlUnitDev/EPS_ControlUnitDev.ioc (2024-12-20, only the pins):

Mcu.UserName=STM32L476VETx
PA11.Signal=USB_OTG_FS_DM
PA12.Signal=USB_OTG_FS_DP
PA2.Signal=USART2_TX
PA3.Signal=USART2_RX
PB10.Signal=I2C2_SCL
PB11.Signal=I2C2_SDA
PB6.Signal=USART1_TX
PB7.Signal=USART1_RX
PB8.Signal=I2C1_SCL
PB9.Signal=I2C1_SDA
PC6.GPIO_Label=EPS_LED
PC6.Signal=GPIO_Output
PD0.Signal=CAN1_RX
PD1.Signal=CAN1_TX
PE10.Signal=GPIO_Output
PE7.Signal=GPIO_Output
PE8.Signal=GPIO_Output
PE9.Signal=GPIO_Output

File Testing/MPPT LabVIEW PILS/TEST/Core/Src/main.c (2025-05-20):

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
/* Includes ------------------------------------------------------------------*/
#include "main.h"

/* USER CODE BEGIN Includes */
#include <string.h>
#include "mppt.h"
#include <stdio.h>
#include <stdlib.h>
/* USER CODE END Includes */

UART_HandleTypeDef huart2;

/* USER CODE BEGIN PV */
MPPT_t mppt;

uint8_t rx_byte;
char uart_rx_buffer[128];
char uart_tx_buffer[128];
volatile uint8_t idx = 0;
volatile uint8_t line_received = 0;
/* USER CODE END PV */

void SystemClock_Config(void);
static void MX_GPIO_Init(void);
static void MX_USART2_UART_Init(void);
/* USER CODE BEGIN 0 */

/**
  * @brief Callback that is called when a UART byte is received via interrupt.
  *        It accumulates bytes into uart_rx_buffer until a newline is received.
*/

void HAL_UART_RxCpltCallback(UART_HandleTypeDef *huart)
{
  if (huart->Instance == USART2)
  {
    //char dbg[32];
    //snprintf(dbg, sizeof(dbg), "Got: 0x%02X\r\n", rx_byte);
    //HAL_UART_Transmit(&huart2, (uint8_t*)dbg, strlen(dbg), HAL_MAX_DELAY);
    if (rx_byte == '\n' || rx_byte == '\r') {
      uart_rx_buffer[idx++] = '\n';
      uart_rx_buffer[idx] = '\0';
      line_received = 1;
    }
    else {
      if (idx < sizeof(uart_rx_buffer) - 1) {
        uart_rx_buffer[idx++] = rx_byte;
      } else {
        idx = 0;  // overflow protection
      }
    }
    HAL_GPIO_TogglePin(B1_GPIO_Port, B1_Pin);
    // Restart reception
    HAL_UART_Receive_IT(&huart2, &rx_byte, 1);  
  }
}
/* USER CODE END 0 */
int main(void)
{
  /* MCU Configuration--------------------------------------------------------*/

  /* Reset of all peripherals, Initializes the Flash interface and the Systick. */
  HAL_Init();

  /* Configure the system clock */
  SystemClock_Config();

  /* Initialize all configured peripherals */
  MX_GPIO_Init();
  MX_USART2_UART_Init();

  /* USER CODE BEGIN 2 */
  MPPT_Init(&mppt);
  // Start interrupt-based receive
  
  HAL_UART_Receive_IT(&huart2, &rx_byte, 1);
  
  /* USER CODE END 2 */

  /* Infinite loop */
  /* USER CODE BEGIN WHILE */
  while (1)
  {
    if(line_received)
    {
    float voltage = 0.0f, current = 0.0f;
    //char debug_buff[64];
    // Look for 'v' and 'i' in the buffer
    char *v_ptr = strchr((char*)uart_rx_buffer,'v');  // or 'V'
    char *i_ptr = strchr((char*)uart_rx_buffer, 'i');  // or 'I'

      if (v_ptr && i_ptr){
        voltage = strtof(v_ptr + 1, NULL);  // text after 'v'
        current = strtof(i_ptr + 1, NULL);  // text after 'i'

        //snprintf(debug_buff, sizeof(debug_buff), "V=%.2f I=%.2f\r\n", voltage, current);
        //HAL_UART_Transmit(&huart2, (uint8_t *)uart_rx_buffer, idx, HAL_MAX_DELAY);
        idx = 0;
        line_received = 0;

        // Call your MPPT logic here (if needed)
        MPPT_Update(&mppt, voltage, current);

        // Send back the computed duty cycle
        snprintf(uart_tx_buffer, sizeof(uart_tx_buffer), "%.2f", mppt.duty_cycle);
        HAL_UART_Transmit(&huart2, (uint8_t *)uart_tx_buffer, strlen(uart_tx_buffer), HAL_MAX_DELAY);
      }
      else
      {
          const char *error = "Parse error: V= or I= not found\n";
          HAL_UART_Transmit(&huart2, (uint8_t *)error, strlen(error), HAL_MAX_DELAY);
          idx = 0;
          line_received = 0;
      }

      HAL_UART_Transmit(&huart2, (uint8_t*)uart_rx_buffer, idx, HAL_MAX_DELAY);

    }
    HAL_GPIO_TogglePin(LD2_GPIO_Port,LD2_Pin);
    HAL_Delay(500);
  }
  /* USER CODE END WHILE */

}

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


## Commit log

2024-06-20 Started Schematic of Solar Input Development Board
    [EPS_SolarInput.kicad_pcb, EPS_SolarInput.kicad_sch]
2024-06-21 Completed EPS Solar Input Schematic
    [EPS_SolarInput.csv, EPS_SolarInput.kicad_pcb, EPS_SolarInput.kicad_sch]
2024-06-22 Completed PCB Design for Solar Input Unit Development Board
    [EPS_SolarInput-B_Cu.gbr, EPS_SolarInput-B_Mask.gbr, EPS_SolarInput-B_Paste.gbr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]
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2024-06-22 README update
    Added progress in README
    [EPS_SolarInput.csv]
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2024-07-16 Started working on EPS Battery Unit Dev Board
    [BatteryUnit.kicad_pcb, BatteryUnit.kicad_sch, batt_charging.kicad_sch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]
2024-07-18 EPS Final Board
    Started EPS final board schematic
    yet to add dependencies of external libraries to a common folder on GitHub
    [IITBSSP_EPS.kicad_pcb, IITBSSP_EPS.kicad_sch, batt_charging.kicad_sch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]
2024-08-18 Started EPS Control unit design
    [eps_control.kicad_sch]
2024-08-19 EPS Control Unit Dev and Final Schematic designed
    [IITBSSP_EPS.kicad_sch, eps_control.kicad_sch, power_distribution.kicad_sch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]
2024-08-20 EPS Control Unit Dev Board development
    [EPS_ControlUnit.kicad_pcb, EPS_ControlUnit.kicad_sch]
2024-08-29 EPS Control Unit Rough layout done
    [EPS_ControlUnit.kicad_pcb, EPS_ControlUnit.kicad_sch]
2024-08-30 EPS Control Unit Dev Board Completed
    [EPS_ControlUnit-B_Cu.gbr, EPS_ControlUnit-B_Mask.gbr, EPS_ControlUnit-B_Paste.gbr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]
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2024-09-03 Final changes to EPS Control unit dev board
    Added pinouts for ADC and DAC
    Sent EPS Control unit for manufacturing
    Started designing EPS PDB Board (Control Unit + Power Distribution and Regulation)
    [EPS_ControlUnit-B_Cu.gbr, EPS_ControlUnit-B_Mask.gbr, EPS_ControlUnit-B_Paste.gbr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]
2024-09-04 Modified EPS Power Distribution and Regulation Schematic
    [EPS_PDB.kicad_sch, EPS_PowerDistribution.kicad_sch]
2024-09-04 Modification of interfaces of EPS Control unit
    [EPS_ControlUnit.kicad_sch, EPS_PDB.kicad_sch]
2024-09-04 Updated Schematic page settings
    [EPS_PowerDistribution.kicad_sch]
2024-09-05 EPS PDB Board Schematic progress
    Interfaces defined in EPS PDB board Schematic
    [EPS_ControlUnit.kicad_sch, EPS_PDB.kicad_sch, EPS_PowerDistribution.kicad_sch]
2024-09-06 EPS PDB Schematic Progress
    Assigned STM32 GPIO pins
    [EPS_ControlUnit.kicad_sch, EPS_PDB.kicad_sch]
2024-09-08 Fixed libraries and updated schematic accordingly
    [EPS_PDB.kicad_sch, EPS_PowerDistribution.kicad_sch]
2024-09-08 Added PCB dxf outline
    [EPS_ControlUnit.kicad_sch, EPS_PDB.kicad_pcb, EPS_PDB.kicad_sch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]
2024-09-08 completed CAN transceiver switching circuit
    [EPS_ControlUnit.kicad_sch, EPS_PDB.kicad_sch]
2024-09-09 Updated to KiCAD 8.0
    [EPS_ControlUnit.kicad_sch, EPS_PDB.kicad_pcb, EPS_PDB.kicad_sch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]
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2024-09-09 Power Distri & Reg Schematic Complete
    [EPS_PowerDistribution.kicad_sch]
2024-09-10 Changed CAN Transceiver IC
    Chose an ic which can operate at 5V Vcc and 3.3V logic
    [EPS_ControlUnit.kicad_sch]
2024-09-10 Added ADC to schematic
    [EPS_PowerDistribution.kicad_sch]
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2024-09-11 Updated labels from nets
    [EPS_PowerDistribution.kicad_sch]
2024-09-11 Bus Pin Definitions added
    [EPS_PDB.kicad_sch]
2024-09-11 Pin definitions of regulaton unit added to root and final changes commments added
    [EPS_ControlUnit.kicad_sch, EPS_PDB.kicad_sch, EPS_PowerDistribution.kicad_sch]
2024-09-11 Added Heartbeat GPIOs from ADCS and OBC
    [EPS_PDB.kicad_sch]
2024-09-12 Interfaced Control and PD&R unit
    [EPS_ControlUnit.kicad_sch, EPS_PDB.kicad_sch, EPS_PowerDistribution.kicad_sch]
2024-09-14 Reference voltage ic, clock, ADC schematic done
    [EPS_ControlUnit.kicad_sch, EPS_PDB.kicad_sch, EPS_PowerDistribution.kicad_sch]
2024-09-15 organise datasheet, add datasheet
    Added datasheet of the battery heater components.
    Renamed all the datasheets to show their short description.
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2024-09-17 Created and added the dev board containing all voltage regulators and a current limiter
    [PDB_Dev_Board.kicad_pcb, PDB_Dev_Board.kicad_sch]
2024-09-19 Revert "Created and added the dev board containing all voltage regulators and a current limiter"
    This reverts commit 38ca713cce1d75051128b490c7247f66081c7b0c.
    [PDB_Dev_Board.kicad_pcb, PDB_Dev_Board.kicad_sch]
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2024-09-20 Changed PDB dev board location to correct directory
    [PDB_Dev_Board.kicad_pcb, PDB_Dev_Board.kicad_sch]
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2024-09-22 Started EPS PDB PCB Layout
    Modified footprint of PC104 Bus
    [EPS_PDB.kicad_pcb, EPS_PDB.kicad_sch]
2024-09-22 PDB PCB Design Progress
    Board outline copy pasted from Antenna Deployment Board
    Added current limiter datasheet
    Routed USB differential pair
    [EPS_ControlUnit.kicad_sch, EPS_PDB.kicad_pcb, EPS_PDB.kicad_sch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]
2024-09-28 Corrected mistake in USB+LDO circuit on schematic
    [EPS_PDB.kicad_sch]
2024-10-04 EPS PDB Board Layout Progress
    Fixed issue with outline,
    added correct outline
    [EPS_ControlUnit.kicad_sch, EPS_PDB.kicad_pcb, EPS_PDB.kicad_sch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]
2024-10-05 EPS PDB Layout
    Power Distribution and Regulation unit layout started
    [EPS_ControlUnit.kicad_sch, EPS_PDB.kicad_pcb, EPS_PowerDistribution.kicad_sch]
2024-10-06 Progresss in EPS PDB Layout
    Voltage Converters and Current limiter section pending
    Might need to increase trace width of power traces on inner layers
    [EPS_ControlUnit.kicad_sch, EPS_PDB.kicad_pcb, EPS_PDB.kicad_sch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]
2024-10-07 EPS PDB Layout Progress
    Voltage Converter layout pending
    [EPS_PDB.kicad_pcb, EPS_PowerDistribution.kicad_sch]
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2024-10-16 Assigned all footprints correctly
    [EPS_PowerDistribution.kicad_sch]
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2024-10-20 EPS PDB Layout almost complete
    Silkscreen and some minor DRC Issues to be sorted
    [EPS_ControlUnit.kicad_sch, EPS_PDB.kicad_pcb, EPS_PDB.kicad_sch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]
2024-10-20 EPS PDB Layout Complete
    Have ordered the board
    [EPS_PDB-B_Cu.gbr, EPS_PDB-B_Mask.gbr, EPS_PDB-B_Paste.gbr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]
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2024-12-20 EPS Control Unit Dev Board Software
    Added LED blinking code (EPS_LED) for EPS Control unit development Board.
    [EPS_ControlUnit.kicad_pcb, EPS_ControlUnit.kicad_sch]
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

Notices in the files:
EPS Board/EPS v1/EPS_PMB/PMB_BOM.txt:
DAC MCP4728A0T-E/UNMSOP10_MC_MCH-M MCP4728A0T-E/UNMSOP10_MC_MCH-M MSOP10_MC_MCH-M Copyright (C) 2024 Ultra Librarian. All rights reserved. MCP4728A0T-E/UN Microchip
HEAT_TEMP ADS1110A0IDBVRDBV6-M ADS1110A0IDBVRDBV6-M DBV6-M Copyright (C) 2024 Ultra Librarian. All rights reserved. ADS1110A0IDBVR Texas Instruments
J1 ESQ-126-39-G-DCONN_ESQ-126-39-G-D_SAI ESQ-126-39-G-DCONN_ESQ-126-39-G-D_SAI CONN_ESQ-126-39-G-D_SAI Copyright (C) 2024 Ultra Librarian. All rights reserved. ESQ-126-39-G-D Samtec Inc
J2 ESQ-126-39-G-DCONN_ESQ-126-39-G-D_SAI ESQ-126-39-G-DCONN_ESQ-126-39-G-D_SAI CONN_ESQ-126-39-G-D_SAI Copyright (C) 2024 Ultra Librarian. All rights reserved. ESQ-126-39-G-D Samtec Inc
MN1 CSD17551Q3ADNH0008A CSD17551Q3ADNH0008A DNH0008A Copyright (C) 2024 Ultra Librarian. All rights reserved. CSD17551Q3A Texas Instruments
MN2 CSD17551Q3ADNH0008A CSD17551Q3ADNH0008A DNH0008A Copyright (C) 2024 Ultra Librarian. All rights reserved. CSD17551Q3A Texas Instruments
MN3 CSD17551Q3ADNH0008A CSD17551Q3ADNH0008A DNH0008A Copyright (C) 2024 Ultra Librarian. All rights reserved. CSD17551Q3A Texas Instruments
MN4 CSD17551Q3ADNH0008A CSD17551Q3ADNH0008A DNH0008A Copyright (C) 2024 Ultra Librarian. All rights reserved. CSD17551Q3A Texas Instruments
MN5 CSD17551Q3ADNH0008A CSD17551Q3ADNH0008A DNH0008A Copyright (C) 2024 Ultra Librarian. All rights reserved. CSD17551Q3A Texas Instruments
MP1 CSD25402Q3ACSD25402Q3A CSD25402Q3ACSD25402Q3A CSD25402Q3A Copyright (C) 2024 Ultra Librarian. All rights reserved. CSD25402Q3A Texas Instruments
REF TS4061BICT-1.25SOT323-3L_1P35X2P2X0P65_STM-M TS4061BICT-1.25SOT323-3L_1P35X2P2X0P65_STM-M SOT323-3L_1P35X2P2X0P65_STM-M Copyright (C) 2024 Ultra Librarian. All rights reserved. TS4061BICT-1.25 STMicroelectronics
